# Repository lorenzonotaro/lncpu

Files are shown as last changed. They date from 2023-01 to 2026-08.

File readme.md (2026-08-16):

# lncpu

LNCPU is a design for a hobby 8-bit processor. 

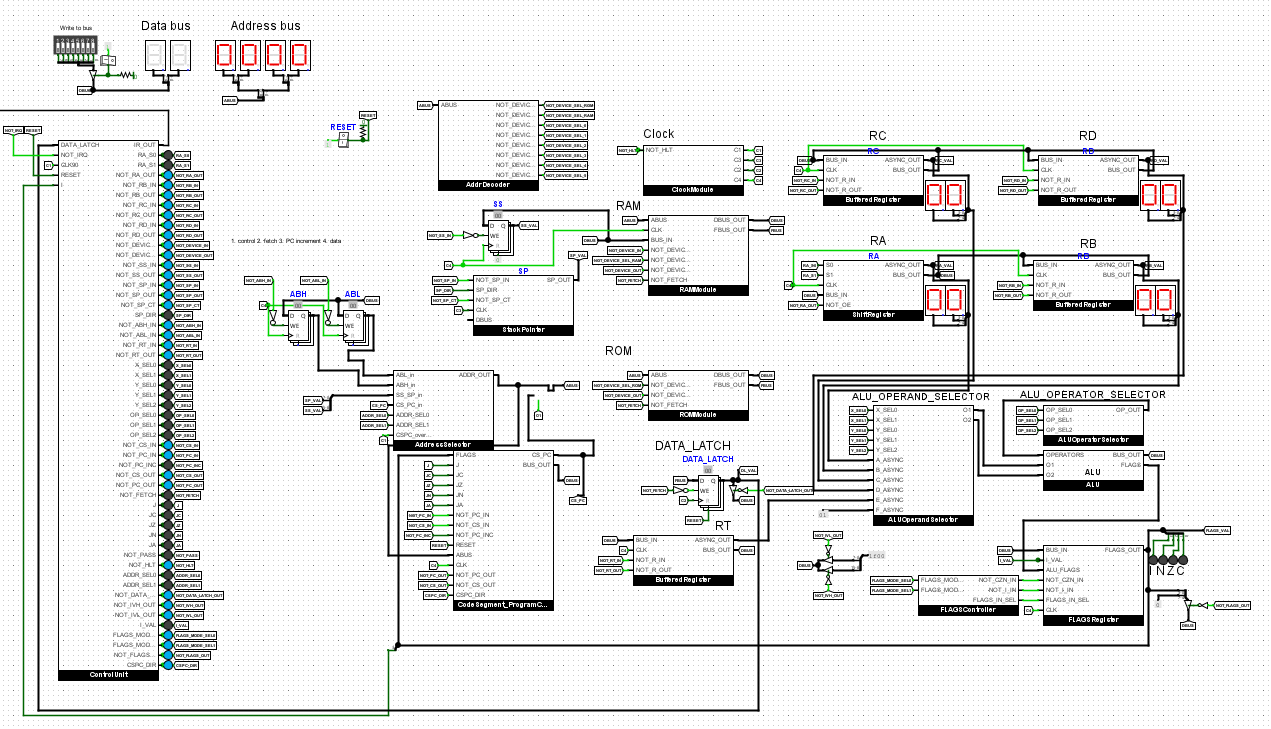
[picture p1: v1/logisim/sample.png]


## Project structure

Overview of the repository:
* [`v1`](v1) is the first implementation of the lncpu. Here you will find the Logisim simulation and the KiCad project (currently under construction), as well as the Python script for generating the control unit EEPROMS.

* [`lnc`](lnc) is an assembler and C compiler written in Java for the lncpu. It is kept up to date with the current implementation.

* [`eeprom-serial-loader`](eeprom-serial-loader) is a utility program for editing binary data and loading it to/from EEPROMS.

* [`lncpu-emu`](lncpu-emu) is a simple emulator for the lncpu written in C.

* [`lnfsutils`](lnfsutils) is a utility program for working with the lnfs filesystem, a simple FS designed to work on the lncpu.

* [`Programs`](Programs) contains some sample programs you can assemble and run on the lncpu as well as Notmon, a utility program strongly inspired in its functionality (and name) by Wozmon, made by Steve Wozniak for his Apple I.

* [`extras`](extras) contains some additional tools, such as a VsCode extension for lnasm.

## Current state of the project

* **Physical implementation**: work in progress. The Logisim simulation is basically done and tested. Some adjustments to the architecture may still be made, but the main design is complete. The KiCad project is under construction, and it might be necessary to properly simulate the design with actual hardware simulation software (e.g. an HDL simulation) before implementing it physically.

* **Assembler and C compiler**: the assembler is basically complete and stable. The C compiler is still a work in progress, but it is already usable for small-medium sized programs. Arrays and structs are yet to be implemented. The register allocator is very basic and can be improved and general optimization passes in the various stages would be very beneficial for an inefficient architecture like this one.

* **EEPROM editor and loader**: the utility is basically complete and stable. Some improvements can be made to the UI, but it is already usable. More loaders other than the AT28C64 can be added.

* **Emulator**: The emulator is also basically done, but it is very basic and can be improved a lot. It is currently Windows-only because of the use of `<conio.h>` for keyboard input, but porting it to Linux or MacOS should be easy.

* **Programs**: A simple BIOS for the lncpu is under development. Notmon is basically complete and stable, but more features can be added.

* **Extras**: The VsCode extension has syntax highlighting and basic symbol support for lnasm files. More features can be added, such as code snippets and integration with lnc.

## Building

### Prerequisites

- [Maven](https://maven.apache.org/) and [JDK 16+](https://www.oracle.com/java/technologies/javase/jdk16-archive-downloads.html) are required for building both `lnc` and `eeprom-serial-loader`.
- [Python 3.x](https://www.python.org/downloads/) is required to generate the EEPROMs for the control unit.
- [Logisim-evolution](https://github.com/logisim-evolution/logisim-evolution) is used to simulate the design.
- Any C compiler and [CMake](https://cmake.org/) to build the emulator (e.g. `gcc`).

**Note**: I suggest using [my fork of Logisim-evolution (logisim-lncpu branch)](https://github.com/lorenzonotaro/logisim-evolution/tree/lncpu-debugger-logisim) to open the Logisim project. It includes useful features like:
- testing environment for the lncpu
- easy loading of all CU EEPROMs at once
- a neat LNCPU debugger

If you're on Linux, `make.sh` will build everything for you. Usage:

    ./make.sh [--no-eeproms] [--no-eeprom-serial-loader|--no-esl] [--no-lnc] [--no-lnfs|--no-lnfs-utils]

If you're on Windows, use `make.bat` instead. Usage:

    ./make.bat [--no-eeproms] [--no-eeprom-serial-loader|--no-esl] [--no-lnc] [--no-lnfs|--no-lnfs-utils]

These scripts will create an `output` folder containing:
- `lnc.jar`: the assembler and C compiler along with `lnc.bat`/`lnc.sh` scripts for easy usage
- `eeprom-serial-loader.jar`: the EEPROM editing and loading utility along with `eeprom-serial-loader.bat`/`eeprom-serial-loader.sh` scripts for easy usage
- `lncpu-emu.exe`: the LNCPU emulator executable
- `eeproms`: a folder containing all the generated control unit EEPROMs (if you have my fork of Logisim, you may open the Logisim project, then go to Simulate -> Debug LNCPU -> Load CU EEPROMS and select this folder to load them all at once).
- a `lib` folder containing libraries for lnc/lnasm

It is recommended to add the `output` folder to your PATH environment variable for easy usage of `lnc` and `eeprom-serial-loader` from any location and allow the Logisim debugger to compile and load programs directly.

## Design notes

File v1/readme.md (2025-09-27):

 _This page is a work in progress._

# lncpu v1

v1 is the current implementation of the lncpu.

## Clock cycle

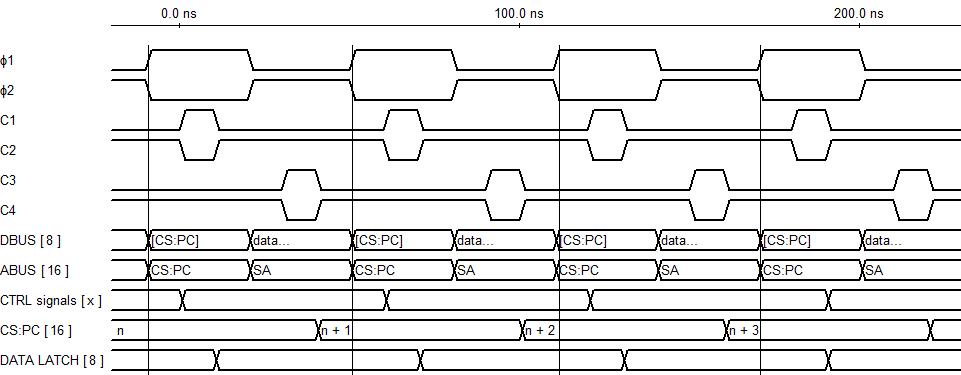
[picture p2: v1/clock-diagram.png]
Clock diagram


The clock cycle is divided in two phases: Φ1 (control phase) and Φ2 (data phase).

* During Φ1, the data bus contains the contents of `[CS:PC]`: only the device mapped to the memory section containing address `CS:PC` is allowed to write to the data bus, regardless of control signals.

* During Φ2, bus control is determined by the control signals of the current microinstruction.

Each phase has a clock pulse entirely within it, and components may synchronize at the rising edge or the falling edge of each clock pulse.

From Φ and the base clock, 4 rising edges are derived:
* **C1** (Φ1), _control_: the next instruction or microinstruction is loaded and the control signals are stabilized.
* **C2** (Φ1), _fetch_: if required by the current microinstruction, data is moved from `[CS:PC]` to the data latch register via the data bus.
* **C3** (Φ2), _data_: data is transferred between the activated components via the data bus.
* **C4** (Φ2), _increment_: counters such as `CS:PC`, `SP` are incremented/decremented as specified by the current microinstruction.

# Pipeline

The implementation uses a very simple pipeline to spare a few clock cycles.

1. At the beginning of the first clock cycle of any instruction (i.e. when Φ1 goes high), the following conditions are required: 

    * `Data latch (DL)` must contain the **value of the instruction about to be executed**.
    * `CS:PC` must contain the the address of the byte **after the opcode about to be executed**.

*Every instruction (including break, jump and call instructions) must pass to the next with this configuration*.

2. During the execution of the instruction:

    1. `Data latch (DL)` will be loaded with the value pointed to by `CS:PC` (i.e. either the next opcode or the next byte to be fetched by the instruction), then
    2. `CS:PC` will be incremented to point to the byte that will be fetched during the next clock cycle.

# General purpose registers
The CPU has 4 general-purpose 8-bit registers, named `RA`, `RB`, `RC`, and `RD`. These registers can be used to store data and are used by most instructions.

Some registers have special purposes:
* `RA` has left and right shift capabilities, and is used by the `shl` and `shr` instructions.
* `RC` and `RD` are used in combination with the `ircrd` addressing mode to read and write data from the address space.
* `RD` is the only register that can be used to read and write dynamic data to and from `SS`, `SP` and `BP` registers (this is due to the limited number of opcodes available with a 1-byte instruction).

# Jump instructions
The CPU supports several jump instructions that allow the program to change the flow of execution. Each instruction (except `lcall`) is available in two variants, a short and a long variant. The short variant uses a 1-byte immediate value as the target address and loads it into `PC` (without touching `CS`), while the long variant uses a 2-byte absolute address as the target address and loads it into `CS:PC`. 
Short jumps require one less clock cycle than long jumps, so they are preferred when the target address is known at compile time and is within the same code segment as the jump instruction.

The jump instructions are:
| Instruction | Short variant | Long variant | Description |
|---|---|---|---|
| Go to | `goto` | `lgoto` | Jumps to the specified address. |
| Jump if carry | `jc` | `ljc` | Jumps to the specified address if the carry flag is set. |
| Jump if zero | `jz` | `ljz` | Jumps to the specified address if the zero flag is set. |
| Jump if negative | `jn` | `ljn` | Jumps to the specified address if the negative flag is set. |
| Call | *not available* | `lcall` | Jumps to the specified address and pushes the current `CS:PC` onto the stack. |

# ALU and FLAGS

The CPU has a simple arithmetic logic unit (ALU) that can perform basic arithmetic and logical operations. The ALU can perform the following operations:
| Operation | Description |
|---|---|
| `add` | Adds the contents of two registers or a register and an immediate value. |
| `sub` | Subtracts the contents of two registers or a register and an immediate value. |
| `and` | Performs a bitwise AND operation on the contents of two registers or a register and an immediate value. |
| `or` | Performs a bitwise OR operation on the contents of two registers or a register and an immediate value. |
| `xor` | Performs a bitwise XOR operation on the contents of two registers or a register and an immediate value. |
| `not` | Performs a bitwise NOT operation on the contents of a register. |
| `shl` | Shifts the contents of a register left by 1 bit (multiplying by 2). Only available for `RA`. |
| `shr` | Shifts the contents of a register right by 1 bit (dividing by 2). Only available for `RA`. |
| `inc` | Increments the contents of a register by 1. |
| `dec` | Decrements the contents of a register by 1. |

The ALU also sets the `FLAGS` register based on the result of the operation. The `FLAGS` register is a 4-bit register that contains the following flags (least significant bit first):
| Flag | Description |
|---|---|
| `C` | Carry flag, set to 1 if the result of an addition or subtraction operation causes an overflow. |
| `Z` | Zero flag, set to 1 if the result of an operation is 0. |
| `N` | Negative flag, set to 1 if the result of an operation is negative (i.e. the most significant bit is set). |
| `I` | Interrupt disable flag, set to 1 if interrupts are disabled (not modified by ALU operations) |

The `CZN` flags can be used to control the flow of the program with conditional jump instructions. The `I` flag is used to enable or disable interrupts, as described in the [Interrupts](#interrupts) section.

The `C` flag can be manually set or cleared with the `sec` (set carry) and `clc` (clear carry) instructions, respectively.

# Address space
The address bus is 16-bits wide, allowing for a total of 65536 bytes of addressable memory. The address space is divided in 8 "devices"; the top 3 bits of the address bus are used to select the device, while the bottom 13 bits are used to select the address within that device.
The address space is divided as follows:
| Device | Address range | Description |
|---|---|---|
| ROM | 0x0000 - 0x1FFF | Read-only memory, points to the extractable chip that can be loaded with a program. |
| RAM | 0x2000 - 0x3FFF | Read-write memory, used for data storage. |
| D0 | 0x4000 - 0x5FFF | Device 1, can be used for any purpose. |
| D1 | 0x6000 - 0x7FFF | Device 2, can be used for any purpose. |
| D2 | 0x8000 - 0x9FFF | Device 3, can be used for any purpose. |
| D3 | 0xA000 - 0xBFFF | Device 4, can be used for any purpose. |
| D4 | 0xC000 - 0xDFFF | Device 5, can be used for any purpose. |
| D5 | 0xE000 - 0xFFFF | Device 6, can be used for any purpose. |

# Stack

The implementation includes a basic stack setup:

* the 8-bit `SS` register contains the page that will contain the stack (i.e. the top 8-bits of the current stack pointer).

* the 8-bit `SP` register points to the **next available stack position** in the stack page.

The top of the stack is pointed to by `SS:SP`. The stack **grows upwards**: `push` operations move a value into `[SS:SP]` and increment the stack by 1; `pop` operations read the value from `[SS:SP]` and decrement the stack by 1.

Calls and interrupts will push the current `CS:PC` onto the stack, so that it can be restored later. It is the programmer's responsibility to load `SS` and `SP` with correct values before using stack manipulation instructions and/or calls, and to ensure that the stack does not overflow, as the implementation does not include any stack overflow checks.

To function properly, the stack obviously needs to be located in a location in the address space that is writable and readable by the CPU (usually in memory, but it can also be in any device that supports reading and writing). See the [Address space](#address-space) section for more information.

The `BP` register points to the base of the current stack frame. It is not updated along with SP, so it can be used to access local variables in the current stack frame. It is the programmer's responsibility to ensure that `BP` is set correctly before using it.
It is used by some instructions to access local variables in the current stack frame, with an addressing mode known as `ibpoffset` (base pointer offset, e.g. `[BP+1]` to access the first local variable in the current stack frame).

# Data segment
The data segment is a 256-byte segment that is used to store frequently used data by some instructions that use `dpage` addressing mode and that require one less clock cycle. 
The `DS` register points to the data segment, containing the top 8-bits of the data segment's start address.
The data segment can be located anywhere in the address space, but it is recommended to place it in the RAM device (0x2000 - 0x3FFF) to ensure that it is writable and readable by the CPU.

# Interrupts
The implementation includes a basic interrupt system that allows the CPU to handle interrupts from devices.

Devices can signal an interrupt by pulling the `~IRQ` line low. Instead of loading the next instruction, at the end of the current instruction, the CPU will push the current `CS:PC` and the current `FLAGS` register value onto the stack and load the `CS:PC` with the value `0x1F00` (the interrupt vector address, last page of ROM). This is the address where the interrupt handler is located, and it is the programmer's responsibility to ensure that the interrupt handler is loaded there.

The interrupt handler is a piece of code that will handle the interrupt and return control to the CPU when it is done via the `iret` instruction.
The interrupt handler must detect which device signaled the interrupt and handle it accordingly and must communicate with that device to acknowledge the interrupt and clear it (otherwise the device will keep signaling the interrupt and the CPU will keep handling it, causing an infinite loop).

Interrupts can be disabled with the `sid` (set interrupt disable) instruction, which will set the `I` flag in the `FLAGS` register to 1. This will prevent the CPU from handling interrupts until the `cid` (clear interrupt disable) instruction is executed, which will clear the `I` flag in the `FLAGS` register to 0.

# Addressing modes
The CPU supports several addressing modes, which determine how the operands of an instruction are accessed. The addressing modes are:
| Addressing mode | Name | Description |
|---|---|---|
| `immediate` | Immediate | The operand is a constant value, specified as an operand to the instruction. |
| `abs` | Absolute | The operand is a 2-byte address of a location in the address space, provided as an operand to the instruction. |
| `dpage` | Data page | The operand is a 1-byte offset (specified as an operand to the instruction) from the data segment, which is specified in the `DS` register. |
| `ibpoffset`  | Stack frame | The operand is a 1-byte offset (specified as an operand to the instruction) from the stack base pointer, which is specified in the `BP` register. |
| `ird` | Data page indirect | Requires no operands, the location is in the data page at the address specified by the contents of the `RD` register. |
| `ircrd` | Full indirect | Requires no operands, the location is specified by the contents of the RC and RD registers.

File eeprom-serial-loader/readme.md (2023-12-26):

# EEPROM Serial Loader
EEPROM Serial Loader is a tool for visualizing and editing binary data.
It also offers the possibility to upload it to a specific EEPROM chip, through the use of an Arduino microcontroller and a custom loader sketch and circuit.

## Opening the project
    
The project uses IntelliJ's UI designer, so it is recommended to use IntelliJ IDEA to open the project.
When using IntelliJ, make sure to enable the option to compile the forms to source code, otherwise it will not work when building with Maven.

## Building

To build and run the project, either run the project as an application in IntelliJ IDEA or use Maven to generate a JAR file:

    mvn package

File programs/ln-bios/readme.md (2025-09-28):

# LN-BIOS

LN-BIOS is a simple BIOS for the LNCPU designed to be OS-agnostic.

It is very lightweight:
1. It sets up the LNCPU
2. It runs device discovery and sets up a basic text IO system (`stdtxt`), that it will expose to the loaded OS.
3. It runs through the devices and looks for a bootable device according to the DDI specification (see below), if found, it transfer control depending on the compile options (**TODO**)

## Building

1. Edit `opts.lnasm` to set the desired options.
2. Run the following command (lnc must be installed in in the system path):

    ```lnc .startup.lnasm -oB ln-bios.bin -oS symbols.syt```

    This will generate a ln-bios.bin file that can be flashed to the LNCPU ROM, and a symbols.syt that contains all exposed symbols that can be used to compile an OS.

## Device discovery interface (DDI)

LN-BIOS will look for devices that implement the DDI specification. The DDI specification is a simple way for devices to expose their functionality to the BIOS and the OS.

LN-BIOS will start by looking at the last 16 bytes of each device's memory space for a DDI signature. If it finds the signature, it will read the DDI header and add the device to the list of discovered devices.

### DDI Header Format
| Bytes  | Description |
|--------|-------------|
| `0xXff0` | `LNDI` (hex: 4C 4E 44 49) - DDI signature |
| `0xXff4` | Version (1 byte) - DDI version (currently 0x1)|
| `0xXff5` | Device Type (1 byte) - Type of device (see below) |
| `0xXff6` | Flags (1 byte) - Device flags (see below) |
| `0xXff7` | Device size in pages (1 byte) - Size of the device in 256-byte pages |
| `0xXff8` | Boot target (2 bytes), or 0x0000 if none |
| `0xXffa` | Pointer to control page, or 0x0000 if none |
| `0xXffc` | Reserved (3 bytes) - Must be 0x0000 |
| `0xXfff` | Control byte (1 byte) : `0xA5` |

### Device Types
Currently supported devices:
| Value | Description |
|-------|-------------|
| **Memory devices**  |
| `0x00`| ROM, 8192 bytes (32 pages) |
| `0x01`| RAM, 8192 bytes (32 pages) |
| **I/O devices** |
| `0x08`| Emulated serial TTY |
| **Address space managers (ASM)** |
| `0x10`| 31x256-byte ASM |
| `0x11`| 15x512-byte ASM |
| `0x12`| 7x1024-byte ASM |

When encountering an ASM device, LN-BIOS will recursively scan the address spaces it manages for more devices (**not implemented yet**).

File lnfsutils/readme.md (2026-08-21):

# lnfsutils

---

`lnfsutils` is a simple utility to work with `lnfs` filesystems (see below for details)

## 1. What is `lnfs`?

`lnfs` is a very, _very_ basic filesystem designed to work reasonably well on the LNCPU.
It is designed to be simple, easy to implement and with minimal storage overhead. Its blocks are variable in size. V1 is designed to be used within a single top-level device.

### 1.1 Filesystem layout
It is structured as follows:

1. The first 12 bytes of the partition are reserved for the superblock, which is structured as follows:

    | Offset | Description                                         |
    |--------|-----------------------------------------------------|
    | `0-3`  | Magic word "LNFS"                                   |
    | `4`    | Version number (currently 1)                        |
    | `5`    | filesystem total size in pages (256 bytes per page) |
    | `6`    | reserved, must be 0                                 |
    | `7`    | max inodes number                                   |
    | `8`    | reserved, must be 0                                 |
    | `9`    | first free inode slot                               |
    | `10`   | flags (see note)                                    |
    | `11`   | magic byte, A5                                      |

    > 
    >     
    > Superblock `flags` is a bitfield currently composed of a single bit:
    >
    >   | Bit | Description             |
    >   |-----|-------------------------|
    >   | 0   | filesystem is read-only |
    >   | 1-7 | reserved/unused         |

2. The superblock is followed by the inode table (or directory table). That is a contiguous array of inodes up to the maximum specified in the superblock. Each inode is structured as follows:

    | Offset  | Description                                                   |
    |---------|---------------------------------------------------------------|
    | `0-7`   | inode name (null-terminated string)                           |
    | `8`     | parent inode index (0 if the inode is root)                   |
    | `9`     | inode flags                                                   |
    | `10-11` | inode block offset from the start of the filesystem, in bytes |
    > Inode `flags` is a bitfield currently composed of:
    > 
    > | Bit | Description            |
    > |-----|------------------------|
    > | 0   | inode slot is occupied |
    > | 1   | inode is a directory   |
    > | 2   | inode is readonly      |
    > | 3   | inode is hidden        |
    > | 4   | inode is root          |
    > | 5   | inode is executable    |
    > | 6-7 | reserved/unused        |
3. The inode table is followed by a doubly linked list of data blocks. Each data block is variable in size, and is structured as follows:

    | Offset    | Description                                                     |
    |-----------|-----------------------------------------------------------------|
    | `0-1`     | pointer to start of previous data block                         |
    | `2-3`     | pointer to start of next data block                             |
    | `4`       | block flags                                                     |
    | `5`       | index of inode that owns this block (or 0 if the block is free) |
    | `6-7`     | size of the data block in bytes, excluding the header (`S`)     |
    | `8-(S+7)` | data (S bytes)                                                  |

    >Block flags is a bitmask currently composed of:
    >
    >   | Bit | Description        |
    >   |-----|--------------------|
    >   | 0   | Block is occupied  |
    >   | 1   | Block is immovable |

For files, the data is simply the file contents.

For directories:
- the first byte contains the number of entries in the directory (`n`).
- the first byte is followed by `n` bytes representing the indices in the inode table of the elements of this directory.

**Note**: the directory content length (including the count byte) must be aligned to 8 bytes (this is to avoid having to move it whenever creating new files).

> All pointers are offsets from the start of the filesystem, in bytes.

### Filesystem Upkeep

* The `first free inode` field in the superblock (bytes 9-10) must be updated whenever the inode table is modified. It must always point to the first free inode slot in the inode table. If there are no free slots, it must be set to `0xFFFF`.
* Whenever an inode is freed (its `free` flag is set), the data block owned by that inode must also be freed.
* The block doubly linked list must be kept valid at all times.
* Defragmentation of both the inode table and the data block list is not required, but it is recommended to keep the filesystem in a good state.

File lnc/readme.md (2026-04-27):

# lnc

LNC is a pseudo-C (see below) compiler and assembler for the `lncpu`.

## Building

Use [`maven`](https://maven.apache.org/) to assemble a runnable JAR with dependencies:

    mvn package

As an alternative, use `make.sh` in the repository root folder to make and install everything in an `/output` folder, which you may then add to your `PATH`.

# Usage

## Command line syntax

To run `lnc`, use:

    java -jar lnc.jar <source file(s)> [options...]

Run with `--help` to show a list of available options.

## The `lnasm` language

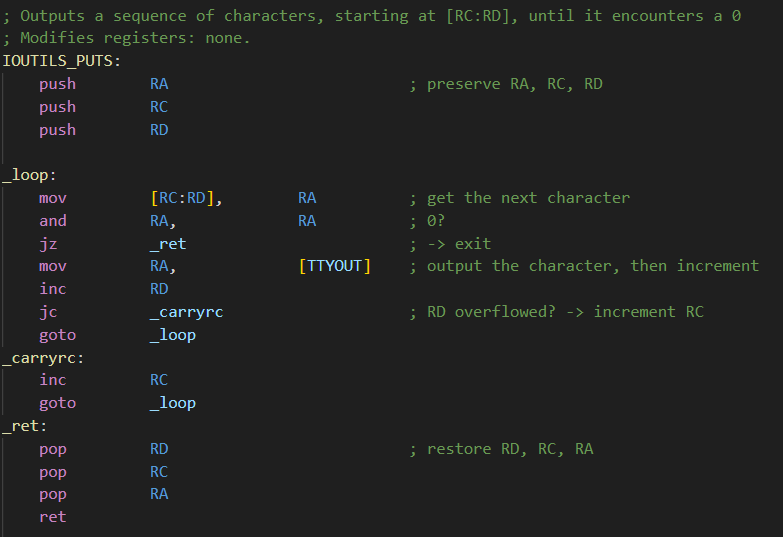
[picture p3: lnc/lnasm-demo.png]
lnasm


`lnasm` is a simple assembly language for the `lncpu`. It is a line-based language, with each line representing a single instruction or directive.

Leading and trailing whitespace in each line is ignored, but each line may contain only one instruction or directive. Instructions and directives are case-insensitive.

`lnasm` code is organized in sections. Each section is a block of code that can be placed in a specific region in the address space. The rules for section placement are defined in a linker configuration script (see [below](#linker-configuration)).

### Order of operands
In `lnasm`, the order of operands is important.

For instructions that copy data, the source operand comes before the destination operand, as in:

    mov 0x42, RA ; move the value 0x42 into the RA register

For instructions that perform arithmetic or logical operations, the operand in which to store the result comes first, followed by the operands to operate on, as in:

    add RA, RB ; add the value in RB to RA and store the result in RA

### Directives

- `.section <section name>`

    Sets the current section. All subsequent instructions will be added to this section, until a new `.section` directive is encountered.
    The section name must match a section defined in the linker configuration script (case-sensitive).
        
        .section CODE           

            mov 0x42,   RA      ; this instruction will be placed in the CODE section

- `.res <n>`

    Adds `n` bytes (zeroes) at the current location.

- `.data <value>[, <value>, ...]`

    Adds the given values at the current location, in the order they are given. Values can be:
  - integers (e.g. `0x42`, `42`, `0b1010`)
  - strings, ASCII-encoded and *not* null-terminated (e.g. `"Hello, world!"`)
  - characters, ASCII-encoded (e.g. `'A'`)

### Preprocessor directives

`lnasm` provides a very basic preprocessor, with the following directives:

- `%define <identifier> [<value>]`

    Defines a macro with the given identifier and value, such that the identifier will be replaced with the given value.

- `%undefine <identifier>`

    Undefines a previously defined macro.

- `%ifdef <identifier> ... %endif`

    If the given identifier is defined, the code following this directive will be included in the output. Otherwise, it will be ignored.

- `%ifndef <identifier> ... %endif`

    If the given identifier is not defined, the code following this directive will be included in the output. Otherwise, it will be ignored.

- `%ifdef SECTION <section> ... %endif`

    If a section with the given name exists, the code following this directive will be included in the output. Otherwise, it will be ignored.

- `%ifndef SECTION <section> ... %endif`

    If a section with the given name does not exist, the code following this directive will be included in the output. Otherwise, it will be ignored.

- `%include "<filename>"`

    Parses and copies the content of the given file into the current file, at the directive's location.

    **Warning**: there is no check for circular dependencies or re-includes. Be careful. The safest option is to use a C-style include guard:

      %ifndef _MY_FILE_INCLUDED
      %define _MY_FILE_INCLUDED

        ; your code here

      %endif

### Labels and sublabels

Every instruction or directive (except `.section`) can be preceded by a label:

    LABELNAME:
        inc         RA
        goto        LABELNAME

Labels starting with `_` are interpreted as sublabels (if preceded by a label that does NOT start with `_`). They can only be referenced by code in the same top-level label.

    A:
        mov         [0x01],     RC
    _sub15:
        sub         RC,         15

    B:
        goto        _sub15          ; <---- ERROR!             

When used, labels are evaluated as:

* `dcst` (16-bit words) if they point to a non-data page section.
* `cst` (byte) if they point to a data page section.

*Note*: section names can be referenced just like labels. They always evaluate to the start of the section as specified in the linker configuration (`dcst`), even if the section is a data page section.

### Expressions

Lnasm supports basic arithmetic and logic binary operators. In order of decreasing precedence:

1. multipication (`*`) and division (`/`)
2. addition (`+`) and subtraction (`-`)
3. left (`<<`) and right (`>>`) bitwise shift
4. bitwise logic OR (`|`), AND (`&`) and XOR (`^`)

Parethesis can be used to clarify expressions.

Valid operands for binary operator are:

* 8-bit (`cst`) and 16-bit (`dcst`) values.
* labels

**Note**: expressions preserve the type (byte or word) of the left operand. You may need to [cast](#Casts) to the desired type.

### Casts

The cast operator `::` allows you to trucate 16-bit words to 8-bit values and to extend 8-bit values to 16-bit words. 

The cast operator has the highest precedence, second only to primary expressions (identifiers, constant values, string literals).

Examples:

    ; 0xFF::16, 0xFF::word evaluate to 0x00FF
    ; 0x1234::8, 0x1234::byte evaluate to 0x34

    ; You can combine binary operators and casts.
    ; The following example loads RC:RD with the label SUBROUTINE and then calls it

    ...

    mov     (SUBROUTINE >> 8)::byte, RC
    mov     (SUBROUTINE & 0xFF)::byte, RD ; The & operator is not really necessary since the cast operator truncates the 8 MSB
    lcall   RC:RD

    ...

    .section OTHER_CODE
    SUBROUTINE:
        ...
        ret

### Comments

Comments can be initiated with `;`: the remainder of the line after the semicolon will be ignored by the parser.

### Instruction set

Consult the [instruction set reference](instructionset.md) for the available instructions.

### Linker configuration
In order to successfully assemble a program, you must provide a **linker configuration script**.
A linker configuration script tells the linker information about each code section,
such as what device it belongs to, how to place it in the address space (see below), etc...

You can provide a linker configuration file via the command line:

    java -jar lnasm.jar <source file(s) -lf <linker cfg file>

Or you can provide the configuration script in the command line:

    java -jar lnasm.jar <source file(s) -lc "<configuration script>"

If no options are provided, lnasm looks for a file called `linker.cfg` in the current working directory.

The format of a configuration script is as follows:

    SECTIONS[
      <section name>: property1 = value1, property2 = value2, ...;
      ...
    ]

Each section name must be unique, may contain letters, numbers and underscores and cannot start with a digit.

Use the following properties to define a section:

* `mode`: the placement mode of the section. Possible values are:
  * `fixed`: the section is placed at a fixed address. You must specify the start address using the `start` property.
  * `page_align`: the section is placed at the first available address that is page-aligned (`xx00`). You must specify the target device using the `target` property.
  * `page_fit`: the section is placed at the first available address that fits its size and so that the section does not cross a page boundary. You must specify the target device using the `target` property.
  * `page_fit_labels`: the section is placed at the first available address that fits its size and so that all top-level labels in the section do not cross a page boundary. You must specify the target device using the `target` property.
  * `fit`: the section is placed at the first available address that fits its size, regardless of page boundaries. You must specify the target device using the `target` property.
* `target`: the target device for the section. This property is mandatory for `page_align`, `page_fit` and `fit` sections. One of `ROM`, `RAM`, `D0` through `D5`.
* `datapage`: if present, indicates that the section represents a data page. All labels in this section will evaluate to a `cst` (byte) value.
* `virtual`: only applicable to a `datapage`. If present, the section will not be placed in the address space. It may be used as a dynamic data page, whose address is determined at runtime via the `DS` register.
* `multi`: if present, the section can be referenced multiple times. Each 'block' will be appended to the final binary. This is useful for data pages, as each module can reserve its own space in the data page.

Example:

    SECTIONS[
      STARTUP_CODE: mode = fixed, start = 0x0000;
      PROGRAM: mode = page_fit, target = ROM;
      DATA_PAGE: mode = page_align, target = RAM, datapage;
    ]

## The lnc language

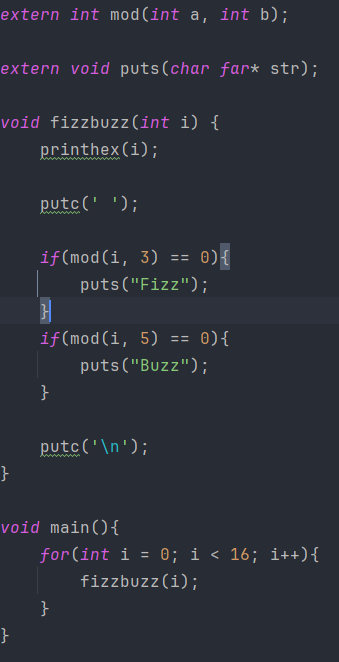
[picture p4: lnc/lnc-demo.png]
lnc


lnc is a C-like language that compiles to lnasm.
The compiler is still very rudimental and produces *very* unoptimal code.

lnc is (and probably will never be) neither C-standard compliant nor a simple subset of C: some features of the lnc architecture (such as the existence of different memory addressing modes, data page and absolute) require some extra features that C doesn't provide on its own.

(This is the main reason why I didn't simply build a backend for an existing compiler such as `clang/llvm`; it would have been very challenging if not outright impossible.)

### Features

 - [x] Basic arithmetic expressions (currently add/sub)
 - [x] Basic flow control (for, while, if/else)
 - [ ] Other forms of flow control (switch)
 - [x] Continue and break statements 
 - [x] Data page variables and pointers
 - [x] Absolute variables and pointers
 - [x] Data page arrays
 - [x] Absolute arrays
 - [x] Structs
 - [ ] Unions
 - [ ] Varargs

### Calling convention

#### Parameters

The calling convention for functions in `lnc` allows for up to 4 1-byte paramters and 2 2-byte parameters to be passed in the general purpose registers `RA`, `RB`, `RC` and `RD`. If more than 4 parameters are needed, the remaining parameters must be passed via the stack. Specifically:
- if the callee doesn't require any 2-byte parameters, the first 4 parameters are passed in `RA`, `RB`, `RC` and `RD`; the remaining parameters are passed on the stack, __in reverse order (*)__.
- if the callee requires a 2-byte parameter, such parameter is passed in `RC:RD`; `RA` and `RB` are used for the first two 1-byte parameters, while the remaining parameters are passed on the stack, __in reverse order (*)__.

__(*) Reverse order:__ Values are pushed right to left so that, from the callee's perspective, later parameters are further away from the base pointer (BP).

In case any parameters are passed on the stack, the *callee* is responsible for clearing the stack (including its parameters) before returning. This can be easily done by using the `ret <stack size>` instruction, specifying the number of bytes to pop from the stack after the function returns.

#### Variadic functions

Variadic functions behave a little differently than regular functions.
- All parameters that can be passed onto registers follow the rules above;
- Fixed parameters on the stack are NOT supported; the stack is exclusively used for the variadic parameters.
- Variadic parameters are passed in reverse order.
- Since the callee cannot know how many variadic parameters are passed, stack cleanup is **the caller's responsibility** (only case).

The callee can use the `va_pop(<type>)` function to pop a variadic parameter. Each parameter can be popped exactly once; they are popped in the declaration order.

Example:
```C
  int add(int count, ...){
    int sum = 0;
    for(int i = 0; i < count; i++){
      sum += va_pop(int);
    }
    return sum;
  }
  
  void main(){
    int sum = add(3, 10, 20, 30);
  }
```

#### Return values
If the function returns a 1-byte value, it is returned in the `RB` register. If the function returns a 2-byte value, it is returned in the `RC:RD` registers.

#### Register preservation
The calling convention requires that the *callee* preserves the values of any registers it uses, except for the register(s) used to return a value (`RB` or `RC:RD`, see above).

#### Interfacing with lnasm

To inform the C compiler of the existence of an `lnasm` function that will be linked with the compiler output, you may declare it as `extern`.
In the lnasm code, the function must follow lnc's calling convention and register preservation.
Example:
```C
    //lnc:
    extern int doublei(int i);
```
The function code in lnasm could then be:
```
    doublei:
        mov     RA,     RB ; move RA to the return register
        add     RB,     RB ; double the value in RB
        ret
```
The same goes the other way around:
```c
    int doublei(int i){
        return i + i;
    }
```
```
    mov     15,             RA
    lcall   doublei
    ; at this point RB will contain 30

```

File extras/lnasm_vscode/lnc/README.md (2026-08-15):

# LNASM / LNC for Visual Studio Code

Language support for LNASM and LNC, plus an inline `lncpu` debugger that compiles source files and controls `lncpu-emu` through LNDBG v1.

## Language features

- Syntax highlighting for `.lnasm`, `.lnc`, and `.lnh` files.
- LNASM label, sublabel, macro, and section indexing.
- Definitions, hovers, workspace symbols, and opcode documentation.
- Ctrl/Cmd-click navigation from current-build labels and sections to their resolved memory addresses.
- Source breakpoints in LNASM and LNC files.

## Debugging

Create `.vscode/launch.json`:

```json
{
  "version": "0.2.0",
  "configurations": [
    {
      "type": "lncpu",
      "request": "launch",
      "name": "Debug LNCPU program",
      "cwd": "${workspaceFolder}",
      "lncPath": "${workspaceFolder}/tools/lnc.jar",
      "javaPath": "java",
      "emulatorPath": "${workspaceFolder}/build/lncpu-emu",
      "sourceFiles": [
        "src/main.lnc",
        "src/start.lnasm"
      ],
      "compilerOptions": ["-lf", "linker.cfg", "-oD=ROM,RAM,D0"],
      "deviceImages": {
        "D0": "assets/d0.bin",
        "D2": "assets/d2.bin"
      },
      "emulatorOptions": []
    }
  ]
}
```

All relative paths are resolved from `cwd`. `lncPath` may name a JAR, launched with `javaPath`, or a directly executable compiler.

Before each launch, the extension compiles `sourceFiles`. It uses `.lncpu-debug/program.bin`, `.lncpu-debug/program.lndbg.json`, and `.lncpu-debug/program.immediate.txt` unless `compilerOptions` supplies `-oB`, `-oG`, and `-oI`. Split (`-oI file.txt`) and equals (`-oI=file.txt`) forms are supported. If `-oD` is omitted, `ROM` is requested. `ROM`, `RAM`, and `D0` through `D5` outputs are passed to the corresponding emulator options; non-ROM output names use lnc's `_RAM` or `_D0`-`_D5` suffix. `-s` is rejected because debugging requires a binary.

`deviceImages` accepts explicit `ROM`, `RAM`, and `D0` through `D5` image paths, resolved relative to `cwd`. An external image replaces the emulator image for the same `-oD` target without changing compiler output generation; a target absent from `-oD` is added after compiler targets in `ROM`/`RAM`/`D0`-`D5` order. The emulator receives exactly one image option per target. Raw image options such as `--rom`, `--ram`, and `--d0` remain invalid in `emulatorOptions`.

### Memory Inspector symbol navigation

Install the Eclipse CDT Memory Inspector extension, then add `lncpu` to its supported debug types in user settings. Preserve any existing entries:

```json
"memory-inspector.debugTypes": ["lncpu"]
```

During an active `lncpu` launch, the version 1 `-oG` debug map supplies complete physical section and label metadata across `ROM`, `RAM`, and `D0` through `D5`, independently of `-oD`. Navigation exposes compiler symbols only for `-oD` targets not replaced by `deviceImages`. External images never infer source maps: replaced or externally added targets expose no compiler symbols, legacy immediate-listing symbols, or RAM Variables, while unaffected compiler targets remain navigable. Virtual sections, labels attached to virtual or unknown sections, and symbols in unloaded targets retain normal source-definition navigation. Labels take precedence over same-named sections.

When RAM is loaded, eligible top-level RAM labels also appear under the debugger's `RAM` Variables scope. Each variable spans from its label address to the next distinct top-level label in the same physical section, or to that section's emitted end. Sublabels are omitted. These Variables entries include memory references and byte lengths so Memory Inspector can open them from its Variables context menu.

For compatibility with older version 1 debug maps that have no `sections` field, the extension falls back to `-oI` and reads the base listing plus each requested target's `_RAM` or `_D0`-`_D5` suffixed listing. A present `sections` table, including an empty one, is authoritative and does not require immediate-listing files. Navigation also falls back to the source definition when no `lncpu` session is active. A Memory Inspector installation or configuration error is reported rather than silently falling back.

The emulator is always launched with `--debug-server --stop-on-entry --nopauseonhalt`. The extension waits for `LNDBG-LISTEN`, connects only to localhost, and requires LNDBG protocol version 1 or newer.

Supported debugger operations:

- Exact-or-next-line source breakpoints from debug map v1.
- Continue, pause, step in, step over, and step out. These actions are hardware instruction-level operations because LNDBG v1 exposes CPU instruction stepping, not source-level stepping.
- One synthetic LNCPU thread and source-mapped stack frame.
- Register inspection and editing.
- Top-level labels for loaded RAM images in the RAM Variables scope.
- Memory reads and writes from the VS Code memory viewer.
- Clean terminate and disconnect.

Attach sessions, conditional breakpoints, expression evaluation, and source locals are not supported by LNDBG v1 and are intentionally omitted.

## Development

```sh
npm install
npm test
```

`npm test` compiles the strict CommonJS TypeScript project and runs focused protocol, debug-map, artifact-planning, and hermetic lifecycle tests.

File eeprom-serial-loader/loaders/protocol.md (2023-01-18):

# Serial protocol

## 1. General information
A loader is a program running on a serial device that will communicate with the desktop application and will load the data onto the target chip (each loader is specific to the chip, since they may require different wiring).

The serial protocol was built around Arduino Nano, so the Arduino environment is the easiest choice. That said, the protocol can work with any microcontroller with a serial port.

The loader is the interface between the client and the EEPROM chip. It needs to be able to write and read from the EEPROM and send/receive data accordingly.

In its default state, the loader must be constantly waiting for requests from the serial port.
As explained below, since most microcontrollers have a very limited amount of memory, the exchange of EEPROM data from and to the loader will happen in smaller blocks, or payloads, of a size determined by the loader.

## 2. Serial parameters & info
* The baud rate must be `115200` (the highest baud rate supported by Arduino Nano).
* The other serial parameters are the default parameters of Arduino: `8 data bits`, `no parity`, `1 stop bit`.
* The loader must also have a 1-second read timeout when expecting data or confirmation from the client, but not during the default state of listening for requests.
* Whenever a fixed number of bytes is exchanged between the loader and the client (e.g. a 2-byte unsigned integer, see parameters), the data must be sent in Big Endian order.
## 3. Requests
The loader must be listening for requests sent by the client application. These requests are in the form of a single ASCII character.

#### 3.1 `'v' (0x76)`: Signature and version
This is the first request a newly connected client will make.

The loader must respond with the following data (in order):
1. the protocol signature string `EEPROMLD` (8 bytes), allowing the client to identify the device as a valid loader.
2. a null-terminated string containing the name and version of the loader. 

#### 3.2 `'p'` (0x70): Parameters
This request usually follows the signature request. Before any uploading is done, the client needs to know:
 * the maximum read/write length of the loader: the amount of memory that the loader is capable of addressing in the EEPROM (ideally the size of the EEPROM); the client will use this number to notify the user when they're writing past the limit of the loader.
 * the payload size: the size of each block containing EEPROM data. When writing and reading, the client will know how may blocks to expect by calculating `(maximum read-write length)/(payload size)`.

The loader must respond with the following data (in order):
1. The maximum read/write length in bytes, expressed as a 2-byte unsigned integer.
2. The payload size in bytes, expressed as a 2-byte unsigned integer.

#### 3.3 `'r'` (0x72): Read
The client is requesting the contents of the EEPROM.

The loader must enter the read state: any request character sent during this period must not be considered.

At this point the loader must perform a number of read cycles equal to `(maximum read-write length)/(payload size)`.

A read cycle consists of the following steps:
1. The loader must wait for the client to send the control character `'n'` (0x6E)', meaning that the client is ready to receive the next payload. If the byte read is different than `'n'` (0x6E)' or if the timeout (1 second) is reached the loader must send a `'!'` (0x21) character and return to its default state.
2. The loader must send a number of bytes equal to the payload size, corresponding to the current payload.

No additional data needs to be sent after the last read cycle.

#### 3. `'w'` (0x77): Write
The client is requesting to write to the EEPROM.

The loader must enter the write state: any request character sent during this period must not be considered.

At this point the loader must perform a number of write cycles equal to `(maximum read-write length)/(payload size)`.

A write cycle consists of the following steps:
1. The loader must send the control character `'n'` (0x6E)', meaning that it is ready to receive the next payload. If any other byte is sent or if the client reaches the timeout (1 second), the client will consider the write attempt failed and the loader must return to its default state.
2. The loader must read a number of bytes equal to the payload size, corresponding to the current payload.

After the last write cycle, the loader shall send the control character `'k'` (0x6B), signaling that the write procedure ended successfully, and then return to its default state.

**Note:** the client may perform a read request immediately after the termination of the write request in order to check the EEPROM contents.

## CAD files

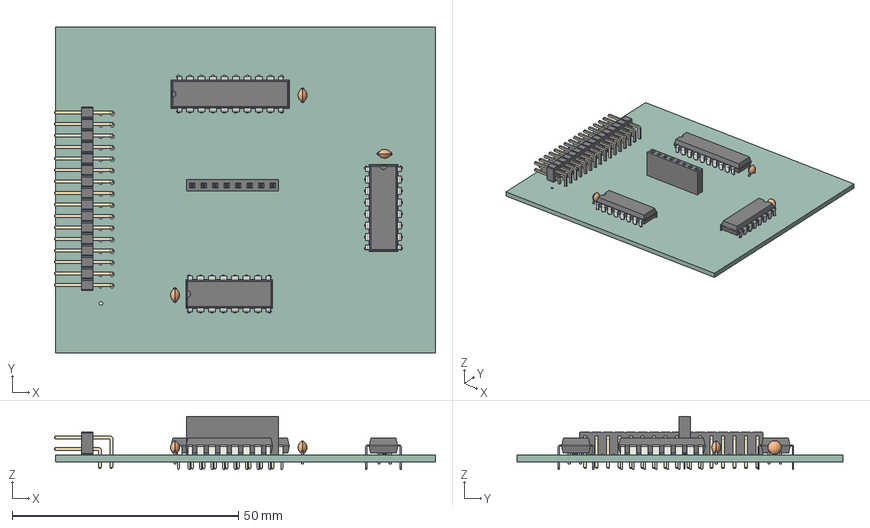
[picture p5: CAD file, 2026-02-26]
v1/kicad/register/register.step
84.2 x 72.0 x 11.8 mm
DIP-20_W7.62mm
PinHeader_2x16_P2.54mm_Horizontal
C_Disc_D3.0mm_W2.0mm_P2.50mm x 3
DIP-16_W7.62mm x 2
PinSocket_1x08_P2.54mm_Vertical
register_PCB

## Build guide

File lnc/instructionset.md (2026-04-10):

### lnasm instruction set

| Opcode | Syntax | Description | Clock cycles | Flags Affected |
|---|---|---|---|---|
| 00 | `nop ` | No operation | 1 | - |
| 01 | `hlt ` | Halts the CPU | 1 | - |
| 02 | `$brk$ ` | Reserved opcode (hardware interrupt). Do not use. | 7 | `I` |
| 03 | `int ` | Software interrupt. Pushes CS:PC and FLAGS, then calls the interrupt vector | 7 | `I` |
| 04 | `mov <byte>,	RA` | Moves a constant to RA | 2 | - |
| 05 | `mov <byte>,	RB` | Moves a constant to RB | 2 | - |
| 06 | `mov <byte>,	RC` | Moves a constant to RC | 2 | - |
| 07 | `mov <byte>,	RD` | Moves a constant to RD | 2 | - |
| 08 | `mov <byte>,	SP` | Moves a constant to SP | 2 | - |
| 09 | `mov <byte>,	SS` | Moves a constant to SS | 2 | - |
| 0a | `mov <byte>,	DS` | Moves a constant to DS | 2 | - |
| 0b | `mov <byte>,	BP` | Moves a constant to BP | 2 | - |
| 0c | `mov SS,	RD` | Moves SS to RD | 1 | - |
| 0d | `mov SP,	RD` | Moves SP to RD | 1 | - |
| 0e | `mov SP,	BP` | Moves SP to BP | 1 | - |
| 0f | `mov BP,	SP` | Moves BP to SP | 1 | - |
| 10 | `mov DS,	RD` | Moves DS to RD | 1 | - |
| 11 | `mov RA,	RB` | Moves RA to RB | 1 | - |
| 12 | `mov RA,	RC` | Moves RA to RC | 1 | - |
| 13 | `mov RA,	RD` | Moves RA to RD | 1 | - |
| 14 | `mov RB,	RA` | Moves RB to RA | 1 | - |
| 15 | `mov RB,	RC` | Moves RB to RC | 1 | - |
| 16 | `mov RB,	RD` | Moves RB to RD | 1 | - |
| 17 | `mov RC,	RA` | Moves RC to RA | 1 | - |
| 18 | `mov RC,	RB` | Moves RC to RB | 1 | - |
| 19 | `mov RC,	RD` | Moves RC to RD | 1 | - |
| 1a | `mov RD,	RA` | Moves RD to RA | 1 | - |
| 1b | `mov RD,	RB` | Moves RD to RB | 1 | - |
| 1c | `mov RD,	RC` | Moves RD to RC | 1 | - |
| 1d | `mov RD,	SS` | Moves RD to SS | 1 | - |
| 1e | `mov RD,	SP` | Moves RD to SP | 1 | - |
| 1f | `mov RD,	DS` | Moves RD to DS | 1 | - |
| 20 | `mov [BP +/- <offset>],	RA` | Copies a from a location in the address space (stack frame offset addressing mode) to RA | 4 | - |
| 21 | `mov [BP +/- <offset>],	RB` | Copies a from a location in the address space (stack frame offset addressing mode) to RB | 4 | - |
| 22 | `mov [BP +/- <offset>],	RC` | Copies a from a location in the address space (stack frame offset addressing mode) to RC | 4 | - |
| 23 | `mov [BP +/- <offset>],	RD` | Copies a from a location in the address space (stack frame offset addressing mode) to RD | 4 | - |
| 24 | `mov RA,	[BP +/- <offset>]` | Copies RA to a location in the address space (stack frame offset addressing mode) | 4 | - |
| 25 | `mov RB,	[BP +/- <offset>]` | Copies RB to a location in the address space (stack frame offset addressing mode) | 4 | - |
| 26 | `mov RC,	[BP +/- <offset>]` | Copies RC to a location in the address space (stack frame offset addressing mode) | 4 | - |
| 27 | `mov RD,	[BP +/- <offset>]` | Copies RD to a location in the address space (stack frame offset addressing mode) | 4 | - |
| 28 | `mov <byte>,	[BP +/- <offset>]` | Copies a constant to a location in the address space (stack frame offset addressing mode) | 5 | - |
| 29 | `mov RA,	[<data page address>]` | Copies RA to a location in the address space (data page addressing mode) | 2 | - |
| 2a | `mov RB,	[<data page address>]` | Copies RB to a location in the address space (data page addressing mode) | 2 | - |
| 2b | `mov RC,	[<data page address>]` | Copies RC to a location in the address space (data page addressing mode) | 2 | - |
| 2c | `mov RD,	[<data page address>]` | Copies RD to a location in the address space (data page addressing mode) | 2 | - |
| 2d | `mov [<data page address>],	RA` | Copies from location in the address space (data page addressing mode) to RA | 2 | - |
| 2e | `mov [<data page address>],	RB` | Copies from location in the address space (data page addressing mode) to RB | 2 | - |
| 2f | `mov [<data page address>],	RC` | Copies from location in the address space (data page addressing mode) to RC | 2 | - |
| 30 | `mov [<data page address>],	RD` | Copies from location in the address space (data page addressing mode) to RD | 2 | - |
| 31 | `mov <byte>,	[<data page address>]` | Copies a constant to a location in the address space (data page addressing mode) | 3 | - |
| 32 | `mov RA,	[RC:RD]` | Copies RA to a location in the address space (full indirect addressing mode) | 3 | - |
| 33 | `mov RB,	[RC:RD]` | Copies RB to a location in the address space (full indirect addressing mode) | 3 | - |
| 34 | `mov RC,	[RC:RD]` | Copies RC to a location in the address space (full indirect addressing mode) | 3 | - |
| 35 | `mov RD,	[RC:RD]` | Copies RD to a location in the address space (full indirect addressing mode) | 3 | - |
| 36 | `mov [RC:RD],	RA` | Copies from location in the address space (full indirect addressing mode) to RA | 3 | - |
| 37 | `mov [RC:RD],	RB` | Copies from location in the address space (full indirect addressing mode) to RB | 3 | - |
| 38 | `mov [RC:RD],	RC` | Copies from location in the address space (full indirect addressing mode) to RC | 3 | - |
| 39 | `mov [RC:RD],	RD` | Copies from location in the address space (full indirect addressing mode) to RD | 3 | - |
| 3a | `mov <byte>,	[RC:RD]` | Copies a constant to a location in the address space (full indirect addressing mode) | 4 | - |
| 3b | `mov RA,	[<full address>]` | Copies RA to a location in the address space (absolute addressing mode) | 3 | - |
| 3c | `mov RB,	[<full address>]` | Copies RB to a location in the address space (absolute addressing mode) | 3 | - |
| 3d | `mov RC,	[<full address>]` | Copies RC to a location in the address space (absolute addressing mode) | 3 | - |
| 3e | `mov RD,	[<full address>]` | Copies RD to a location in the address space (absolute addressing mode) | 3 | - |
| 3f | `mov [<full address>],	RA` | Copies from location in the address space (absolute addressing mode) to RA | 3 | - |
| 40 | `mov [<full address>],	RB` | Copies from location in the address space (absolute addressing mode) to RB | 3 | - |
| 41 | `mov [<full address>],	RC` | Copies from location in the address space (absolute addressing mode) to RC | 3 | - |
| 42 | `mov [<full address>],	RD` | Copies from location in the address space (absolute addressing mode) to RD | 3 | - |
| 43 | `mov <byte>,	[<full address>]` | Copies a constant to a location in the address space (absolute addressing mode) | 4 | - |
| 44 | `mov [<data page address>],	[<data page address>]` | Copies a location in the address space (data page addressing mode) to another location in the address space (data page addressing mode) | 4 | - |
| 45 | `mov [RD],	RA` | Copies from a location in the address space (short indirect addressing mode) to RA | 2 | - |
| 46 | `mov [RD],	RB` | Copies from a location in the address space (short indirect addressing mode) to RB | 2 | - |
| 47 | `mov [RD],	RC` | Copies from a location in the address space (short indirect addressing mode) to RC | 2 | - |
| 48 | `mov [RD],	RD` | Copies from a location in the address space (short indirect addressing mode) to RD | 2 | - |
| 49 | `mov RA,	[RD]` | Copies RA to a location in the address space (short indirect addressing mode) | 2 | - |
| 4a | `mov RB,	[RD]` | Copies RB to a location in the address space (short indirect addressing mode) | 2 | - |
| 4b | `mov RC,	[RD]` | Copies RC to a location in the address space (short indirect addressing mode) | 2 | - |
| 4c | `mov RD,	[RD]` | Copies RD to a location in the address space (short indirect addressing mode) | 2 | - |
| 4d | `mov <byte>,	[RD]` | Copies a constant to a location in the address space (short indirect addressing mode) | 3 | - |
| 4e | `push RA` | Pushes RA onto the stack | 2 | - |
| 4f | `push RB` | Pushes RB onto the stack | 2 | - |
| 50 | `push RC` | Pushes RC onto the stack | 2 | - |
| 51 | `push RD` | Pushes RD onto the stack | 2 | - |
| 52 | `push [<data page address>]` | Pushes a location in the address space (data page addressing mode) onto the stack | 4 | - |
| 53 | `push [RD]` | Pushes a location in the address space (short indirect addressing mode) onto the stack | 4 | - |
| 54 | `push [RC:RD]` | Pushes a location in the address space (full indirect addressing mode) onto the stack | 5 | - |
| 55 | `push [<full address>]` | Pushes a location in the address space (absolute addressing mode) onto the stack | 5 | - |
| 56 | `push <byte>` | Pushes a constant onto the stack | 2 | - |
| 57 | `push BP` | Pushes the value of BP onto the stack | 2 | - |
| 58 | `push DS` | Pushes the value of DS onto the stack | 2 | - |
| 59 | `pop RA` | Pops from the stack into RA | 1 | - |
| 5a | `pop RB` | Pops from the stack into RB | 1 | - |
| 5b | `pop RC` | Pops from the stack into RC | 1 | - |
| 5c | `pop RD` | Pops from the stack into RD | 1 | - |
| 5d | `pop [<data page address>]` | Pops from the stack into a location in the address space (data page addressing mode) | 3 | - |
| 5e | `pop [RD]` | Pops from the stack into a location in the address space (short indirect addressing mode) | 3 | - |
| 5f | `pop [RC:RD]` | Pops from the stack into a location in the address space (full indirect addressing mode) | 4 | - |
| 60 | `pop [<full address>]` | Pops from the stack into a location in the address space (absolute addressing mode) | 4 | - |
| 61 | `pop BP` | Pops from the stack into BP | 1 | - |
| 62 | `pop DS` | Pops from the stack into DS | 1 | - |
| 63 | `add RA,	RA` | Adds RA to RA, stores the result back in RA, then updates the FLAGS accordingly | 1 | `NZC` |
| 64 | `add RA,	RB` | Adds RB to RA, stores the result back in RA, then updates the FLAGS accordingly | 1 | `NZC` |
| 65 | `add RA,	RC` | Adds RC to RA, stores the result back in RA, then updates the FLAGS accordingly | 1 | `NZC` |
| 66 | `add RA,	RD` | Adds RD to RA, stores the result back in RA, then updates the FLAGS accordingly | 1 | `NZC` |
| 67 | `add RB,	RA` | Adds RA to RB, stores the result back in RB, then updates the FLAGS accordingly | 1 | `NZC` |
| 68 | `add RB,	RB` | Adds RB to RB, stores the result back in RB, then updates the FLAGS accordingly | 1 | `NZC` |
| 69 | `add RB,	RC` | Adds RC to RB, stores the result back in RB, then updates the FLAGS accordingly | 1 | `NZC` |
| 6a | `add RB,	RD` | Adds RD to RB, stores the result back in RB, then updates the FLAGS accordingly | 1 | `NZC` |
| 6b | `add RC,	RA` | Adds RA to RC, stores the result back in RC, then updates the FLAGS accordingly | 1 | `NZC` |
| 6c | `add RC,	RB` | Adds RB to RC, stores the result back in RC, then updates the FLAGS accordingly | 1 | `NZC` |
| 6d | `add RC,	RC` | Adds RC to RC, stores the result back in RC, then updates the FLAGS accordingly | 1 | `NZC` |
| 6e | `add RC,	RD` | Adds RD to RC, stores the result back in RC, then updates the FLAGS accordingly | 1 | `NZC` |
| 6f | `add RD,	RA` | Adds RA to RD, stores the result back in RD, then updates the FLAGS accordingly | 1 | `NZC` |
| 70 | `add RD,	RB` | Adds RB to RD, stores the result back in RD, then updates the FLAGS accordingly | 1 | `NZC` |
| 71 | `add RD,	RC` | Adds RC to RD, stores the result back in RD, then updates the FLAGS accordingly | 1 | `NZC` |
| 72 | `add RD,	RD` | Adds RD to RD, stores the result back in RD, then updates the FLAGS accordingly | 1 | `NZC` |
| 73 | `add RA,	<byte>` | Adds a constant to RA, stores the result back in RA, then updates the FLAGS accordingly | 2 | `NZC` |
| 74 | `add RB,	<byte>` | Adds a constant to RB, stores the result back in RB, then updates the FLAGS accordingly | 2 | `NZC` |
| 75 | `add RC,	<byte>` | Adds a constant to RC, stores the result back in RC, then updates the FLAGS accordingly | 2 | `NZC` |
| 76 | `add RD,	<byte>` | Adds a constant to RD, stores the result back in RD, then updates the FLAGS accordingly | 2 | `NZC` |
| 77 | `add SP,	<byte>` | Adds a constant to SP, stores the result back in SP, then updates the FLAGS accordingly | 2 | `NZC` |
| 78 | `add BP,	<byte>` | Adds a constant to BP, stores the result back in BP, then updates the FLAGS accordingly | 2 | `NZC` |
| 79 | `sub RA,	RA` | Subtracts RA from RA, stores the result back in RA, then updates the FLAGS accordingly | 1 | `NZC` |
| 7a | `sub RA,	RB` | Subtracts RB from RA, stores the result back in RA, then updates the FLAGS accordingly | 1 | `NZC` |
| 7b | `sub RA,	RC` | Subtracts RC from RA, stores the result back in RA, then updates the FLAGS accordingly | 1 | `NZC` |
| 7c | `sub RA,	RD` | Subtracts RD from RA, stores the result back in RA, then updates the FLAGS accordingly | 1 | `NZC` |
| 7d | `sub RB,	RA` | Subtracts RA from RB, stores the result back in RB, then updates the FLAGS accordingly | 1 | `NZC` |
| 7e | `sub RB,	RB` | Subtracts RB from RB, stores the result back in RB, then updates the FLAGS accordingly | 1 | `NZC` |
| 7f | `sub RB,	RC` | Subtracts RC from RB, stores the result back in RB, then updates the FLAGS accordingly | 1 | `NZC` |
| 80 | `sub RB,	RD` | Subtracts RD from RB, stores the result back in RB, then updates the FLAGS accordingly | 1 | `NZC` |
| 81 | `sub RC,	RA` | Subtracts RA from RC, stores the result back in RC, then updates the FLAGS accordingly | 1 | `NZC` |
| 82 | `sub RC,	RB` | Subtracts RB from RC, stores the result back in RC, then updates the FLAGS accordingly | 1 | `NZC` |
| 83 | `sub RC,	RC` | Subtracts RC from RC, stores the result back in RC, then updates the FLAGS accordingly | 1 | `NZC` |
| 84 | `sub RC,	RD` | Subtracts RD from RC, stores the result back in RC, then updates the FLAGS accordingly | 1 | `NZC` |
| 85 | `sub RD,	RA` | Subtracts RA from RD, stores the result back in RD, then updates the FLAGS accordingly | 1 | `NZC` |
| 86 | `sub RD,	RB` | Subtracts RB from RD, stores the result back in RD, then updates the FLAGS accordingly | 1 | `NZC` |
| 87 | `sub RD,	RC` | Subtracts RC from RD, stores the result back in RD, then updates the FLAGS accordingly | 1 | `NZC` |
| 88 | `sub RD,	RD` | Subtracts RD from RD, stores the result back in RD, then updates the FLAGS accordingly | 1 | `NZC` |
| 89 | `sub RA,	<byte>` | Subtracts a constant from RA, stores the result back in RA, then updates the FLAGS accordingly | 2 | `NZC` |
| 8a | `sub RB,	<byte>` | Subtracts a constant from RB, stores the result back in RB, then updates the FLAGS accordingly | 2 | `NZC` |
| 8b | `sub RC,	<byte>` | Subtracts a constant from RC, stores the result back in RC, then updates the FLAGS accordingly | 2 | `NZC` |
| 8c | `sub RD,	<byte>` | Subtracts a constant from RD, stores the result back in RD, then updates the FLAGS accordingly | 2 | `NZC` |
| 8d | `sub SP,	<byte>` | Subtracts a constant from SP, stores the result back in SP, then updates the FLAGS accordingly | 2 | `NZC` |
| 8e | `sub BP,	<byte>` | Subtracts a constant from BP, stores the result back in BP, then updates the FLAGS accordingly | 2 | `NZC` |
| 8f | `cmp RA,	RA` | Compares RA to RA, then updates the FLAGS accordingly | 1 | `NZC` |
| 90 | `cmp RA,	RB` | Compares RA to RB, then updates the FLAGS accordingly | 1 | `NZC` |
| 91 | `cmp RA,	RC` | Compares RA to RC, then updates the FLAGS accordingly | 1 | `NZC` |
| 92 | `cmp RA,	RD` | Compares RA to RD, then updates the FLAGS accordingly | 1 | `NZC` |
| 93 | `cmp RB,	RA` | Compares RB to RA, then updates the FLAGS accordingly | 1 | `NZC` |
| 94 | `cmp RB,	RB` | Compares RB to RB, then updates the FLAGS accordingly | 1 | `NZC` |
| 95 | `cmp RB,	RC` | Compares RB to RC, then updates the FLAGS accordingly | 1 | `NZC` |
| 96 | `cmp RB,	RD` | Compares RB to RD, then updates the FLAGS accordingly | 1 | `NZC` |
| 97 | `cmp RC,	RA` | Compares RC to RA, then updates the FLAGS accordingly | 1 | `NZC` |
| 98 | `cmp RC,	RB` | Compares RC to RB, then updates the FLAGS accordingly | 1 | `NZC` |
| 99 | `cmp RC,	RC` | Compares RC to RC, then updates the FLAGS accordingly | 1 | `NZC` |
| 9a | `cmp RC,	RD` | Compares RC to RD, then updates the FLAGS accordingly | 1 | `NZC` |
| 9b | `cmp RD,	RA` | Compares RD to RA, then updates the FLAGS accordingly | 1 | `NZC` |
| 9c | `cmp RD,	RB` | Compares RD to RB, then updates the FLAGS accordingly | 1 | `NZC` |
| 9d | `cmp RD,	RC` | Compares RD to RC, then updates the FLAGS accordingly | 1 | `NZC` |
| 9e | `cmp RD,	RD` | Compares RD to RD, then updates the FLAGS accordingly | 1 | `NZC` |
| 9f | `cmp RA,	<byte>` | Compares RA to a constant, then updates the FLAGS accordingly | 2 | `NZC` |
| a0 | `cmp RB,	<byte>` | Compares RB to a constant, then updates the FLAGS accordingly | 2 | `NZC` |
| a1 | `cmp RC,	<byte>` | Compares RC to a constant, then updates the FLAGS accordingly | 2 | `NZC` |
| a2 | `cmp RD,	<byte>` | Compares RD to a constant, then updates the FLAGS accordingly | 2 | `NZC` |
| a3 | `or RA,	RA` | Performs a bitwise OR of RA and RA, stores the result back in RA, then updates the FLAGS accordingly | 1 | `NZC` |
| a4 | `or RA,	RB` | Performs a bitwise OR of RA and RB, stores the result back in RA, then updates the FLAGS accordingly | 1 | `NZC` |
| a5 | `or RA,	RC` | Performs a bitwise OR of RA and RC, stores the result back in RA, then updates the FLAGS accordingly | 1 | `NZC` |
| a6 | `or RA,	RD` | Performs a bitwise OR of RA and RD, stores the result back in RA, then updates the FLAGS accordingly | 1 | `NZC` |
| a7 | `or RB,	RA` | Performs a bitwise OR of RB and RA, stores the result back in RB, then updates the FLAGS accordingly | 1 | `NZC` |
| a8 | `or RB,	RB` | Performs a bitwise OR of RB and RB, stores the result back in RB, then updates the FLAGS accordingly | 1 | `NZC` |
| a9 | `or RB,	RC` | Performs a bitwise OR of RB and RC, stores the result back in RB, then updates the FLAGS accordingly | 1 | `NZC` |
| aa | `or RB,	RD` | Performs a bitwise OR of RB and RD, stores the result back in RB, then updates the FLAGS accordingly | 1 | `NZC` |
| ab | `or RC,	RA` | Performs a bitwise OR of RC and RA, stores the result back in RC, then updates the FLAGS accordingly | 1 | `NZC` |
| ac | `or RC,	RB` | Performs a bitwise OR of RC and RB, stores the result back in RC, then updates the FLAGS accordingly | 1 | `NZC` |
| ad | `or RC,	RC` | Performs a bitwise OR of RC and RC, stores the result back in RC, then updates the FLAGS accordingly | 1 | `NZC` |
| ae | `or RC,	RD` | Performs a bitwise OR of RC and RD, stores the result back in RC, then updates the FLAGS accordingly | 1 | `NZC` |
| af | `or RD,	RA` | Performs a bitwise OR of RD and RA, stores the result back in RD, then updates the FLAGS accordingly | 1 | `NZC` |
| b0 | `or RD,	RB` | Performs a bitwise OR of RD and RB, stores the result back in RD, then updates the FLAGS accordingly | 1 | `NZC` |
| b1 | `or RD,	RC` | Performs a bitwise OR of RD and RC, stores the result back in RD, then updates the FLAGS accordingly | 1 | `NZC` |
| b2 | `or RD,	RD` | Performs a bitwise OR of RD and RD, stores the result back in RD, then updates the FLAGS accordingly | 1 | `NZC` |
| b3 | `or RA,	<byte>` | Performs a bitwise OR of RA and a constant, stores the result back in RA, then updates the FLAGS accordingly | 2 | `NZC` |
| b4 | `or RB,	<byte>` | Performs a bitwise OR of RB and a constant, stores the result back in RB, then updates the FLAGS accordingly | 2 | `NZC` |
| b5 | `or RC,	<byte>` | Performs a bitwise OR of RC and a constant, stores the result back in RC, then updates the FLAGS accordingly | 2 | `NZC` |
| b6 | `or RD,	<byte>` | Performs a bitwise OR of RD and a constant, stores the result back in RD, then updates the FLAGS accordingly | 2 | `NZC` |
| b7 | `and RA,	RA` | Performs a bitwise AND of RA and RA, stores the result back in RA, then updates the FLAGS accordingly | 1 | `NZC` |
| b8 | `and RA,	RB` | Performs a bitwise AND of RA and RB, stores the result back in RA, then updates the FLAGS accordingly | 1 | `NZC` |
| b9 | `and RA,	RC` | Performs a bitwise AND of RA and RC, stores the result back in RA, then updates the FLAGS accordingly | 1 | `NZC` |
| ba | `and RA,	RD` | Performs a bitwise AND of RA and RD, stores the result back in RA, then updates the FLAGS accordingly | 1 | `NZC` |
| bb | `and RB,	RA` | Performs a bitwise AND of RB and RA, stores the result back in RB, then updates the FLAGS accordingly | 1 | `NZC` |
| bc | `and RB,	RB` | Performs a bitwise AND of RB and RB, stores the result back in RB, then updates the FLAGS accordingly | 1 | `NZC` |
| bd | `and RB,	RC` | Performs a bitwise AND of RB and RC, stores the result back in RB, then updates the FLAGS accordingly | 1 | `NZC` |
| be | `and RB,	RD` | Performs a bitwise AND of RB and RD, stores the result back in RB, then updates the FLAGS accordingly | 1 | `NZC` |
| bf | `and RC,	RA` | Performs a bitwise AND of RC and RA, stores the result back in RC, then updates the FLAGS accordingly | 1 | `NZC` |
| c0 | `and RC,	RB` | Performs a bitwise AND of RC and RB, stores the result back in RC, then updates the FLAGS accordingly | 1 | `NZC` |
| c1 | `and RC,	RC` | Performs a bitwise AND of RC and RC, stores the result back in RC, then updates the FLAGS accordingly | 1 | `NZC` |
| c2 | `and RC,	RD` | Performs a bitwise AND of RC and RD, stores the result back in RC, then updates the FLAGS accordingly | 1 | `NZC` |
| c3 | `and RD,	RA` | Performs a bitwise AND of RD and RA, stores the result back in RD, then updates the FLAGS accordingly | 1 | `NZC` |
| c4 | `and RD,	RB` | Performs a bitwise AND of RD and RB, stores the result back in RD, then updates the FLAGS accordingly | 1 | `NZC` |
| c5 | `and RD,	RC` | Performs a bitwise AND of RD and RC, stores the result back in RD, then updates the FLAGS accordingly | 1 | `NZC` |
| c6 | `and RD,	RD` | Performs a bitwise AND of RD and RD, stores the result back in RD, then updates the FLAGS accordingly | 1 | `NZC` |
| c7 | `and RA,	<byte>` | Performs a bitwise AND of RA and a constant, stores the result back in RA, then updates the FLAGS accordingly | 2 | `NZC` |
| c8 | `and RB,	<byte>` | Performs a bitwise AND of RB and a constant, stores the result back in RB, then updates the FLAGS accordingly | 2 | `NZC` |
| c9 | `and RC,	<byte>` | Performs a bitwise AND of RC and a constant, stores the result back in RC, then updates the FLAGS accordingly | 2 | `NZC` |
| ca | `and RD,	<byte>` | Performs a bitwise AND of RD and a constant, stores the result back in RD, then updates the FLAGS accordingly | 2 | `NZC` |
| cb | `xor RA,	RA` | Performs a bitwise XOR of RA and RA, stores the result back in RA, then updates the FLAGS accordingly | 1 | `NZC` |
| cc | `xor RA,	RB` | Performs a bitwise XOR of RA and RB, stores the result back in RA, then updates the FLAGS accordingly | 1 | `NZC` |
| cd | `xor RA,	RC` | Performs a bitwise XOR of RA and RC, stores the result back in RA, then updates the FLAGS accordingly | 1 | `NZC` |
| ce | `xor RA,	RD` | Performs a bitwise XOR of RA and RD, stores the result back in RA, then updates the FLAGS accordingly | 1 | `NZC` |
| cf | `xor RB,	RA` | Performs a bitwise XOR of RB and RA, stores the result back in RB, then updates the FLAGS accordingly | 1 | `NZC` |
| d0 | `xor RB,	RB` | Performs a bitwise XOR of RB and RB, stores the result back in RB, then updates the FLAGS accordingly | 1 | `NZC` |
| d1 | `xor RB,	RC` | Performs a bitwise XOR of RB and RC, stores the result back in RB, then updates the FLAGS accordingly | 1 | `NZC` |
| d2 | `xor RB,	RD` | Performs a bitwise XOR of RB and RD, stores the result back in RB, then updates the FLAGS accordingly | 1 | `NZC` |
| d3 | `xor RC,	RA` | Performs a bitwise XOR of RC and RA, stores the result back in RC, then updates the FLAGS accordingly | 1 | `NZC` |
| d4 | `xor RC,	RB` | Performs a bitwise XOR of RC and RB, stores the result back in RC, then updates the FLAGS accordingly | 1 | `NZC` |
| d5 | `xor RC,	RC` | Performs a bitwise XOR of RC and RC, stores the result back in RC, then updates the FLAGS accordingly | 1 | `NZC` |
| d6 | `xor RC,	RD` | Performs a bitwise XOR of RC and RD, stores the result back in RC, then updates the FLAGS accordingly | 1 | `NZC` |
| d7 | `xor RD,	RA` | Performs a bitwise XOR of RD and RA, stores the result back in RD, then updates the FLAGS accordingly | 1 | `NZC` |
| d8 | `xor RD,	RB` | Performs a bitwise XOR of RD and RB, stores the result back in RD, then updates the FLAGS accordingly | 1 | `NZC` |
| d9 | `xor RD,	RC` | Performs a bitwise XOR of RD and RC, stores the result back in RD, then updates the FLAGS accordingly | 1 | `NZC` |
| da | `xor RD,	RD` | Performs a bitwise XOR of RD and RD, stores the result back in RD, then updates the FLAGS accordingly | 1 | `NZC` |
| db | `xor RA,	<byte>` | Performs a bitwise XOR of RA and a constant, stores the result back in RA, then updates the FLAGS accordingly | 2 | `NZC` |
| dc | `xor RB,	<byte>` | Performs a bitwise XOR of RB and a constant, stores the result back in RB, then updates the FLAGS accordingly | 2 | `NZC` |
| dd | `xor RC,	<byte>` | Performs a bitwise XOR of RC and a constant, stores the result back in RC, then updates the FLAGS accordingly | 2 | `NZC` |
| de | `xor RD,	<byte>` | Performs a bitwise XOR of RD and a constant, stores the result back in RD, then updates the FLAGS accordingly | 2 | `NZC` |
| df | `not RA` | Performs a bitwise NOT of RA, stores the result back in RA, then updates the FLAGS accordingly | 1 | `NZC` |
| e0 | `not RB` | Performs a bitwise NOT of RB, stores the result back in RB, then updates the FLAGS accordingly | 1 | `NZC` |
| e1 | `not RC` | Performs a bitwise NOT of RC, stores the result back in RC, then updates the FLAGS accordingly | 1 | `NZC` |
| e2 | `not RD` | Performs a bitwise NOT of RD, stores the result back in RD, then updates the FLAGS accordingly | 1 | `NZC` |
| e3 | `inc RA` | Increments RA by 1, then updates the FLAGS accordingly | 1 | `NZC` |
| e4 | `inc RB` | Increments RB by 1, then updates the FLAGS accordingly | 1 | `NZC` |
| e5 | `inc RC` | Increments RC by 1, then updates the FLAGS accordingly | 1 | `NZC` |
| e6 | `inc RD` | Increments RD by 1, then updates the FLAGS accordingly | 1 | `NZC` |
| e7 | `dec RA` | Decrements RA by 1, then updates the FLAGS accordingly | 1 | `NZC` |
| e8 | `dec RB` | Decrements RB by 1, then updates the FLAGS accordingly | 1 | `NZC` |
| e9 | `dec RC` | Decrements RC by 1, then updates the FLAGS accordingly | 1 | `NZC` |
| ea | `dec RD` | Decrements RD by 1, then updates the FLAGS accordingly | 1 | `NZC` |
| eb | `shl RA` | Performs a left bitwise shift of RA by 1 bit | 1 | - |
| ec | `shr RA` | Performs a right bitwise shift of RA by 1 bit | 1 | - |
| ed | `jc <byte>` | Jumps to the given short address (same code segment) if the carry flag is set | 3 | - |
| ee | `jn <byte>` | Jumps to the given short address (same code segment) if the negative flag is set | 3 | - |
| ef | `jz <byte>` | Jumps to the given short address (same code segment) if the zero flag is set | 3 | - |
| f0 | `goto <byte>` | Jumps to the given short address (same code segment) | 3 | - |
| f1 | `ljc <dcst>` | Jumps to the given long address if the carry flag is set | 4 | - |
| f2 | `ljn <dcst>` | Jumps to the given long address if the negative flag is set | 4 | - |
| f3 | `ljz <dcst>` | Jumps to the given long address if the zero flag is set | 4 | - |
| f4 | `lgoto <dcst>` | Jumps to the given long address | 4 | - |
| f5 | `lgoto RC:RD` | Jumps to the long address specified by RC:RD | 4 | - |
| f6 | `lcall <dcst>` | Calls the given long address | 6 | - |
| f7 | `lcall RC:RD` | Calls the long address specified by RC:RD | 6 | - |
| f8 | `ret ` | Returns from a call | 4 | - |
| f9 | `ret <byte>` | Returns from a call and decrements the stack pointer by a constant | 6 | - |
| fa | `iret ` | Returns from an interrupt | 5 | - |
| fb | `cid ` | Clears the interrupt disable flag | 1 | `I` |
| fc | `sid ` | Sets the interrupt disable flag | 1 | `I` |
| fd | `clc ` | Clears the carry flag | 1 | `C` |
| fe | `sec ` | Sets the carry flag | 1 | `C` |

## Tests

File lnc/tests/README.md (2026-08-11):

# lnc compiler stability tests

Each executable test lives in its own directory and contains:

- `test.lnc`: the source program compiled with `--standalone`.
- `pass.txt`: final emulator pass conditions, consumed directly by `lncpu-emu --expect`.

`pass.txt` accepts the emulator expectation format:

```text
RA = 0x12
CSPC = 0x0010
HALTED = 1
[0x2000] = 42
```

Values may be decimal, `0x` hexadecimal, or `0b` binary. Comments start with `#`, `;`, or `//`.

Compile-failure tests add `test.json`:

```json
{
  "kind": "compile_fail",
  "expect_stderr_contains": "diagnostic substring"
}
```

Executable tests may also add assembly-shape assertions to `test.json`. Both
values are non-empty Python regular-expression strings evaluated against the
emitted `program.lnasm` after compilation and before emulation:

```json
{
  "asm_must_match": "(?m)^\\s*add\\s+(R[ABCD]),\\s*\\1\\s*$",
  "asm_must_not_match": "(?m)^\\s*shl\\b"
}
```

`asm_must_match` must match at least once; `asm_must_not_match` must not
match. An invalid or empty regex fails the case.

Run the full suite from this directory or the repository root:

```sh
python3 lnc/tests/run_lnc_tests.py
```

The runner builds `lnc` and `lncpu-emu`, compiles each test, runs executable cases on the emulator, and prints a summary.

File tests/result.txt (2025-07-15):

======TEST======mov_bp_sp: Passed
Message:

======TEST======mov_ibpoffset_rd: Passed
Message:

======TEST======mov_rd_ra: Passed
Message:

======TEST======add_ra_rc: Passed
Message:

======TEST======push_ra: Passed
Message:

======TEST======sub_ra_rd: Passed
Message:

======TEST======mov_ds_rd: Passed
Message:

======TEST======pop_rc: Passed
Message:

======TEST======int: Passed
Message:

======TEST======goto_cst: Passed
Message:

======TEST======xor_ra_rd: Passed
Message:

======TEST======pop_datap: Passed
Message:

======TEST======sub_rc_rc: Passed
Message:

======TEST======and_rc_rd: Passed
Message:

======TEST======cmp_ra_rc: Passed
Message:

======TEST======or_rd_rb: Passed
Message:

======TEST======sub_sp_cst: Passed
Message:

======TEST======add_rb_cst: Passed
Message:

======TEST======jn_cst: Passed
Message:

======TEST======mov_ra_datap: Passed
Message:

======TEST======xor_rc_rc: Passed
Message:

======TEST======not_ra: Passed
Message:

======TEST======add_sp_cst: Passed
Message:

======TEST======mov_cst_rb: Passed
Message:

======TEST======add_rc_rb: Passed
Message:

======TEST======and_ra_cst: Passed
Message:

======TEST======cmp_rc_rc: Passed
Message:

======TEST======mov_rd_ibpoffset: Passed
Message:

======TEST======or_rd_cst: Passed
Message:

======TEST======cmp_rb_cst: Passed
Message:

======TEST======mov_ra_ibpoffset: Passed
Message:

======TEST======mov_ra_ircrd: Passed
Message:

======TEST======mov_ircrd_rb: Passed
Message:

======TEST======mov_rc_ibpoffset: Passed
Message:

======TEST======or_rb_rc: Passed
Message:

======TEST======and_ra_rd: Passed
Message:

======TEST======mov_rb_ibpoffset: Passed
Message:

======TEST======sub_rb_cst: Passed
Message:

======TEST======mov_sp_bp: Passed
Message:

======TEST======add_ra_rb: Passed
Message:

======TEST======push_rb: Passed
Message:

======TEST======sub_ra_rc: Passed
Message:

======TEST======pop_rd: Passed
Message:

======TEST======mov_rd_datap: Passed
Message:

======TEST======and_rb_ra: Passed
Message:

======TEST======jc_cst: Passed
Message:

======TEST======or_rc_cst: Passed
Message:

======TEST======mov_rb_ra: Passed
Message:

======TEST======xor_ra_rc: Passed
Message:

======TEST======sub_rc_rb: Passed
Message:

======TEST======cmp_ra_cst: Passed
Message:

======TEST======xor_rb_ra: Passed
Message:

======TEST======cmp_ra_rd: Passed
Message:

======TEST======mov_cst_ss: Passed
Message:

======TEST======or_rd_ra: Passed
Message:

======TEST======mov_cst_ircrd: Passed
Message:

======TEST======xor_rc_rb: Passed
Message:

======TEST======add_rc_ra: Passed
Message:

======TEST======mov_cst_ra: Passed
Message:

======TEST======mov_rd_ircrd: Passed
Message:

======TEST======or_rb_rb: Passed
Message:

======TEST======mov_cst_datap: Passed
Message:

======TEST======cmp_rc_rb: Passed
Message:

======TEST======mov_ircrd_rc: Passed
Message:

======TEST======and_ra_rc: Passed
Message:

======TEST======ljn_dcst: Passed
Message:

======TEST======mov_ibpoffset_rb: Passed
Message:

======TEST======add_ra_ra: Passed
Message:

======TEST======add_rd_rd: Passed
Message:

======TEST======mov_rc_datap: Passed
Message:

======TEST======lcall_rcrd: Passed
Message:

======TEST======sub_rd_ra: Passed
Message:

======TEST======and_rb_rb: Passed
Message:

======TEST======xor_rd_ra: Passed
Message:

======TEST======and_rc_rb: Passed
Message:

======TEST======sub_rc_ra: Passed
Message:

======TEST======or_rd_rd: Passed
Message:

======TEST======mov_rb_rd: Passed
Message:

======TEST======mov_sp_rd: Passed
Message:

======TEST======push_bp: Passed
Message:

======TEST======dec_rd: Passed
Message:

======TEST======xor_rc_ra: Passed
Message:

======TEST======cid: Passed
Message:

======TEST======push_abs: Passed
Message:

======TEST======add_rc_rd: Passed
Message:

======TEST======mov_rd_abs: Passed
Message:

======TEST======add_rb_ra: Passed
Message:

======TEST======mov_rd_sp: Passed
Message:

======TEST======or_rb_ra: Passed
Message:

======TEST======cmp_rc_ra: Passed
Message:

======TEST======and_ra_rb: Passed
Message:

======TEST======ret: Passed
Message:

======TEST======mov_abs_rd: Passed
Message:

======TEST======inc_ra: Passed
Message:

======TEST======mov_ibpoffset_rc: Passed
Message:

======TEST======mov_ra_abs: Passed
Message:

======TEST======and_rb_rc: Passed
Message:

======TEST======xor_rd_rb: Passed
Message:

======TEST======and_rc_rc: Passed
Message:

======TEST======cmp_rd_ra: Passed
Message:

======TEST======or_rd_rc: Passed
Message:

======TEST======iret: Passed
Message:

======TEST======dec_rc: Passed
Message:

======TEST======mov_rb_rc: Passed
Message:

======TEST======mov_rc_rd: Passed
Message:

======TEST======mov_rb_abs: Passed
Message:

======TEST======or_rc_ra: Passed
Message:

======TEST======lcall_dcst: Passed
Message:

======TEST======add_rc_rc: Passed
Message:

======TEST======push_ircrd: Passed
Message:

======TEST======add_rb_rb: Passed
Message:

======TEST======ljc_dcst: Passed
Message:

======TEST======mov_ircrd_ra: Passed
Message:

======TEST======and_ra_ra: Passed
Message:

======TEST======mov_rb_ircrd: Passed
Message:

======TEST======cmp_rb_rc: Passed
Message:

======TEST======xor_rc_cst: Passed
Message:

======TEST======add_rd_rb: Passed
Message:

======TEST======and_rb_rd: Passed
Message:

======TEST======mov_ra_rb: Passed
Message:

======TEST======or_ra_rc: Passed
Message:

======TEST======xor_rb_rd: Passed
Message:

======TEST======mov_rc_abs: Passed
Message:

======TEST======xor_rd_rc: Passed
Message:

======TEST======sub_rd_rc: Passed
Message:

======TEST======mov_cst_sp: Passed
Message:

======TEST======cmp_rd_rb: Passed
Message:

======TEST======dec_rb: Passed
Message:

======TEST======pop_bp: Passed
Message:

======TEST======and_rd_rd: Passed
Message:

======TEST======lgoto_dcst: Passed
Message:

======TEST======sub_rb_rc: Passed
Message:

======TEST======mov_datap_rb: Passed
Message:

======TEST======mov_rc_ra: Passed
Message:

======TEST======or_rc_rb: Passed
Message:

======TEST======add_rb_rc: Passed
Message:

======TEST======mov_cst_bp: Passed
Message:

======TEST======mov_cst_ds: Passed
Message:

======TEST======or_ra_cst: Passed
Message:

======TEST======mov_abs_rb: Passed
Message:

======TEST======inc_rc: Passed
Message:

======TEST======shr_ra: Passed
Message:

======TEST======mov_cst_abs: Passed
Message:

======TEST======add_rd_rc: Passed
Message:

======TEST======mov_ibpoffset_ra: Passed
Message:

======TEST======and_rd_cst: Passed
Message:

======TEST======cmp_rb_rd: Passed
Message:

======TEST======sub_rd_cst: Passed
Message:

======TEST======or_ra_rd: Passed
Message:

======TEST======mov_ra_rc: Passed
Message:

======TEST======xor_rd_rd: Passed
Message:

======TEST======sub_rd_rb: Passed
Message:

======TEST======and_rc_ra: Passed
Message:

======TEST======pop_abs: Passed
Message:

======TEST======cmp_rd_rc: Passed
Message:

======TEST======sub_bp_cst: Passed
Message:

======TEST======dec_ra: Passed
Message:

======TEST======and_rc_cst: Passed
Message:

======TEST======and_rd_rc: Passed
Message:

======TEST======mov_datap_ra: Passed
Message:

======TEST======sub_rb_rd: Passed
Message:

======TEST======or_rb_cst: Passed
Message:

======TEST======mov_rc_rb: Passed
Message:

======TEST======or_rc_rc: Passed
Message:

======TEST======add_rb_rd: Passed
Message:

======TEST======sec: Passed
Message:

======TEST======xor_rd_cst: Passed
Message:

======TEST======not_rd: Passed
Message:

======TEST======mov_abs_rc: Passed
Message:

======TEST======inc_rb: Passed
Message:

======TEST======lgoto_rcrd: Passed
Message:

======TEST======cmp_rb_ra: Passed
Message:

======TEST======push_datap: Passed
Message:

======TEST======mov_rd_rc: Passed
Message:

======TEST======pop_ra: Passed
Message:

======TEST======mov_ra_rd: Passed
Message:

======TEST======push_rc: Passed
Message:

======TEST======sub_ra_rb: Passed
Message:

======TEST======xor_ra_rb: Passed
Message:

======TEST======sub_rc_cst: Passed
Message:

======TEST======xor_rb_rb: Passed
Message:

======TEST======or_ra_ra: Passed
Message:

======TEST======cmp_rd_rd: Passed
Message:

======TEST======and_rb_cst: Passed
Message:

======TEST======push_cst: Passed
Message:

======TEST======cmp_ra_ra: Passed
Message:

======TEST======mov_rd_ds: Passed
Message:

======TEST======or_rc_rd: Passed
Message:

======TEST======sub_rb_ra: Passed
Message:

======TEST======xor_rb_cst: Passed
Message:

======TEST======mov_ss_rd: Passed
Message:

======TEST======ljz_dcst: Passed
Message:

======TEST======and_rd_rb: Passed
Message:

======TEST======mov_datap_rd: Passed
Message:

======TEST======mov_cst_rd: Passed
Message:

======TEST======add_rd_cst: Passed
Message:

======TEST======add_ra_cst: Passed
Message:

======TEST======mov_rc_ircrd: Passed
Message:

======TEST======shl_ra: Passed
Message:

======TEST======mov_datap_datap: Passed
Message:

======TEST======not_rc: Passed
Message:

======TEST======sid: Passed
Message:

======TEST======mov_ircrd_rd: Passed
Message:

======TEST======cmp_rb_rb: Passed
Message:

======TEST======ret_cst: Passed
Message:

======TEST======add_rd_ra: Passed
Message:

======TEST======cmp_rd_cst: Passed
Message:

======TEST======mov_rd_rb: Passed
Message:

======TEST======or_ra_rb: Passed
Message:

======TEST======sub_ra_cst: Passed
Message:

======TEST======sub_rd_rd: Passed
Message:

======TEST======xor_rb_rc: Passed
Message:

======TEST======add_ra_rd: Passed
Message:

======TEST======add_rc_cst: Passed
Message:

======TEST======pop_rb: Passed
Message:

======TEST======push_rd: Passed
Message:

======TEST======sub_ra_ra: Passed
Message:

======TEST======xor_ra_ra: Passed
Message:

======TEST======xor_ra_cst: Passed
Message:

======TEST======sub_rc_rd: Passed
Message:

======TEST======clc: Passed
Message:

======TEST======mov_rb_datap: Passed
Message:

======TEST======cmp_ra_rb: Passed
Message:

======TEST======cmp_rc_cst: Passed
Message:

======TEST======jz_cst: Passed
Message:

======TEST======and_rd_ra: Passed
Message:

======TEST======sub_rb_rb: Passed
Message:

======TEST======mov_cst_ibpoffset: Passed
Message:

======TEST======mov_cst_rc: Passed
Message:

======TEST======mov_datap_rc: Passed
Message:

======TEST======pop_ircrd: Passed
Message:

======TEST======cmp_rc_rd: Passed
Message:

======TEST======mov_rd_ss: Passed
Message:

======TEST======not_rb: Passed
Message:

======TEST======add_bp_cst: Passed
Message:

======TEST======mov_abs_ra: Passed
Message:

======TEST======inc_rd: Passed
Message:

======TEST======or_rb_rd: Passed
Message:

======TEST======xor_rc_rd: Passed
Message:

======TEST======mov_rc_ird: Failed
Message:
Failed conditions:
[0x0021] = 0x90 (actual: 0x00)

======TEST======mov_ra_ird: Failed
Message:
Failed conditions:
[0x0042] = 0x11 (actual: 0x00)

======TEST======pop_ird: Failed
Message:
Failed conditions:
[0x00ff] = 0x42 (actual: 0x00)

======TEST======mov_rd_ird: Failed
Message:
Failed conditions:
[0x0021] = 0x21 (actual: 0x00)

======TEST======mov_ird_rd: Failed
Message:
Failed conditions:
RD = 0x11 (actual: 0x00)

======TEST======push_ird: Failed
Message:
Failed conditions:
[0x0100] = 0x11 (actual: 0x00)

======TEST======mov_rb_ird: Failed
Message:
Failed conditions:
[0x0055] = 0x24 (actual: 0x00)

======TEST======mov_ird_ra: Failed
Message:
Failed conditions:
RA = 0x42 (actual: 0x00)

======TEST======mov_ird_rc: Failed
Message:
Failed conditions:
RC = 0x44 (actual: 0x00)

======TEST======mov_ird_rb: Failed
Message:
Failed conditions:
RB = 0x29 (actual: 0x00)

======TEST======mov_cst_ird: Failed
Message:
Failed conditions:
[0x0029] = 0x44 (actual: 0x00)

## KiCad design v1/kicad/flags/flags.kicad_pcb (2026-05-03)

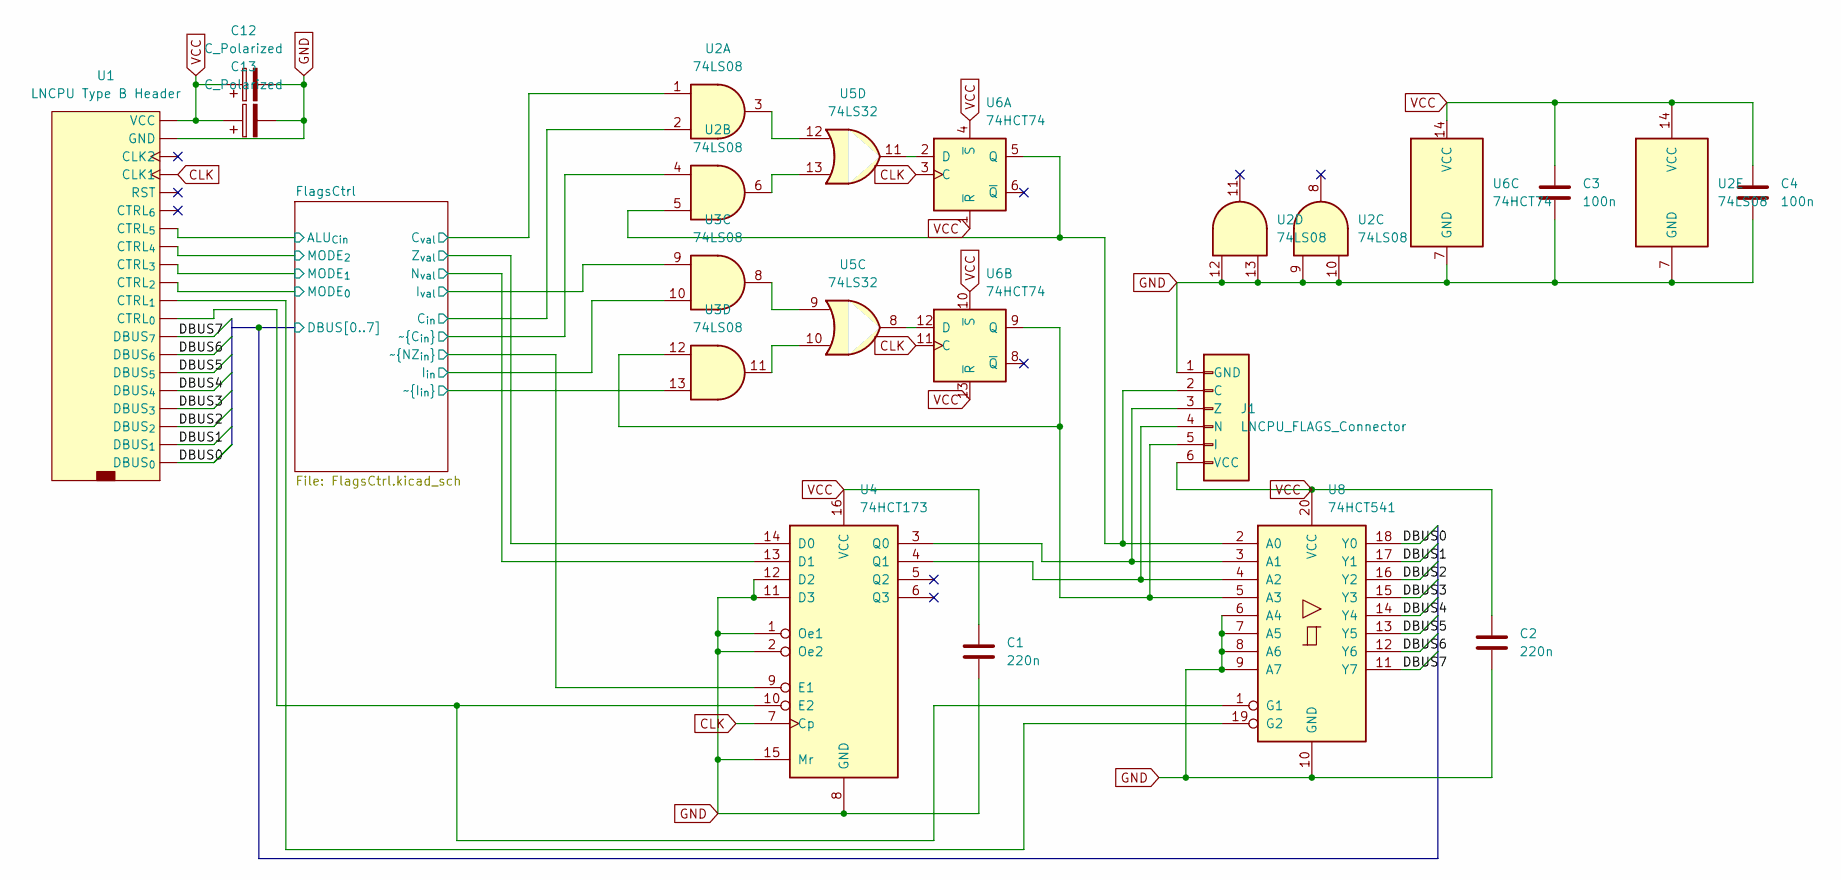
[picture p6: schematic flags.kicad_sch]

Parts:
C1, C2: 220n; C_Disc_D5.0mm_W2.5mm_P2.50mm
C3, C4: 100n; C_Disc_D5.0mm_W2.5mm_P2.50mm
C12: C_Polarized; CP_Radial_D5.0mm_P2.00mm
C13: C_Polarized; CP_Radial_D4.0mm_P2.00mm-Large-Holes
J1: LNCPU_FLAGS_Connector; PinSocket_1x06_P2.54mm_Vertical
U1: LNCPU Type B Header; LNCPU_Type_B_Header
U2, U3: 74LS08; DIP-14_W7.62mm_LongPads
U4: 74HCT173; DIP-16_W7.62mm_LongPads
U5: 74LS32; DIP-14_W7.62mm_LongPads
U6: 74HCT74; DIP-14_W7.62mm_LongPads
U8: 74HCT541; DIP-20_W7.62mm_LongPads

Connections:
/FlagsCtrl/ALU_{Cin}: U1.14 (CTRL_{5}); also elsewhere on the board
/FlagsCtrl/C_{val}: U2.1; also elsewhere on the board
/FlagsCtrl/DBUS0: U1.3 (DBUS_{0}), U8.18 (Y0); also elsewhere on the board
/FlagsCtrl/DBUS1: U1.5 (DBUS_{1}), U8.17 (Y1); also elsewhere on the board
/FlagsCtrl/DBUS2: U1.7 (DBUS_{2}), U8.16 (Y2); also elsewhere on the board
/FlagsCtrl/DBUS3: U1.9 (DBUS_{3}), U8.15 (Y3); also elsewhere on the board
/FlagsCtrl/DBUS4: U1.11 (DBUS_{4}), U8.14 (Y4); also elsewhere on the board
/FlagsCtrl/DBUS5: U1.13 (DBUS_{5}), U8.13 (Y5); also elsewhere on the board
/FlagsCtrl/DBUS6: U1.15 (DBUS_{6}), U8.12 (Y6); also elsewhere on the board
/FlagsCtrl/DBUS7: U1.17 (DBUS_{7}), U8.11 (Y7); also elsewhere on the board
/FlagsCtrl/I_{in}: U3.10; also elsewhere on the board
/FlagsCtrl/I_{val}: U3.9; also elsewhere on the board
/FlagsCtrl/MODE_{0}: U1.8 (CTRL_{2}); also elsewhere on the board
/FlagsCtrl/MODE_{1}: U1.10 (CTRL_{3}), U2.2; also elsewhere on the board
/FlagsCtrl/MODE_{2}: U1.12 (CTRL_{4}); also elsewhere on the board
/FlagsCtrl/N_{val}: U4.13 (D1); also elsewhere on the board
/FlagsCtrl/Z_{val}: U4.14 (D0); also elsewhere on the board
/FlagsCtrl/~I_{in}: U3.13; also elsewhere on the board
/FlagsCtrl/~MODE_{1}: U2.4; also elsewhere on the board
/FlagsCtrl/~NZ_{in}: U4.9 (E1); also elsewhere on the board
CLK: U1.21 (CLK1), U4.7 (Cp), U6.3 (C), U6.11 (C)
GND: C1.2, C2.2, C3.2, C4.2, C12.2, C13.2, J1.1 (GND), U1.1 (GND), U1.18 (GND), U1.22 (GND), U1.23 (GND), U2.7 (GND), U2.9, U2.10, U2.12, U2.13, U4.1 (Oe1), U4.2 (Oe2), U4.8 (GND), U4.11 (D3), U4.12 (D2), U4.15 (Mr), U6.7 (GND), U8.6 (A4), U8.7 (A5), U8.8 (A6), U8.9 (A7), U8.10 (GND); also elsewhere on the board
unnamed: J1.2 (C), U2.5, U6.5 (Q), U8.2 (A0)
unnamed: J1.5 (I), U3.12, U6.9 (Q), U8.5 (A3)
unnamed: J1.4 (N), U4.4 (Q1), U8.4 (A2)
unnamed: J1.3 (Z), U4.3 (Q0), U8.3 (A1)
unnamed: U1.4 (CTRL_{0}), U4.10 (E2), U8.1 (G1)
unnamed: U1.6 (CTRL_{1}), U8.19 (G2)
unnamed: U2.3, U5.12
unnamed: U2.6, U5.13
unnamed: U3.8, U5.9
unnamed: U3.11, U5.10
unnamed: U5.11, U6.2 (D)
unnamed: U5.8, U6.12 (D)
VCC: C1.1, C2.1, C3.1, C4.1, C12.1, C13.1, J1.6 (VCC), U1.2 (VCC), U1.24 (VCC), U2.14 (VCC), U4.16 (VCC), U6.1 (~R), U6.4 (~S), U6.10 (~S), U6.13 (~R), U6.14 (VCC), U8.20 (VCC); also elsewhere on the board

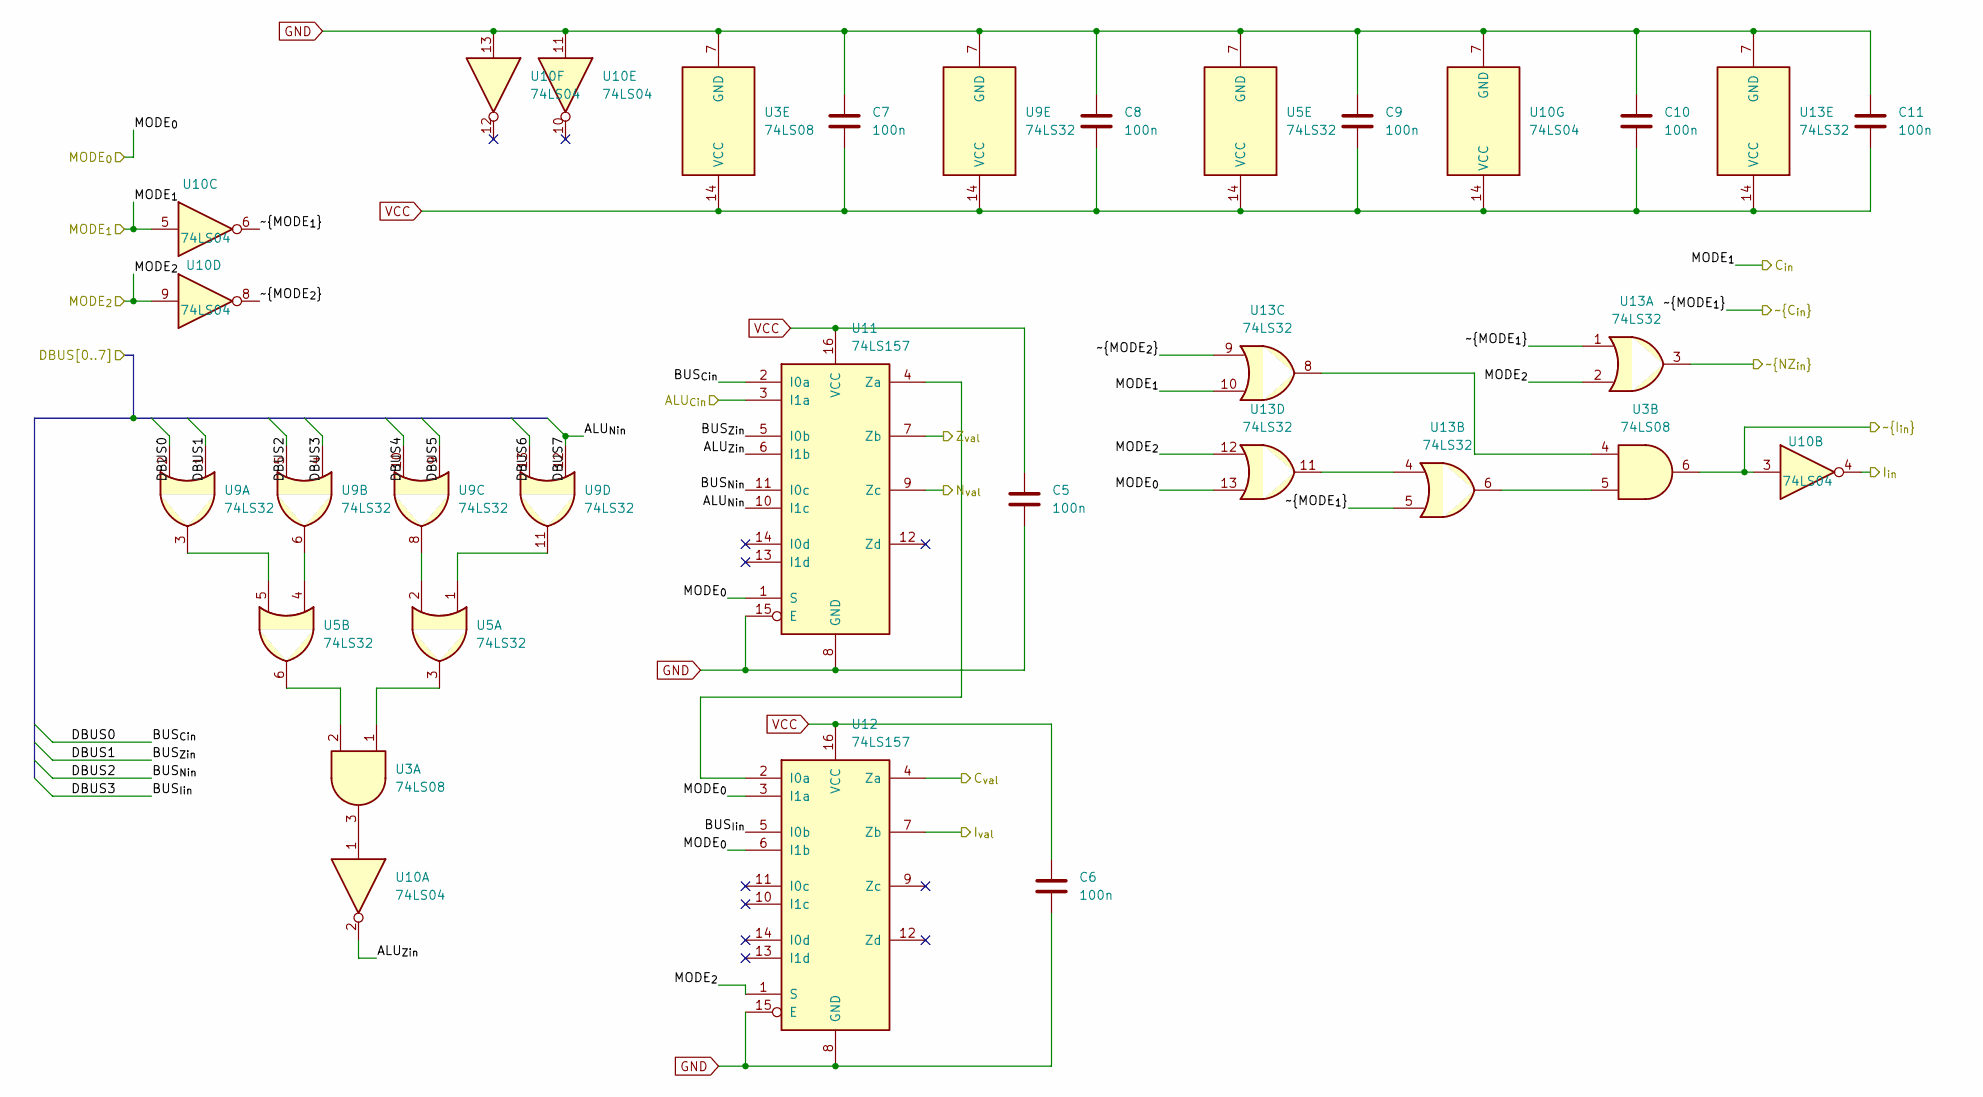
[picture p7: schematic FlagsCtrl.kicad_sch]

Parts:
C5, C6, C7, C8, C9, C10, C11: 100n; C_Disc_D5.0mm_W2.5mm_P2.50mm
U3: 74LS08; DIP-14_W7.62mm_LongPads
U5, U9, U13: 74LS32; DIP-14_W7.62mm_LongPads
U10: 74LS04; DIP-14_W7.62mm_LongPads
U11, U12: 74LS157; DIP-16_W7.62mm_LongPads

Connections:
/FlagsCtrl/ALU_{Cin}: U11.3 (I1a); also elsewhere on the board
/FlagsCtrl/ALU_{Zin}: U10.2, U11.6 (I1b)
/FlagsCtrl/C_{val}: U12.4 (Za); also elsewhere on the board
/FlagsCtrl/DBUS0: U9.2, U11.2 (I0a); also elsewhere on the board
/FlagsCtrl/DBUS1: U9.1, U11.5 (I0b); also elsewhere on the board
/FlagsCtrl/DBUS2: U9.5, U11.11 (I0c); also elsewhere on the board
/FlagsCtrl/DBUS3: U9.4, U12.5 (I0b); also elsewhere on the board
/FlagsCtrl/DBUS4: U9.10; also elsewhere on the board
/FlagsCtrl/DBUS5: U9.9; also elsewhere on the board
/FlagsCtrl/DBUS6: U9.13; also elsewhere on the board
/FlagsCtrl/DBUS7: U9.12, U11.10 (I1c); also elsewhere on the board
/FlagsCtrl/I_{in}: U10.4; also elsewhere on the board
/FlagsCtrl/I_{val}: U12.7 (Zb); also elsewhere on the board
/FlagsCtrl/MODE_{0}: U11.1 (S), U12.3 (I1a), U12.6 (I1b), U13.13; also elsewhere on the board
/FlagsCtrl/MODE_{1}: U10.5, U13.10; also elsewhere on the board
/FlagsCtrl/MODE_{2}: U10.9, U12.1 (S), U13.2, U13.12; also elsewhere on the board
/FlagsCtrl/N_{val}: U11.9 (Zc); also elsewhere on the board
/FlagsCtrl/Z_{val}: U11.7 (Zb); also elsewhere on the board
/FlagsCtrl/~I_{in}: U3.6, U10.3; also elsewhere on the board
/FlagsCtrl/~MODE_{1}: U10.6, U13.1, U13.5; also elsewhere on the board
/FlagsCtrl/~MODE_{2}: U10.8, U13.9
/FlagsCtrl/~NZ_{in}: U13.3; also elsewhere on the board
GND: C5.2, C6.2, C7.1, C8.1, C9.1, C10.1, C11.1, U3.7 (GND), U5.7 (GND), U9.7 (GND), U10.7 (GND), U10.11, U10.13, U11.8 (GND), U11.15 (E), U12.8 (GND), U12.15 (E), U13.7 (GND); also elsewhere on the board
unnamed: U3.1, U5.3
unnamed: U3.2, U5.6
unnamed: U5.1, U9.11
unnamed: U5.2, U9.8
unnamed: U5.4, U9.6
unnamed: U5.5, U9.3
unnamed: U3.3, U10.1
unnamed: U11.4 (Za), U12.2 (I0a)
unnamed: U3.5, U13.6
unnamed: U3.4, U13.8
unnamed: U13.4, U13.11
VCC: C5.1, C6.1, C7.2, C8.2, C9.2, C10.2, C11.2, U3.14 (VCC), U5.14 (VCC), U9.14 (VCC), U10.14 (VCC), U11.16 (VCC), U12.16 (VCC), U13.14 (VCC); also elsewhere on the board

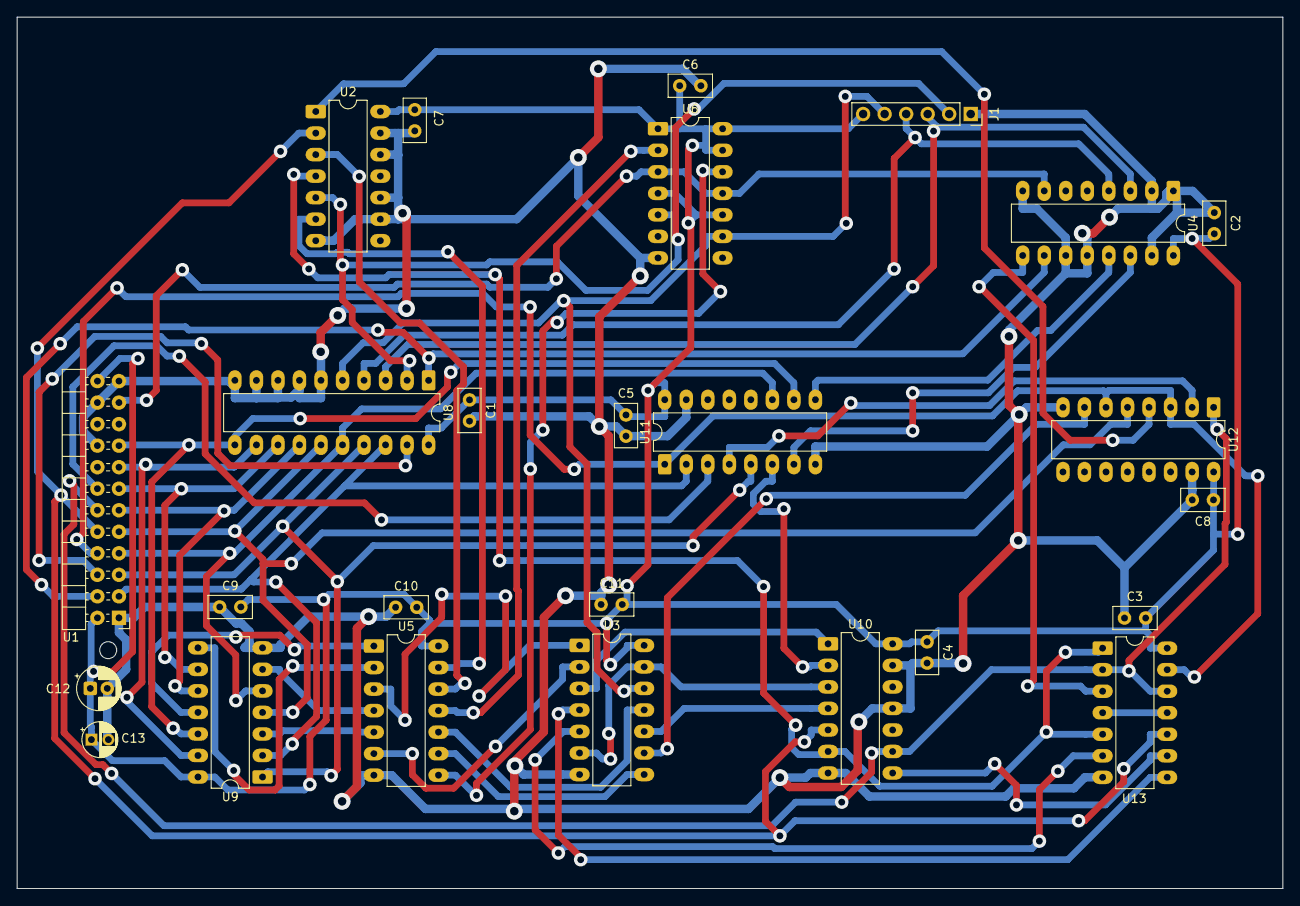
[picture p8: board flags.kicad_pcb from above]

Board: 2 copper layers, 149.4 x 102.8 mm, 26 parts (0 on the bottom side), 48 nets.

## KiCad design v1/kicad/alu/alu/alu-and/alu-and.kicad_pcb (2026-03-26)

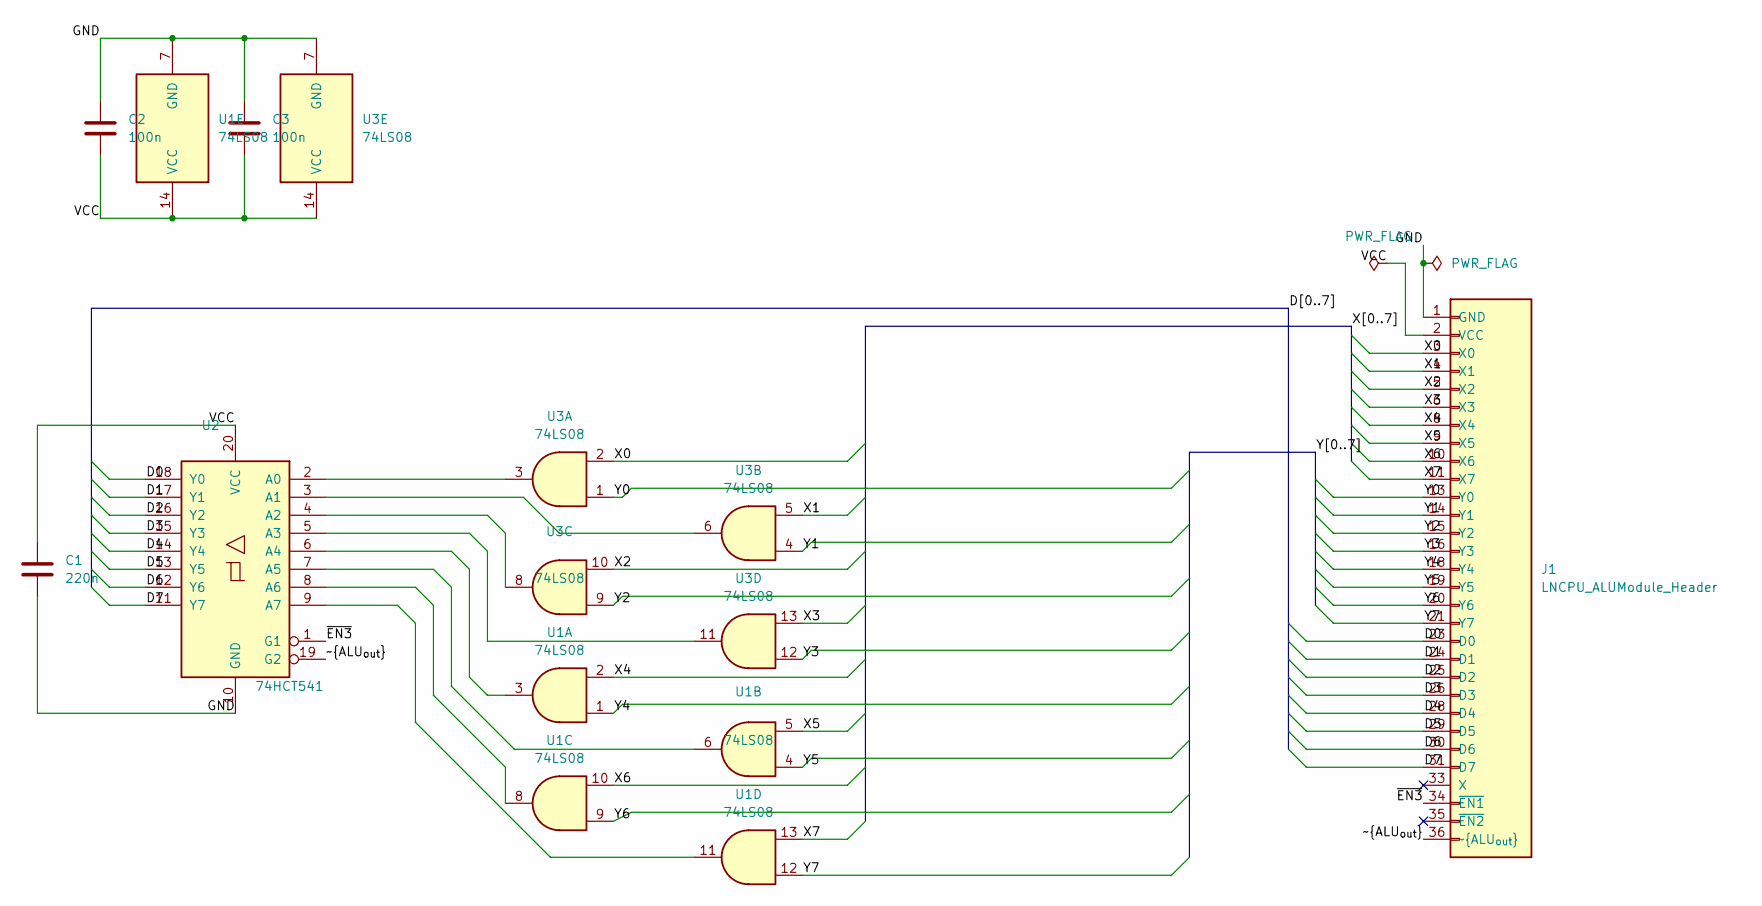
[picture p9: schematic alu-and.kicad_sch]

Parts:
C1: 220n; C_Disc_D5.0mm_W2.5mm_P5.00mm
C2, C3: 100n; C_Disc_D5.0mm_W2.5mm_P5.00mm
J1: LNCPU_ALUModule_Header; LNCPU_ALU_Module_Header
U1, U3: 74LS08; DIP-14_W7.62mm_LongPads
U2: 74HCT541; DIP-20_W7.62mm_LongPads

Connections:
/D0: J1.23 (D0), U2.18 (Y0)
/D1: J1.24 (D1), U2.17 (Y1)
/D2: J1.25 (D2), U2.16 (Y2)
/D3: J1.26 (D3), U2.15 (Y3)
/D4: J1.28 (D4), U2.14 (Y4)
/D5: J1.29 (D5), U2.13 (Y5)
/D6: J1.30 (D6), U2.12 (Y6)
/D7: J1.31 (D7), U2.11 (Y7)
/GND: C1.2, C2.1, C3.1, J1.1 (GND), J1.7 (GND), J1.12 (GND), J1.17 (GND), J1.22 (GND), J1.27 (GND), J1.32 (GND), J1.37 (GND), U1.7 (GND), U2.10 (GND), U3.7 (GND)
/VCC: C1.1, C2.2, C3.2, J1.2 (VCC), J1.38 (VCC), U1.14 (VCC), U2.20 (VCC), U3.14 (VCC)
/X0: J1.3 (X0), U3.2
/X1: J1.4 (X1), U3.5
/X2: J1.5 (X2), U3.10
/X3: J1.6 (X3), U3.13
/X4: J1.8 (X4), U1.2
/X5: J1.9 (X5), U1.5
/X6: J1.10 (X6), U1.10
/X7: J1.11 (X7), U1.13
/Y0: J1.13 (Y0), U3.1
/Y1: J1.14 (Y1), U3.4
/Y2: J1.15 (Y2), U3.9
/Y3: J1.16 (Y3), U3.12
/Y4: J1.18 (Y4), U1.1
/Y5: J1.19 (Y5), U1.4
/Y6: J1.20 (Y6), U1.9
/Y7: J1.21 (Y7), U1.12
/~ALU_{out}: J1.36 (~ALU_{out}), U2.19 (G2)
/~EN3: J1.34 (~EN1), U2.1 (G1)
unnamed: U2.2 (A0), U3.3
unnamed: U2.3 (A1), U3.6
unnamed: U2.4 (A2), U3.8
unnamed: U2.5 (A3), U3.11
unnamed: U1.3, U2.6 (A4)
unnamed: U1.6, U2.7 (A5)
unnamed: U1.8, U2.8 (A6)
unnamed: U1.11, U2.9 (A7)

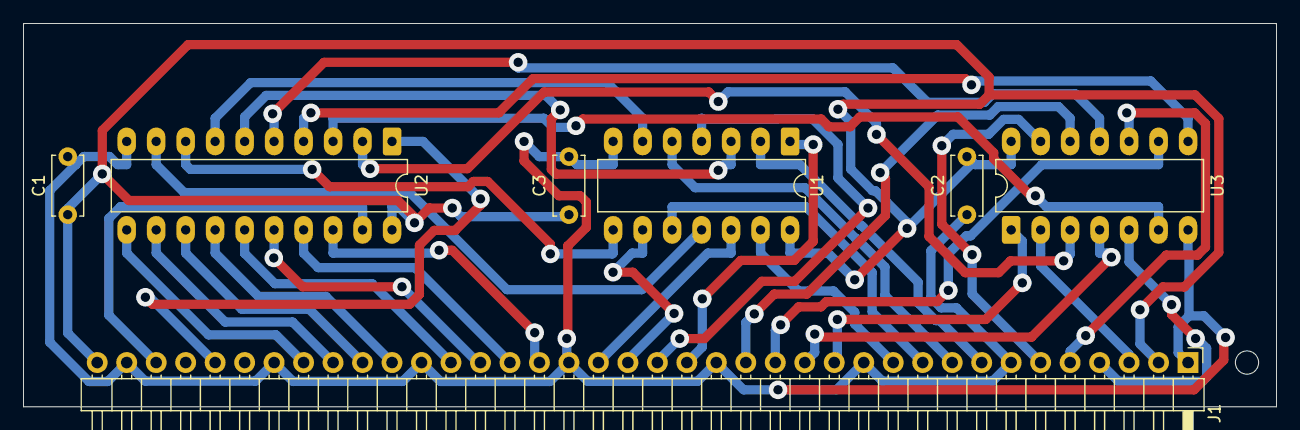
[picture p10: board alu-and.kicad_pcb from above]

Board: 2 copper layers, 108.0 x 33.0 mm, 7 parts (0 on the bottom side), 36 nets.

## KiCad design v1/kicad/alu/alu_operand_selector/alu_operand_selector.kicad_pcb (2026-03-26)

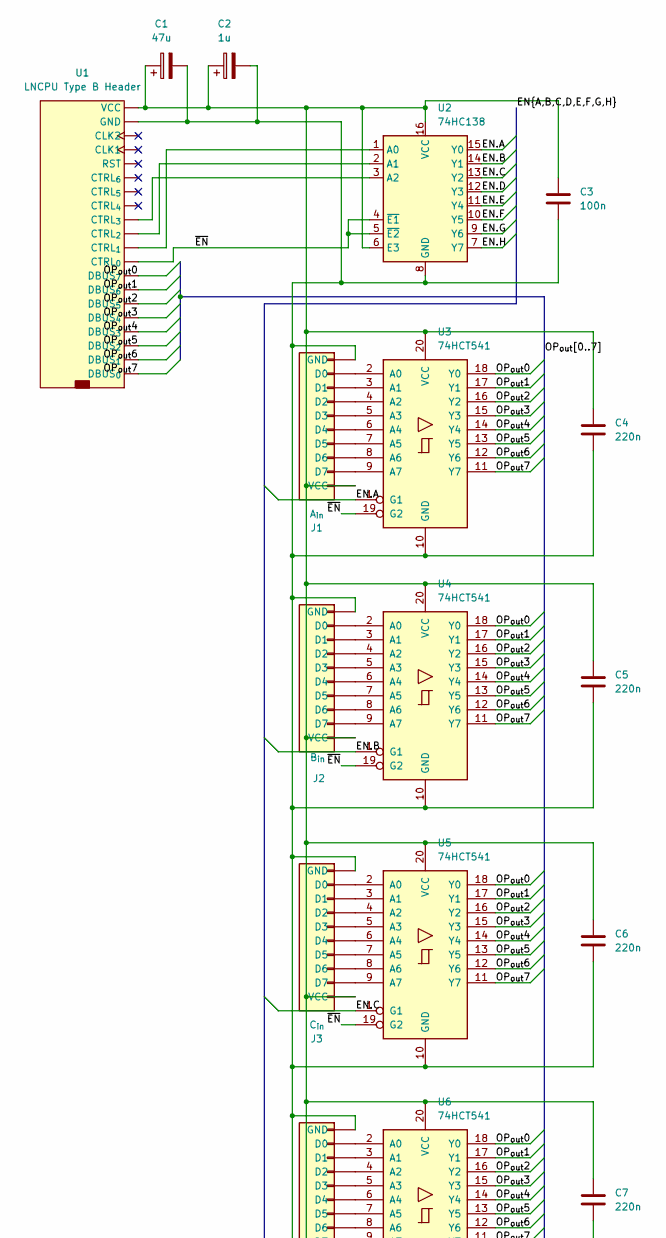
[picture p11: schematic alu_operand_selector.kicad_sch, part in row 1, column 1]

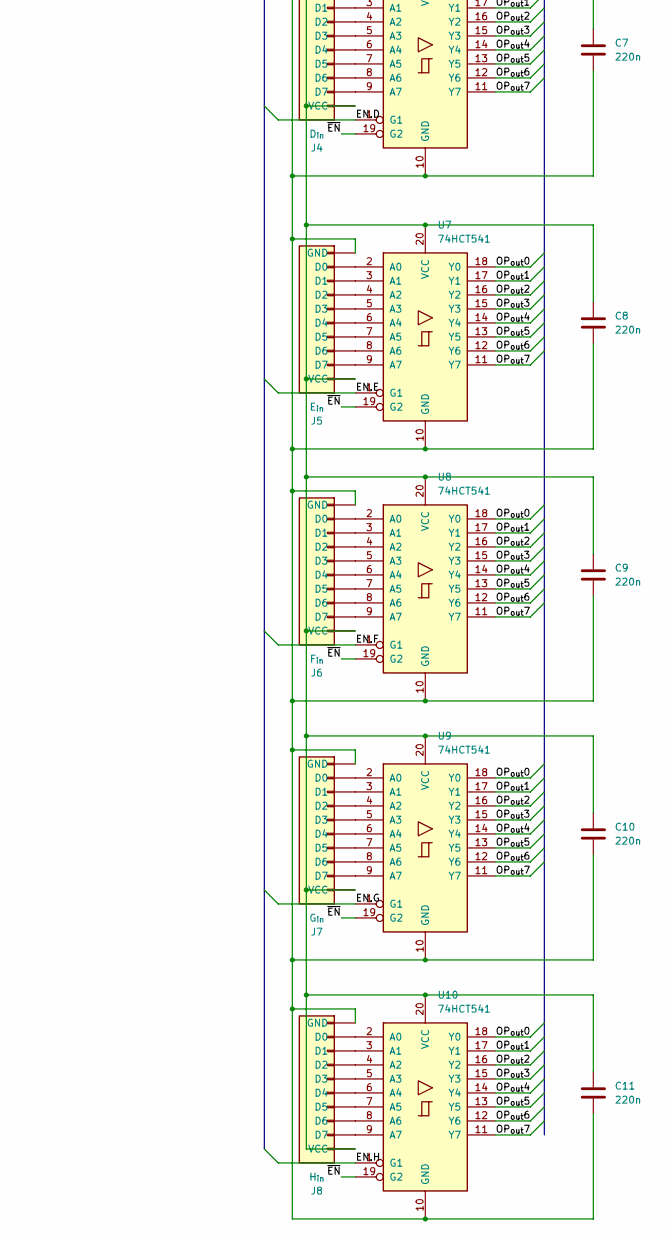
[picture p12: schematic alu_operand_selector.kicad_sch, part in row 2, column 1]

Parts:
C1: 47u; CP_Radial_D5.0mm_P2.00mm
C2: 1u; CP_Radial_D4.0mm_P2.00mm-Large-Holes
C3: 100n; C_Disc_D5.0mm_W2.5mm_P2.50mm
C4, C5, C6, C7, C8, C9, C10, C11: 220n; C_Disc_D5.0mm_W2.5mm_P2.50mm
J1: A_{in}; PinSocket_1x10_P2.54mm_Vertical
J2: B_{in}; PinSocket_1x10_P2.54mm_Vertical
J3: C_{in}; PinSocket_1x10_P2.54mm_Vertical
J4: D_{in}; PinSocket_1x10_P2.54mm_Vertical
J5: E_{in}; PinSocket_1x10_P2.54mm_Vertical
J6: F_{in}; PinSocket_1x10_P2.54mm_Vertical
J7: G_{in}; PinSocket_1x10_P2.54mm_Vertical
J8: H_{in}; PinSocket_1x10_P2.54mm_Vertical
U1: LNCPU Type B Header; LNCPU_Type_B_Header
U2: 74HC138; DIP-16_W7.62mm_LongPads
U3, U4, U5, U6, U7, U8, U9, U10: 74HCT541; DIP-20_W7.62mm_LongPads

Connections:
/EN.A: U2.15 (Y0), U3.1 (G1)
/EN.B: U2.14 (Y1), U4.1 (G1)
/EN.C: U2.13 (Y2), U5.1 (G1)
/EN.D: U2.12 (Y3), U6.1 (G1)
/EN.E: U2.11 (Y4), U7.1 (G1)
/EN.F: U2.10 (Y5), U8.1 (G1)
/EN.G: U2.9 (Y6), U9.1 (G1)
/EN.H: U2.7 (Y7), U10.1 (G1)
/OP_{out}0: U1.17 (DBUS_{7}), U3.18 (Y0), U4.18 (Y0), U5.18 (Y0), U6.18 (Y0), U7.18 (Y0), U8.18 (Y0), U9.18 (Y0), U10.18 (Y0)
/OP_{out}1: U1.15 (DBUS_{6}), U3.17 (Y1), U4.17 (Y1), U5.17 (Y1), U6.17 (Y1), U7.17 (Y1), U8.17 (Y1), U9.17 (Y1), U10.17 (Y1)
/OP_{out}2: U1.13 (DBUS_{5}), U3.16 (Y2), U4.16 (Y2), U5.16 (Y2), U6.16 (Y2), U7.16 (Y2), U8.16 (Y2), U9.16 (Y2), U10.16 (Y2)
/OP_{out}3: U1.11 (DBUS_{4}), U3.15 (Y3), U4.15 (Y3), U5.15 (Y3), U6.15 (Y3), U7.15 (Y3), U8.15 (Y3), U9.15 (Y3), U10.15 (Y3)
/OP_{out}4: U1.9 (DBUS_{3}), U3.14 (Y4), U4.14 (Y4), U5.14 (Y4), U6.14 (Y4), U7.14 (Y4), U8.14 (Y4), U9.14 (Y4), U10.14 (Y4)
/OP_{out}5: U1.7 (DBUS_{2}), U3.13 (Y5), U4.13 (Y5), U5.13 (Y5), U6.13 (Y5), U7.13 (Y5), U8.13 (Y5), U9.13 (Y5), U10.13 (Y5)
/OP_{out}6: U1.5 (DBUS_{1}), U3.12 (Y6), U4.12 (Y6), U5.12 (Y6), U6.12 (Y6), U7.12 (Y6), U8.12 (Y6), U9.12 (Y6), U10.12 (Y6)
/OP_{out}7: U1.3 (DBUS_{0}), U3.11 (Y7), U4.11 (Y7), U5.11 (Y7), U6.11 (Y7), U7.11 (Y7), U8.11 (Y7), U9.11 (Y7), U10.11 (Y7)
/~EN: U1.4 (CTRL_{0}), U2.4 (~E1), U2.5 (~E2), U3.19 (G2), U4.19 (G2), U5.19 (G2), U6.19 (G2), U7.19 (G2), U8.19 (G2), U9.19 (G2), U10.19 (G2)
unnamed: J1.2 (D0), U3.2 (A0)
unnamed: J1.3 (D1), U3.3 (A1)
unnamed: J1.4 (D2), U3.4 (A2)
unnamed: J1.5 (D3), U3.5 (A3)
unnamed: J1.6 (D4), U3.6 (A4)
unnamed: J1.7 (D5), U3.7 (A5)
unnamed: J1.8 (D6), U3.8 (A6)
unnamed: J1.9 (D7), U3.9 (A7)
unnamed: C1.2, C2.2, C3.2, C4.2, C5.2, C6.2, C7.2, C8.2, C9.2, C10.2, C11.2, J1.1 (GND), J2.1 (GND), J3.1 (GND), J4.1 (GND), J5.1 (GND), J6.1 (GND), J7.1 (GND), J8.1 (GND), U1.1 (GND), U1.18 (GND), U1.22 (GND), U1.23 (GND), U2.8 (GND), U3.10 (GND), U4.10 (GND), U5.10 (GND), U6.10 (GND), U7.10 (GND), U8.10 (GND), U9.10 (GND), U10.10 (GND)
unnamed: C1.1, C2.1, C3.1, C4.1, C5.1, C6.1, C7.1, C8.1, C9.1, C10.1, C11.1, J1.10 (VCC), J2.10 (VCC), J3.10 (VCC), J4.10 (VCC), J5.10 (VCC), J6.10 (VCC), J7.10 (VCC), J8.10 (VCC), U1.2 (VCC), U1.24 (VCC), U2.6 (E3), U2.16 (VCC), U3.20 (VCC), U4.20 (VCC), U5.20 (VCC), U6.20 (VCC), U7.20 (VCC), U8.20 (VCC), U9.20 (VCC), U10.20 (VCC)
unnamed: J2.2 (D0), U4.2 (A0)
unnamed: J2.3 (D1), U4.3 (A1)
unnamed: J2.4 (D2), U4.4 (A2)
unnamed: J2.5 (D3), U4.5 (A3)
unnamed: J2.6 (D4), U4.6 (A4)
unnamed: J2.7 (D5), U4.7 (A5)
unnamed: J2.8 (D6), U4.8 (A6)
unnamed: J2.9 (D7), U4.9 (A7)
unnamed: J3.2 (D0), U5.2 (A0)
unnamed: J3.3 (D1), U5.3 (A1)
unnamed: J3.4 (D2), U5.4 (A2)
unnamed: J3.5 (D3), U5.5 (A3)
unnamed: J3.6 (D4), U5.6 (A4)
unnamed: J3.7 (D5), U5.7 (A5)
unnamed: J3.8 (D6), U5.8 (A6)
unnamed: J3.9 (D7), U5.9 (A7)
unnamed: J4.2 (D0), U6.2 (A0)
unnamed: J4.3 (D1), U6.3 (A1)
unnamed: J4.4 (D2), U6.4 (A2)
unnamed: J4.5 (D3), U6.5 (A3)
unnamed: J4.6 (D4), U6.6 (A4)
unnamed: J4.7 (D5), U6.7 (A5)
unnamed: J4.8 (D6), U6.8 (A6)
unnamed: J4.9 (D7), U6.9 (A7)
unnamed: J5.2 (D0), U7.2 (A0)
unnamed: J5.3 (D1), U7.3 (A1)
unnamed: J5.4 (D2), U7.4 (A2)
unnamed: J5.5 (D3), U7.5 (A3)
unnamed: J5.6 (D4), U7.6 (A4)
unnamed: J5.7 (D5), U7.7 (A5)
unnamed: J5.8 (D6), U7.8 (A6)
unnamed: J5.9 (D7), U7.9 (A7)
unnamed: J6.2 (D0), U8.2 (A0)
unnamed: J6.3 (D1), U8.3 (A1)
unnamed: J6.4 (D2), U8.4 (A2)
unnamed: J6.5 (D3), U8.5 (A3)
unnamed: J6.6 (D4), U8.6 (A4)
unnamed: J6.7 (D5), U8.7 (A5)
unnamed: J6.8 (D6), U8.8 (A6)
unnamed: J6.9 (D7), U8.9 (A7)
unnamed: J7.2 (D0), U9.2 (A0)
unnamed: J7.3 (D1), U9.3 (A1)
unnamed: J7.4 (D2), U9.4 (A2)
unnamed: J7.5 (D3), U9.5 (A3)
unnamed: J7.6 (D4), U9.6 (A4)
unnamed: J7.7 (D5), U9.7 (A5)
unnamed: J7.8 (D6), U9.8 (A6)
unnamed: J7.9 (D7), U9.9 (A7)
unnamed: J8.2 (D0), U10.2 (A0)
unnamed: J8.3 (D1), U10.3 (A1)
unnamed: J8.4 (D2), U10.4 (A2)
unnamed: J8.5 (D3), U10.5 (A3)
unnamed: J8.6 (D4), U10.6 (A4)
unnamed: J8.7 (D5), U10.7 (A5)
unnamed: J8.8 (D6), U10.8 (A6)
unnamed: J8.9 (D7), U10.9 (A7)
unnamed: U1.6 (CTRL_{1}), U2.1 (A0)
unnamed: U1.8 (CTRL_{2}), U2.2 (A1)
unnamed: U1.10 (CTRL_{3}), U2.3 (A2)

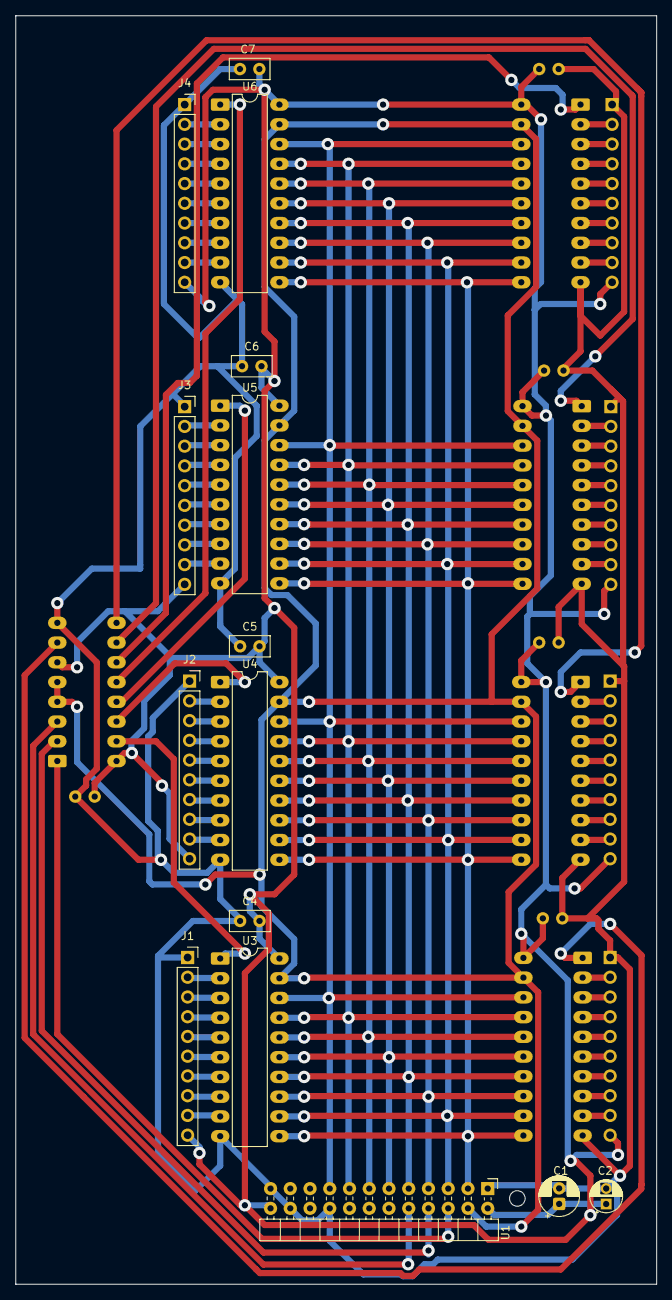
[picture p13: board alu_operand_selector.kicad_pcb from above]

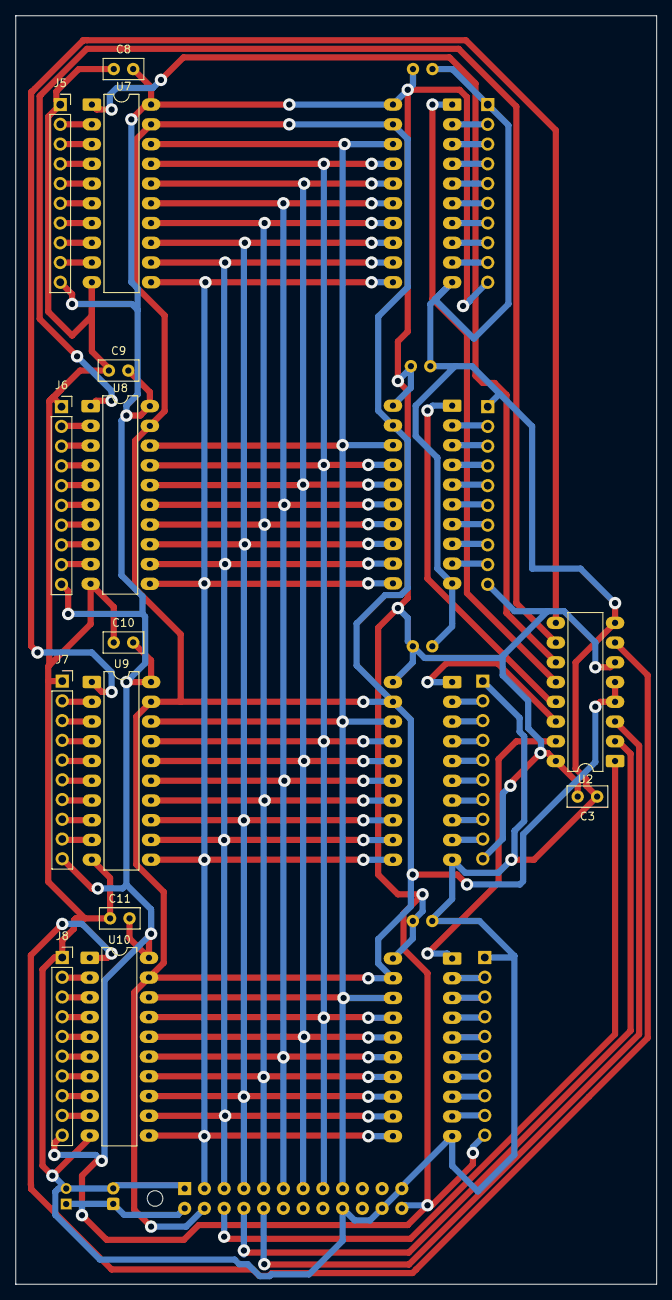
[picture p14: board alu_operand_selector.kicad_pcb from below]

Board: 2 copper layers, 82.5 x 163.2 mm, 29 parts (14 on the bottom side), 86 nets.

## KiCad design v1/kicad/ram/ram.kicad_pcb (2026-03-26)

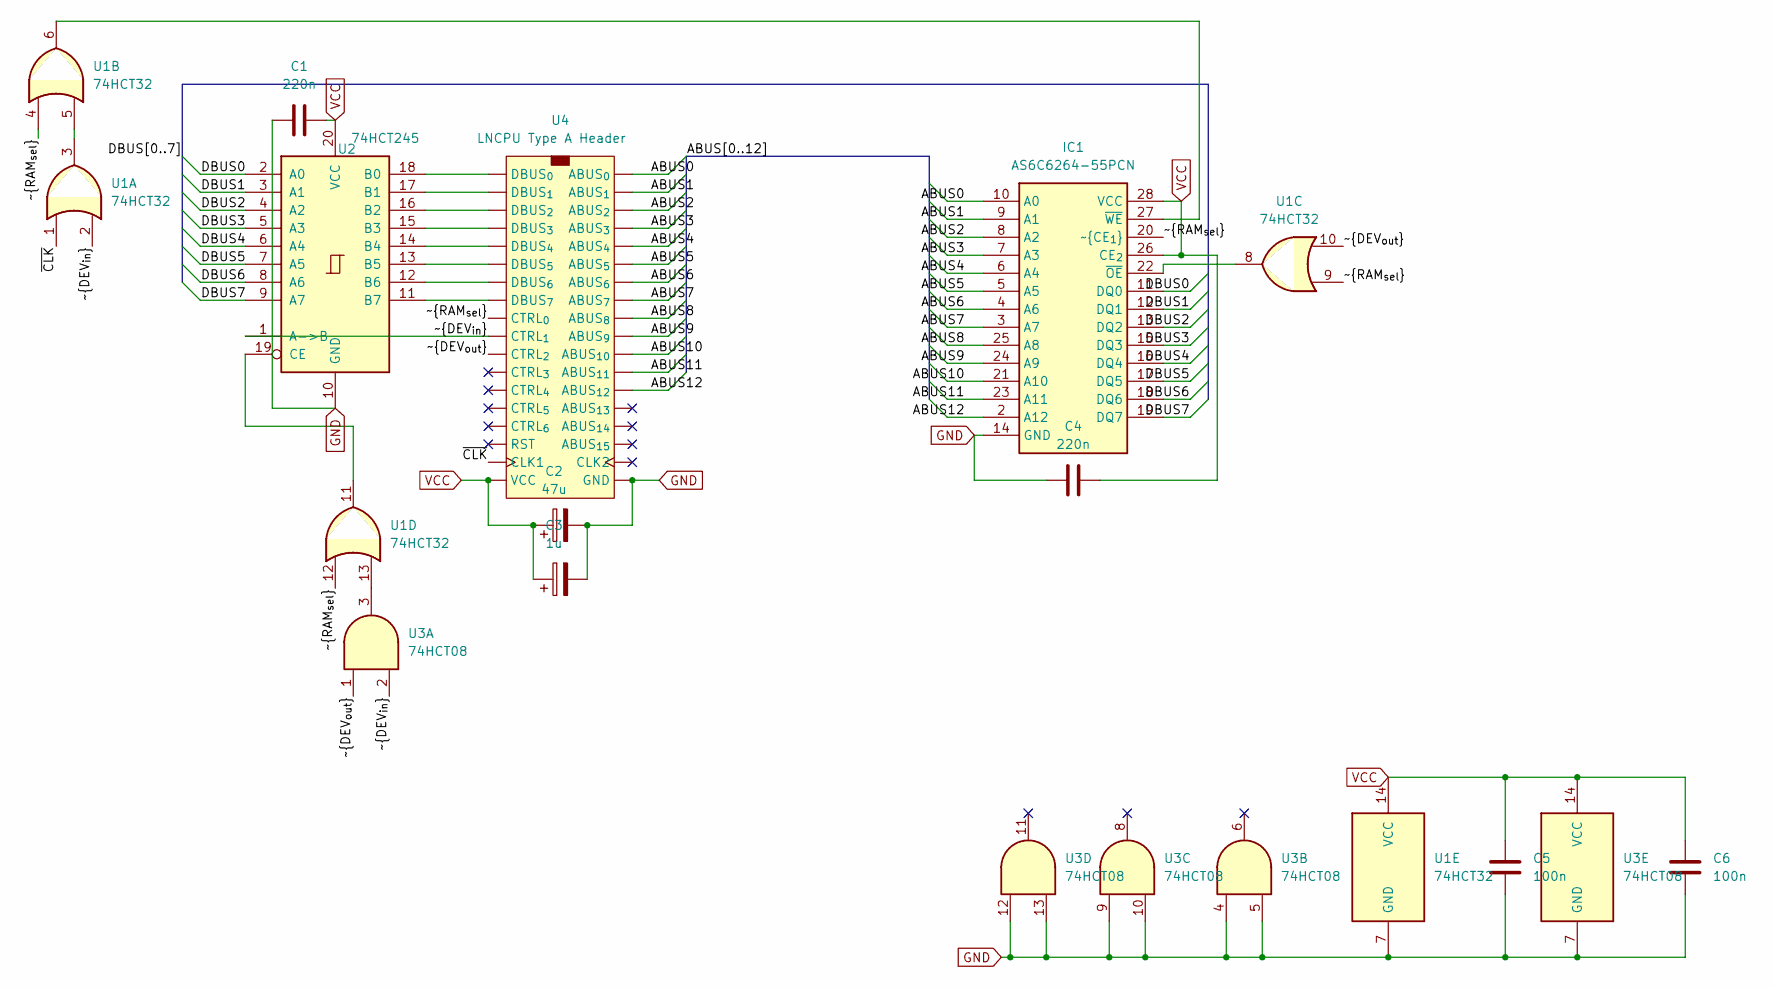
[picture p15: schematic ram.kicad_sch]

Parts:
C1, C4: 220n; C_Disc_D5.0mm_W2.5mm_P2.50mm
C2: 47u; CP_Radial_D5.0mm_P2.50mm
C3: 1u; CP_Radial_D4.0mm_P2.00mm-Large-Holes
C5, C6: 100n; C_Disc_D5.0mm_W2.5mm_P2.50mm
IC1: AS6C6264-55PCN; DIP1524W51P254L3632H394Q28N; Mouser Part Number 913-AS6C6264-55PCN
U1: 74HCT32; DIP-14_W7.62mm_LongPads
U2: 74HCT245; DIP-20_W7.62mm_LongPads
U3: 74HCT08; DIP-14_W7.62mm_LongPads
U4: LNCPU Type A Header; LNCPU_Type_A_Header

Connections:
/ABUS0: IC1.10 (A0), U4.4 (ABUS_{0})
/ABUS1: IC1.9 (A1), U4.6 (ABUS_{1})
/ABUS2: IC1.8 (A2), U4.8 (ABUS_{2})
/ABUS3: IC1.7 (A3), U4.10 (ABUS_{3})
/ABUS4: IC1.6 (A4), U4.12 (ABUS_{4})
/ABUS5: IC1.5 (A5), U4.14 (ABUS_{5})
/ABUS6: IC1.4 (A6), U4.16 (ABUS_{6})
/ABUS7: IC1.3 (A7), U4.18 (ABUS_{7})
/ABUS8: IC1.25 (A8), U4.20 (ABUS_{8})
/ABUS9: IC1.24 (A9), U4.22 (ABUS_{9})
/ABUS10: IC1.21 (A10), U4.24 (ABUS_{10})
/ABUS11: IC1.23 (A11), U4.26 (ABUS_{11})
/ABUS12: IC1.2 (A12), U4.28 (ABUS_{12})
/DBUS0: IC1.11 (DQ0), U2.2 (A0)
/DBUS1: IC1.12 (DQ1), U2.3 (A1)
/DBUS2: IC1.13 (DQ2), U2.4 (A2)
/DBUS3: IC1.15 (DQ3), U2.5 (A3)
/DBUS4: IC1.16 (DQ4), U2.6 (A4)
/DBUS5: IC1.17 (DQ5), U2.7 (A5)
/DBUS6: IC1.18 (DQ6), U2.8 (A6)
/DBUS7: IC1.19 (DQ7), U2.9 (A7)
/~CLK: U1.1, U4.35 (CLK1)
/~DEV_{in}: U1.2, U2.1 (A->B), U3.2, U4.5 (CTRL_{1})
/~DEV_{out}: U1.10, U3.1, U4.7 (CTRL_{2})
/~RAM_{sel}: IC1.20 (~CE_{1}), U1.4, U1.9, U1.12, U4.3 (CTRL_{0})
GND: C1.1, C2.2, C3.2, C4.1, C5.1, C6.1, IC1.14 (GND), U1.7 (GND), U2.10 (GND), U3.4, U3.5, U3.7 (GND), U3.9, U3.10, U3.12, U3.13, U4.1 (GND), U4.37 (GND), U4.38 (GND), U4.39 (GND)
unnamed: IC1.22 (~OE), U1.8
unnamed: IC1.27 (~WE), U1.6
unnamed: U1.3, U1.5
unnamed: U1.13, U3.3
unnamed: U2.18 (B0), U4.19 (DBUS_{0})
unnamed: U2.17 (B1), U4.21 (DBUS_{1})
unnamed: U2.16 (B2), U4.23 (DBUS_{2})
unnamed: U2.15 (B3), U4.25 (DBUS_{3})
unnamed: U2.14 (B4), U4.27 (DBUS_{4})
unnamed: U2.13 (B5), U4.29 (DBUS_{5})
unnamed: U2.12 (B6), U4.31 (DBUS_{6})
unnamed: U2.11 (B7), U4.33 (DBUS_{7})
unnamed: U1.11, U2.19 (CE)
VCC: C1.2, C2.1, C3.1, C4.2, C5.2, C6.2, IC1.26 (CE_{2}), IC1.28 (VCC), U1.14 (VCC), U2.20 (VCC), U3.14 (VCC), U4.2 (VCC), U4.40 (VCC)

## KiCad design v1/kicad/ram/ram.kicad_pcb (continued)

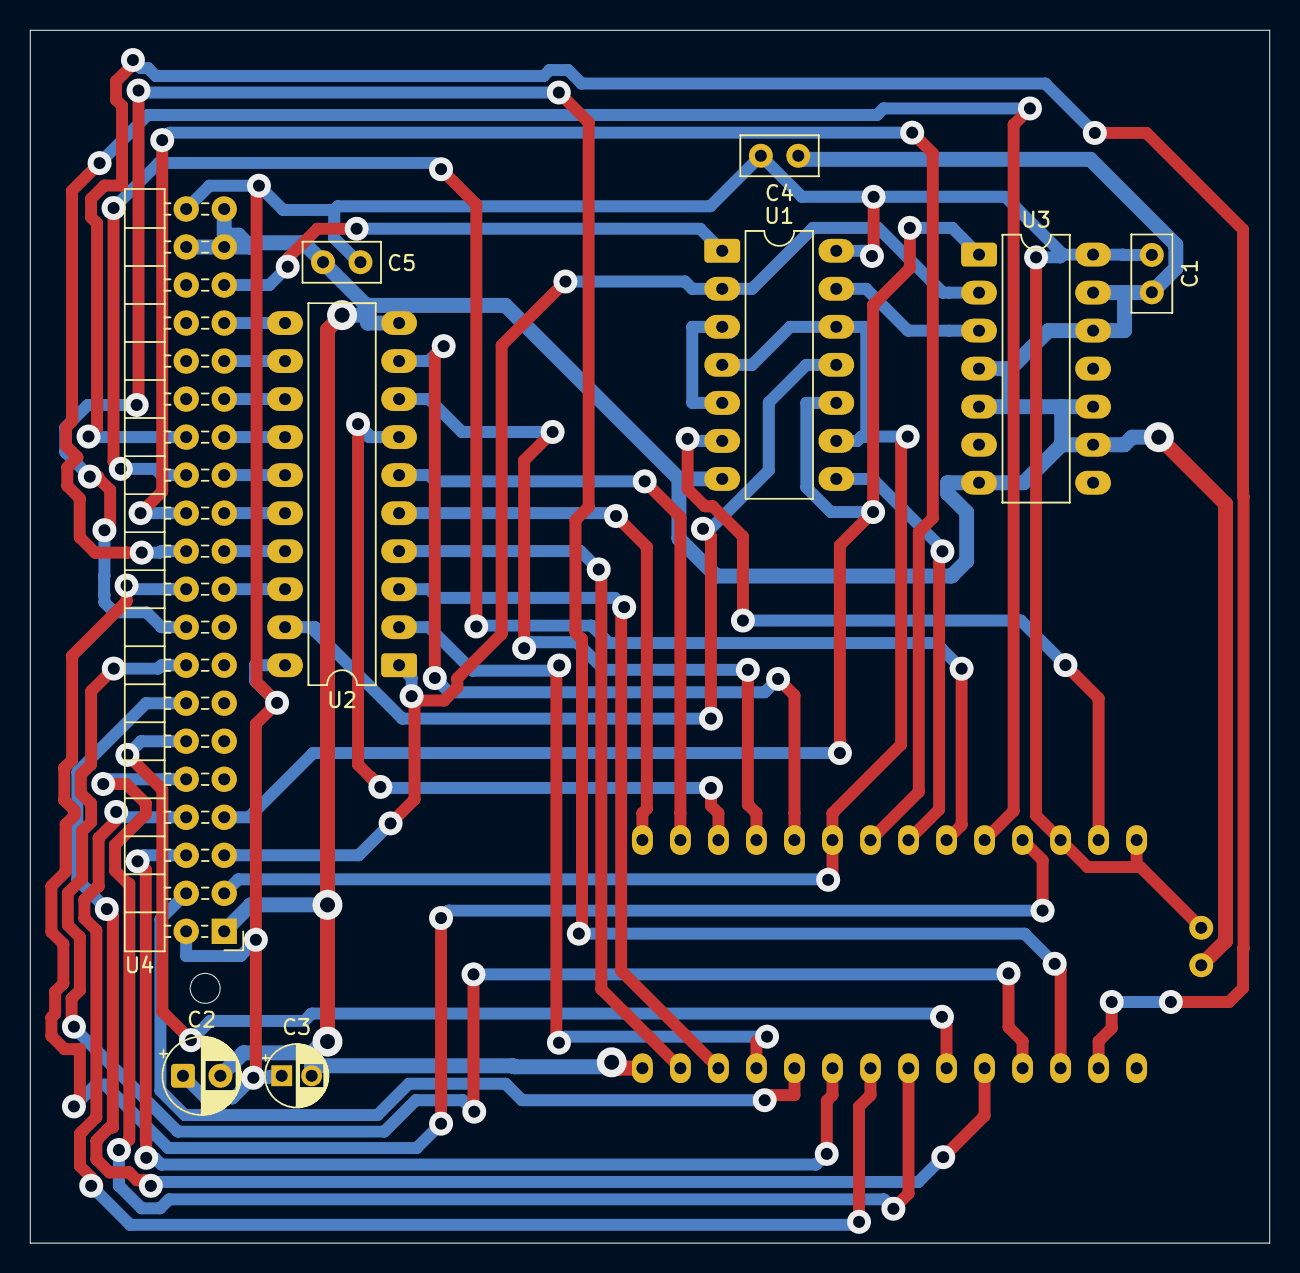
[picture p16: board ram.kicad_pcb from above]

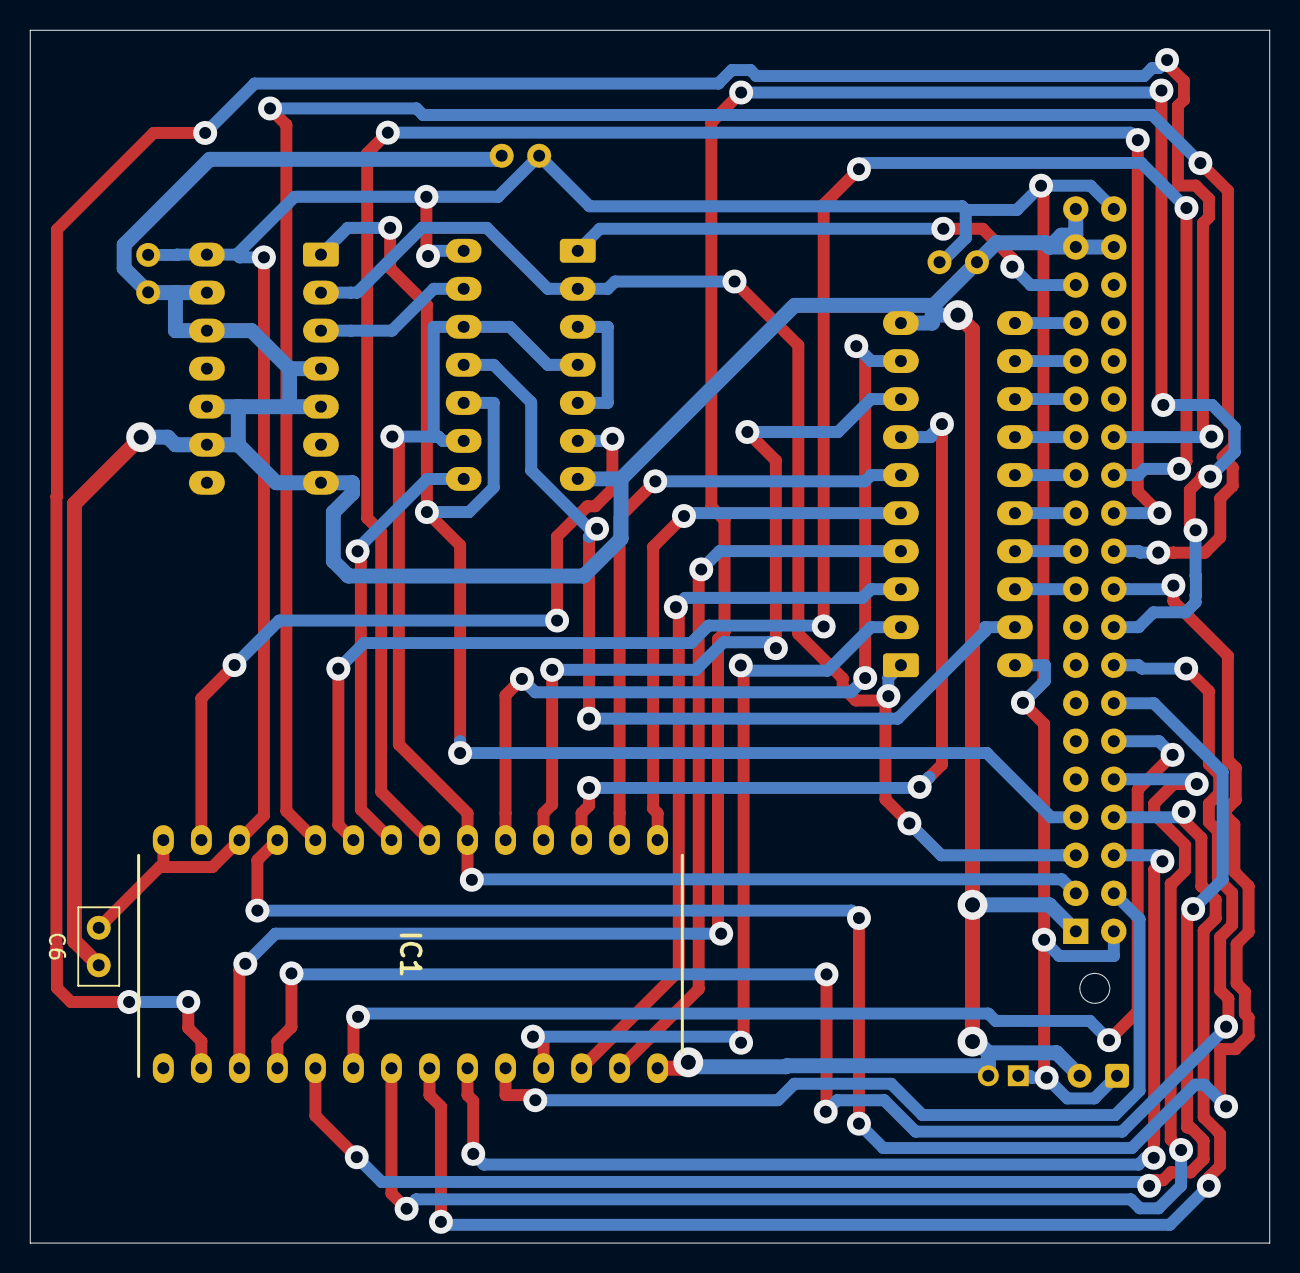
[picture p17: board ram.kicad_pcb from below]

Board: 2 copper layers, 82.8 x 81.0 mm, 11 parts (2 on the bottom side), 40 nets.

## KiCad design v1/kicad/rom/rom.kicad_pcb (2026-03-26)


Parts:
C1, C2: 220n; C_Disc_D5.0mm_W2.5mm_P2.50mm
C3: 47u; CP_Radial_D5.0mm_P2.00mm
C4: 1u; CP_Radial_D4.0mm_P2.00mm-Large-Holes
IC1: AT28C64B-15PU; DIP1556W56P254L3702H483Q28N; Manufacturer_Part_Number AT28C64B-15PU; Mouser Part Number 556-AT28C64B15PU
U1: LNCPU Type A Header; LNCPU_Type_A_Header
U2: 74HCT541; DIP-20_W7.62mm_LongPads

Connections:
/DBUS0: IC1.11 (I/O0), U2.2 (A0)
/DBUS1: IC1.12 (I/O1), U2.3 (A1)
/DBUS2: IC1.13 (I/O2), U2.4 (A2)
/DBUS3: IC1.15 (I/O3), U2.5 (A3)
/DBUS4: IC1.16 (I/O4), U2.6 (A4)
/DBUS5: IC1.17 (I/O5), U2.7 (A5)
/DBUS6: IC1.18 (I/O6), U2.8 (A6)
/DBUS7: IC1.19 (I/O7), U2.9 (A7)
unnamed: IC1.10 (A0), U1.4 (ABUS_{0})
unnamed: IC1.9 (A1), U1.6 (ABUS_{1})
unnamed: IC1.8 (A2), U1.8 (ABUS_{2})
unnamed: IC1.7 (A3), U1.10 (ABUS_{3})
unnamed: IC1.6 (A4), U1.12 (ABUS_{4})
unnamed: IC1.5 (A5), U1.14 (ABUS_{5})
unnamed: IC1.4 (A6), U1.16 (ABUS_{6})
unnamed: IC1.3 (A7), U1.18 (ABUS_{7})
unnamed: IC1.25 (A8), U1.20 (ABUS_{8})
unnamed: IC1.24 (A9), U1.22 (ABUS_{9})
unnamed: IC1.21 (A10), U1.24 (ABUS_{10})
unnamed: IC1.23 (A11), U1.26 (ABUS_{11})
unnamed: IC1.2 (A12), U1.28 (ABUS_{12})
unnamed: C1.2, C2.2, C3.2, C4.2, IC1.14 (GND), U1.1 (GND), U1.37 (GND), U1.38 (GND), U1.39 (GND), U2.10 (GND)
unnamed: C1.1, C2.1, C3.1, C4.1, IC1.27 (~WE), IC1.28 (VCC), U1.2 (VCC), U1.40 (VCC), U2.20 (VCC)
unnamed: IC1.20 (~CE), U1.3 (CTRL_{0}), U2.19 (G2)
unnamed: IC1.22 (~OE), U1.5 (CTRL_{1}), U2.1 (G1)
unnamed: U1.19 (DBUS_{0}), U2.18 (Y0)
unnamed: U1.21 (DBUS_{1}), U2.17 (Y1)
unnamed: U1.23 (DBUS_{2}), U2.16 (Y2)
unnamed: U1.25 (DBUS_{3}), U2.15 (Y3)
unnamed: U1.27 (DBUS_{4}), U2.14 (Y4)
unnamed: U1.29 (DBUS_{5}), U2.13 (Y5)
unnamed: U1.31 (DBUS_{6}), U2.12 (Y6)
unnamed: U1.33 (DBUS_{7}), U2.11 (Y7)


Board: 2 copper layers, 65.5 x 77.0 mm, 7 parts (0 on the bottom side), 33 nets.

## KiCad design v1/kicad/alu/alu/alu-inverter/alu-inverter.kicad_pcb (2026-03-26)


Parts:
C1: 220n; C_Disc_D5.0mm_W2.5mm_P5.00mm
C2, C3: 100n; C_Disc_D5.0mm_W2.5mm_P5.00mm
J1: LNCPU_ALUModule_Header; LNCPU_ALU_Module_Header
U1: 74HCT541; DIP-20_W7.62mm_LongPads
U2, U3: 74LS04; DIP-14_W7.62mm_LongPads

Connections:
/D0: J1.23 (D0), U1.18 (Y0)
/D1: J1.24 (D1), U1.17 (Y1)
/D2: J1.25 (D2), U1.16 (Y2)
/D3: J1.26 (D3), U1.15 (Y3)
/D4: J1.28 (D4), U1.14 (Y4)
/D5: J1.29 (D5), U1.13 (Y5)
/D6: J1.30 (D6), U1.12 (Y6)
/D7: J1.31 (D7), U1.11 (Y7)
/GND: C1.2, C2.1, C3.1, J1.1 (GND), J1.7 (GND), J1.12 (GND), J1.17 (GND), J1.22 (GND), J1.27 (GND), J1.32 (GND), J1.37 (GND), U1.10 (GND), U2.5, U2.7 (GND), U2.9, U2.11, U2.13, U3.7 (GND)
/VCC: C1.1, C2.2, C3.2, J1.2 (VCC), J1.38 (VCC), U1.20 (VCC), U2.14 (VCC), U3.14 (VCC)
/X0: J1.3 (X0), U2.1
/X1: J1.4 (X1), U2.3
/X2: J1.5 (X2), U3.1
/X3: J1.6 (X3), U3.3
/X4: J1.8 (X4), U3.5
/X5: J1.9 (X5), U3.9
/X6: J1.10 (X6), U3.11
/X7: J1.11 (X7), U3.13
/~ALU_{out}: J1.36 (~ALU_{out}), U1.19 (G2)
/~EN6: J1.34 (~EN1), U1.1 (G1)
unnamed: U1.2 (A0), U2.2
unnamed: U1.3 (A1), U2.4
unnamed: U1.4 (A2), U3.2
unnamed: U1.5 (A3), U3.4
unnamed: U1.6 (A4), U3.6
unnamed: U1.7 (A5), U3.8
unnamed: U1.8 (A6), U3.10
unnamed: U1.9 (A7), U3.12


Board: 2 copper layers, 112.3 x 36.1 mm, 7 parts (0 on the bottom side), 28 nets.

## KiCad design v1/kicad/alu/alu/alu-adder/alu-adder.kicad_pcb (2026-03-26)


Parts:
C1, C3, C4, C5, C6, C7, C8: 100n; C_Disc_D5.0mm_W2.5mm_P5.00mm
C2: 220n; C_Disc_D5.0mm_W2.5mm_P5.00mm
J1: LNCPU_ALUModule_Header; LNCPU_ALU_Module_Header
U1, U3, U7: 74LS86; DIP-14_W7.62mm_LongPads
U2: 74HCT541; DIP-20_W7.62mm_LongPads
U4: 74LS08; DIP-14_W7.62mm_LongPads
U5, U8: 74LS283; DIP-16_W7.62mm_LongPads
U6: 74LS04; DIP-14_W7.62mm_LongPads

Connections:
/Cout: J1.33 (X), U4.3
/D0: J1.23 (D0), U2.18 (Y0)
/D1: J1.24 (D1), U2.17 (Y1)
/D2: J1.25 (D2), U2.16 (Y2)
/D3: J1.26 (D3), U2.15 (Y3)
/D4: J1.28 (D4), U2.14 (Y4)
/D5: J1.29 (D5), U2.13 (Y5)
/D6: J1.30 (D6), U2.12 (Y6)
/D7: J1.31 (D7), U2.11 (Y7)
/GND: C1.1, C2.2, C3.1, C4.1, C5.2, C6.2, C7.1, C8.1, J1.1 (GND), J1.7 (GND), J1.12 (GND), J1.17 (GND), J1.22 (GND), J1.27 (GND), J1.32 (GND), J1.37 (GND), U1.7 (GND), U2.10 (GND), U3.7 (GND), U4.7 (GND), U4.9, U4.10, U4.12, U4.13, U5.8 (GND), U6.1, U6.3, U6.7 (GND), U6.11, U6.13, U7.4, U7.5, U7.7 (GND), U7.9, U7.10, U7.12, U7.13, U8.8 (GND)
/VCC: C1.2, C2.1, C3.2, C4.2, C5.1, C6.1, C7.2, C8.2, J1.2 (VCC), J1.38 (VCC), U1.14 (VCC), U2.20 (VCC), U3.14 (VCC), U4.14 (VCC), U5.16 (VCC), U6.14 (VCC), U7.14 (VCC), U8.16 (VCC)
/X0: J1.3 (X0), U8.5 (A1)
/X1: J1.4 (X1), U8.3 (A2)
/X2: J1.5 (X2), U8.14 (A3)
/X3: J1.6 (X3), U8.12 (A4)
/X4: J1.8 (X4), U5.5 (A1)
/X5: J1.9 (X5), U5.3 (A2)
/X6: J1.10 (X6), U5.14 (A3)
/X7: J1.11 (X7), U5.12 (A4)
/Y0: J1.13 (Y0), U1.2
/Y1: J1.14 (Y1), U1.5
/Y2: J1.15 (Y2), U1.10
/Y3: J1.16 (Y3), U1.13
/Y4: J1.18 (Y4), U3.2
/Y5: J1.19 (Y5), U3.5
/Y6: J1.20 (Y6), U3.10
/Y7: J1.21 (Y7), U3.13
/Y_{xor}EN2_{0}: U1.3, U8.6 (B1)
/Y_{xor}EN2_{1}: U1.6, U8.2 (B2)
/Y_{xor}EN2_{2}: U1.8, U8.15 (B3)
/Y_{xor}EN2_{3}: U1.11, U8.11 (B4)
/Y_{xor}EN2_{4}: U3.3, U5.6 (B1)
/Y_{xor}EN2_{5}: U3.6, U5.2 (B2)
/Y_{xor}EN2_{6}: U3.8, U5.15 (B3)
/Y_{xor}EN2_{7}: U3.11, U5.11 (B4)
/~ALU_{out}: J1.36 (~ALU_{out}), U2.19 (G2)
/~EN1: J1.34 (~EN1), U4.5
/~EN2: J1.35 (~EN2), U4.4, U6.5
unnamed: U2.2 (A0), U8.4 (S1)
unnamed: U2.3 (A1), U8.1 (S2)
unnamed: U2.4 (A2), U8.13 (S3)
unnamed: U2.5 (A3), U8.10 (S4)
unnamed: U2.6 (A4), U5.4 (S1)
unnamed: U2.7 (A5), U5.1 (S2)
unnamed: U2.8 (A6), U5.13 (S3)
unnamed: U2.9 (A7), U5.10 (S4)
unnamed: U2.1 (G1), U4.6, U6.9
unnamed: U4.1, U7.3
unnamed: U4.2, U6.8
unnamed: U5.7 (C0), U8.9 (C4)
unnamed: U5.9 (C4), U7.2
unnamed: U1.1, U1.4, U1.9, U1.12, U3.1, U3.4, U3.9, U3.12, U6.6, U7.1, U8.7 (C0)


Board: 2 copper layers, 138.4 x 67.9 mm, 17 parts (0 on the bottom side), 52 nets.

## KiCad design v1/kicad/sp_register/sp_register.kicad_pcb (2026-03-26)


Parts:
C1, C2, C4: 100n; C_Disc_D5.0mm_W2.5mm_P5.00mm
C3: 220n; C_Disc_D5.0mm_W2.5mm_P5.00mm
C5: 47uF; CP_Radial_D5.0mm_P2.00mm
C6: 1uF; CP_Radial_D4.0mm_P2.00mm-Large-Holes
J1: OP_{out}; PinSocket_1x10_P2.54mm_Vertical
U1: LNCPU Type B Connector; LNCPU_Type_B_Header
U2, U3: 74LS169; DIP-16_W7.62mm_LongPads
U4: 74HCT541; DIP-20_W7.62mm_LongPads
U5: 74HCT00; DIP-14_W7.62mm

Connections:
/DBUS0: J1.2 (D0), U1.4 (DBUS_{0}), U3.3 (P0), U4.18 (Y0)
/DBUS1: J1.3 (D1), U1.6 (DBUS_{1}), U3.4 (P1), U4.17 (Y1)
/DBUS2: J1.4 (D2), U1.8 (DBUS_{2}), U3.5 (P2), U4.16 (Y2)
/DBUS3: J1.5 (D3), U1.10 (DBUS_{3}), U3.6 (P3), U4.15 (Y3)
/DBUS4: J1.6 (D4), U1.12 (DBUS_{4}), U2.3 (P0), U4.14 (Y4)
/DBUS5: J1.7 (D5), U1.14 (DBUS_{5}), U2.4 (P1), U4.13 (Y5)
/DBUS6: J1.8 (D6), U1.16 (DBUS_{6}), U2.5 (P2), U4.12 (Y6)
/DBUS7: J1.9 (D7), U1.18 (DBUS_{7}), U2.6 (P3), U4.11 (Y7)
/GND: C1.2, C2.2, C3.2, C4.1, C5.2, C6.2, J1.1 (GND), U1.1 (GND), U1.17 (GND), U1.20 (GND), U1.22 (GND), U2.8 (GND), U3.8 (GND), U4.10 (GND), U5.7 (GND), U5.9, U5.10, U5.12, U5.13
/OUT0: U3.14 (Q0), U4.2 (A0)
/OUT1: U3.13 (Q1), U4.3 (A1)
/OUT2: U3.12 (Q2), U4.4 (A2)
/OUT3: U3.11 (Q3), U4.5 (A3)
/OUT4: U2.14 (Q0), U4.6 (A4)
/OUT5: U2.13 (Q1), U4.7 (A5)
/OUT6: U2.12 (Q2), U4.8 (A6)
/OUT7: U2.11 (Q3), U4.9 (A7)
/VCC: C1.1, C2.1, C3.1, C4.2, C5.1, C6.1, J1.10 (VCC), U1.2 (VCC), U1.24 (VCC), U2.16 (VCC), U3.16 (VCC), U4.20 (VCC), U5.14 (VCC)
unnamed: U1.21 (CLK1), U2.2 (CP), U3.2 (CP)
unnamed: U1.3 (CTRL_{0}), U2.1 (U/~D), U3.1 (U/~D), U5.4
unnamed: U1.5 (CTRL_{1}), U5.1, U5.2
unnamed: U1.7 (CTRL_{2}), U4.1 (G1)
unnamed: U1.9 (CTRL_{3}), U4.19 (G2)
unnamed: U2.7 (~CEP), U3.7 (~CEP), U3.10 (~CET), U5.3, U5.5
unnamed: U2.10 (~CET), U3.15 (~TC)
unnamed: U2.9 (~PE), U3.9 (~PE), U5.6


Board: 2 copper layers, 101.5 x 66.5 mm, 12 parts (0 on the bottom side), 26 nets.

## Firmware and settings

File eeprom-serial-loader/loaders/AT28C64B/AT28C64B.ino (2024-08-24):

/*  Created by: Lorenzo Notaro
 * 
 *  This sketch is the loader for the AT28C64B EEPROM chip.
 *  It was written for Arduino Nano and it conforms to the protocol defined in
 *  the loaders/ directory of this repository.
 *  The circuit associated with the sketch is illustrated in an adjacent file.
 *  Given the limited numbers of pins on the Arduino Nano, 
 *  3 4-bit counters are used to keep track of addresses A0-A11, while a digital pin 
 *  will determine which half of the EEPROM is active (A12).
 */

/* The protocol signature that will let the desktop app identify the serial port. */
#define PROTOCOL_SIGNATURE "EEPROMLD"

/* Name and revision of this loader. */
#define VERSION "AT28C64B, rev7\0"

/* The baud rate, as specified in the protocol.*/
#define BAUD_RATE 115200

/* For performance reasons this sketch doesn't use plain digitalWrite's for
   writing data to the EEPROM. Instead, it uses the port registers B and C
   (you can read more about port register at https://www.arduino.cc/en/Reference/PortManipulation).
   This port bitmask specifies which digits of each port we are using; the ports are conveniently set up
   so that the bitmask will be the same for both PORTB and PORTC. 
   Refer to the writeBus and readBus functions to see how this works.*/
#define PORT_BITMASK B00011110

/* The clock pin. */
#define CLOCK      3

/* The !reset pin of the 3 4-bin counters. */
#define NOT_RESET  4

/* The EEPROM !CE (chip enable) pin. */
#define ROM_NOT_CE 5

/* The EEPROM !OE (output enable) pin. */
#define ROM_NOT_OE 6

/* The EEPROM !WE (chip enable) pin. */
#define ROM_NOT_WE 7

/* The most significant digit of the address bus. */
#define A12        8

/* Green LED */
#define LED_OK     13

/* Red LED */
#define LED_ERROR  2

/* The duration of the clock pulse, in μs. */
#define PULSE_DURATION 1

/* The payload size. */
#define PAYLOAD (unsigned int) 64

/* The EEPROM size. */
#define ROM_SIZE  (unsigned int) 8192

/* This will store the payload every time we receive one from the client. */
byte payload[PAYLOAD];

bool _error, _success;
unsigned long lastErrorTime, lastSuccessTime;

void setup() {
  Serial.begin(BAUD_RATE);

  //initialize all the pins. 
  busMode(INPUT);
  pinMode(CLOCK, OUTPUT);
  pinMode(NOT_RESET, OUTPUT);
  pinMode(ROM_NOT_CE, OUTPUT);
  pinMode(ROM_NOT_OE, OUTPUT);
  pinMode(ROM_NOT_WE, OUTPUT);
  pinMode(A12, OUTPUT);
  pinMode(LED_OK, OUTPUT);
  pinMode(LED_ERROR, OUTPUT);

  //set each pin to their default (inactive) value
  digitalWrite(CLOCK, LOW);
  digitalWrite(NOT_RESET, HIGH);
  digitalWrite(ROM_NOT_OE, LOW);
  digitalWrite(ROM_NOT_CE, HIGH);
  digitalWrite(ROM_NOT_WE, HIGH);
  digitalWrite(A12, LOW);

  // Cycle LEDs to indicate setup complete
  _error = _success = true;
  lastErrorTime = lastSuccessTime = millis();
  digitalWrite(LED_OK, HIGH);
  digitalWrite(LED_ERROR, HIGH);
}

/* In the loop, the Arduino will be waiting for a request from the client and will act accordingly. */
void loop() {
  byte b;
  if(Serial.available() > 0){
    char c = Serial.read();
    switch(c){
      case 'v': //the client requested the loader signature and version
        Serial.write(PROTOCOL_SIGNATURE VERSION);
        break;
      case 'p': //the client requested the parameters for this loader
        write16(ROM_SIZE);
        write16(PAYLOAD);
        break;
      case 'w': 
        //the client requested to initiate a write cycle
        //we'll split the write cycles in two for loops, one with A12 on LOW and one with A12 on HIGH
        reset_counter();
        digitalWrite(A12, LOW);
        for(int i = 0; i < ROM_SIZE / PAYLOAD / 2; ++i){
          Serial.write('n');
          if(!read_payload_from_serial()){
            error();
            return;
          }
          write_eeprom();
        }
        reset_counter();
        digitalWrite(A12, HIGH);
        for(int i = 0; i < ROM_SIZE / PAYLOAD / 2; ++i){ //write cycle
          Serial.write('n'); //send control character
          if(!read_payload_from_serial()){
            error(); //error during serial read
            return;
          }
          write_eeprom();
        }
        digitalWrite(A12, LOW);
        Serial.write('k'); //send confirmation character
        success();
        break;
      case 'r':
        reset_counter();
        digitalWrite(A12, LOW);
        for(int i = 0; i < ROM_SIZE / PAYLOAD / 2; ++i){
          if(Serial.readBytes(&b, 1) <= 0 || b != 'n'){
            error();
            return;
          }
          read_payload_from_eeprom();
          Serial.write(payload, PAYLOAD);
        }
        reset_counter();
        digitalWrite(A12, HIGH);
        for(int i = 0; i < ROM_SIZE / PAYLOAD / 2; ++i){
          if(Serial.readBytes(&b, 1) <= 0 || b != 'n'){
            error();
            return;
          }
          read_payload_from_eeprom();
          Serial.write(payload, PAYLOAD);
        }
        digitalWrite(A12, LOW);
        break;
      default:
        Serial.write('?');
    }
  }
  if(_error && (millis() - lastErrorTime > 1000)){
    digitalWrite(LED_ERROR, LOW);
    _error = false;
  }
  if(_success && (millis() - lastSuccessTime > 1000)){
    digitalWrite(LED_OK, LOW);
    _success = false;
  }
}

void read_payload_from_eeprom(){
  busMode(INPUT);  

  digitalWrite(ROM_NOT_OE, HIGH);
  digitalWrite(ROM_NOT_CE, HIGH);
  digitalWrite(ROM_NOT_WE, HIGH);

  for(int i = 0; i < PAYLOAD; ++i){
    digitalWrite(ROM_NOT_CE, LOW);
    digitalWrite(ROM_NOT_OE, LOW);

    payload[i] = readBus();
    
    digitalWrite(ROM_NOT_OE, HIGH);
    digitalWrite(ROM_NOT_CE, HIGH);

    pulse(CLOCK);
  }
}

void write_eeprom(){
  //We are using page write mode on the AT28C64B, as explained in the datasheet
  busMode(OUTPUT);
  digitalWrite(ROM_NOT_OE, HIGH);
  digitalWrite(ROM_NOT_WE, HIGH);
  digitalWrite(ROM_NOT_CE, HIGH);

  for(int i = 0; i < PAYLOAD / 64; ++i){
    for(int j = 0; j < 64; j++){
        digitalWrite(ROM_NOT_CE, LOW);
        digitalWrite(ROM_NOT_WE, LOW);
        writeBus(payload[j]);
        digitalWrite(ROM_NOT_WE, HIGH);
        digitalWrite(ROM_NOT_CE, HIGH);
        pulse(CLOCK);
    }
    digitalWrite(ROM_NOT_OE, LOW);
  }

  digitalWrite(ROM_NOT_OE, HIGH);
  digitalWrite(ROM_NOT_CE, HIGH);
  digitalWrite(ROM_NOT_WE, HIGH);
}

void reset_counter(){
  digitalWrite(NOT_RESET, LOW);
  pulse(CLOCK);
  digitalWrite(NOT_RESET, HIGH);
}

bool read_payload_from_serial(){
  int count = Serial.readBytes(payload, PAYLOAD);
  return count == PAYLOAD;
}

byte readBus(){
    return ((PINB & PORT_BITMASK) >> 1) + ((PINC & PORT_BITMASK) << 3); //We do the inverse of the shifts we did in writeBus()
}

void writeBus(byte val){
  //The first and sixth digit of PORTB (pin number 8 and 13) so we want to save whatever values are in those bits
  //We want the last 4 bits of val (B00001111) to be positioned B00011110 in PORTB: shift 1 to the left
  PORTB = (PORTB & B00100001) | ((val << 1) & PORT_BITMASK);
  //We want the first 4 bits of val (B11110000) to be positioned B00011110 in PORTC: shift 3 to the right
  PORTC = (val >> 3) & PORT_BITMASK;
}

void busMode(int mode){
  DDRC = DDRB = mode == OUTPUT ? 0xFF : 0x00;  
  DDRB |= B00100001; //The first and sixth digit of PORTB (pin number 8 and 13) are being used for A12 and OK LED: they are always outputs
}

void pulse(int pin){
  digitalWrite(pin, HIGH);
  delayMicroseconds(PULSE_DURATION);
  digitalWrite(pin, LOW);
}

void lowPulse(int pin){
  digitalWrite(pin, LOW);
  delayMicroseconds(PULSE_DURATION);
  digitalWrite(pin, HIGH);
}

void write16(unsigned int val){
  byte buf[2];
  buf[0] = (val >> 8) & 0xFF;
  buf[1] = val & 0xFF;
  Serial.write(buf, 2);
}

void error(){
  Serial.write('!');
  digitalWrite(LED_ERROR, HIGH);
  _error = true;
  lastErrorTime = millis();
}

void success(){
  _success = true;
  digitalWrite(LED_OK, HIGH);
  lastSuccessTime = millis();
}

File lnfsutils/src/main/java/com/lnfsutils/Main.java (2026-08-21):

package com.lnfsutils;

import java.io.IOException;
import java.nio.file.Path;

import com.lnfsutils.lnfs.LNFS;
import com.lnfsutils.packer.LNFSFileWriter;
import com.lnfsutils.packer.LNFSBinaryWriter;
import com.lnfsutils.packer.LNFSDirectoryBuilder;
import com.lnfsutils.unpacker.LNFSUnpackWriter;
import com.lnfsutils.unpacker.LNFSUnpacker;

public class Main {

    public static final String DEFAULT_SETTINGS_FILE = "defaultSettings.json";
    public static final String PROGRAM_NAME = "lnfsutils";
	private static final String VERSION = "1.1.0";
    public static ProgramSettings programSettings;

    public static void main(String[] args) {
        if(!parseArgs(args))
            System.exit(0);

        RunMode mode = validateArgs();

        if(mode == RunMode.PACK) {
            runPack();
        } else {
            runUnpack();
        }
    }

    private static void runPack() {
        try {
            LNFSDirectoryBuilder fs = new LNFSDirectoryBuilder(programSettings);

            LNFS lnfs = fs.build(Path.of(programSettings.getSourceFiles().get(0)));

            if (programSettings.get("--stdout", Boolean.class)){
                LNFSBinaryWriter writer = new LNFSBinaryWriter(System.out);
                writer.write(lnfs);
            }else{
                String outputFile = programSettings.get("--out", String.class);

                try(var packer = new LNFSFileWriter(Path.of(outputFile))){
                    packer.write(lnfs);
                }

            }


        } catch (LNFSException e) {
            Logger.error("Error building LNFS filesystem: " + e.getMessage());
            System.exit(1);
        } catch (IOException e) {
            Logger.error("Error writing LNFS filesystem to output file: " + e.getMessage());
            System.exit(1);
        }
    }

    private static void runUnpack(){
        try {
            ILNFSBuilder unpacker = new LNFSUnpacker();
            LNFS lnfs = unpacker.build(Path.of(programSettings.getSourceFiles().get(0)));

            LNFSUnpackWriter writer = new LNFSUnpackWriter(Path.of(programSettings.get("--out", String.class)));
            writer.write(lnfs);
        }catch(LNFSException | IOException e){
            Logger.error("Error unpacking LNFS filesystem: " + e.getMessage());
            System.exit(1);
        }
    }

    private static RunMode validateArgs() {

        RunMode mode = null;

        if (programSettings.get("--version", Boolean.class)) {
            System.out.println(PROGRAM_NAME + " version " + VERSION);
            System.exit(0);
            
        }

        if(programSettings.get("--help", Boolean.class)){
            System.out.println("lnfsutils - a utility for working with LNFS filesystems");
            programSettings.help();
            System.exit(0);
        }

        var sourceFiles = programSettings.getSourceFiles();
        if(sourceFiles.isEmpty()){
            Logger.error("No source path specified.");
            System.exit(1);
        }else if(sourceFiles.size() > 1){
            Logger.error("Multiple source paths specified. Only one source path is allowed.");
            System.exit(1);
        }

        if(programSettings.get("--pack", Boolean.class)){
            if(programSettings.get("--unpack", Boolean.class)){
                Logger.error("Cannot specify both --pack and --unpack options.");
                System.exit(1);
            }
            mode = RunMode.PACK;
        }else if(programSettings.get("--unpack", Boolean.class)){
            mode = RunMode.UNPACK;
        }else{
            mode = RunMode.PACK;
        }

        if (programSettings.get("--out", String.class).isEmpty()) {
            if(mode == RunMode.UNPACK){
                Logger.error("Must specify --out option when unpacking.");
                System.exit(1);
            }else if(!programSettings.get("--stdout", Boolean.class)){
                programSettings.set("--out", "out.lnfs.bin");
            }
        }
        return mode;
    }

    private static boolean parseArgs(String[] args) {
        programSettings = new ProgramSettings(Main.class.getClassLoader().getResourceAsStream(DEFAULT_SETTINGS_FILE));
        return programSettings.parse(args);
    }

    private enum RunMode{
        PACK,
        UNPACK
    }
}

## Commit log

2023-06-11 Design 2.0 - data bus, address bus - definition of memory addressing - move signals to signals.json - 4 clocks pipeline - new instruction set - lots of other things I swear I'll do single commits fro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
    [opcodes.tsv]
2023-06-12 Upgrade assembler to first v2 spec
    [opcodes.tsv]
2023-06-30 V2: new instruction set
    [opcodes.tsv]
2023-07-25 FLAGS register with interrupt disable
    [opcodes.tsv]
2023-07-26 Interrupt Vector: set to last page; LNASM lexer: bugfix for instruction BRK
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2023-07-27 Interrupts + devices + bug fixes
    [opcodes.tsv]
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2023-07-30 Inc/Dec instructions, ALU can work with constants
    [opcodes.tsv]
2023-07-30 Swap instructions
    [opcodes.tsv]
2023-07-30 Move values out of SS and SP (to RD)
    [opcodes.tsv]
2023-08-02 RA: use two cascading 4-bit shift registers
    [opcodes.tsv]
2023-08-27 Fix compile exceptions printing wrong location for macro expansion
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2023-10-01 Rename ln16081 to v1; add readmes
    [opcodes.tsv]
2023-12-07 Addressing modes signals and circuit, add descriptions to instructions
    [opcodes.tsv]
2023-12-07 Remove indirect paged addressing mode (not in assembler)
    [opcodes.tsv]
2023-12-07 Remove indirect paged mode from assembler
    [opcodes.tsv]
2023-12-09 v1 Digital: AddrSelector (+ change combinations of address selector)
    [opcodes.tsv]
2023-12-25 lnasm: switch to Maven build system
    [opcodes.tsv]
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2024-04-02 v1: add mov_page0_page0 to instruction set
    [opcodes.tsv]
2024-04-30 New FLAG logic, clear/set carry flag instructions
    [opcodes.tsv]
2024-04-30 Remove indirect page0 mode
    [opcodes.tsv]
2024-05-03 v2 linker: parser and ast. Remove ipage0rd addressing
    [opcodes.tsv]
2024-05-16 finish merge in logisim
    [opcodes.tsv]
2024-05-16 v2: correct argument sorting
    [opcodes.tsv]
2024-05-17 notmon_bios: new linker config
    [linker.cfg]
2024-05-17 flags modified in generated docs
    [opcodes.tsv]
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2024-07-15 Add Gemini-generated tests (to be checked)
    [linker.cfg]
2024-07-20 lnasm: fix missing return in lexer switch
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2024-07-25 impl: change lgoto_ircrd to lgoto_rcrd
    [opcodes.tsv]
2024-08-23 finish testing architecture (all pass)
    [opcodes.tsv]
2024-08-24 Add DS register; lnasm v1.4: adapted to new data segment architecture
    [opcodes.tsv]
2024-08-25 tests for DS register, adapt to new architecture
    [linker.cfg]
2024-08-25 update notmon_bios and delete old programs
    [linker.cfg]
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2024-08-27 add tests for int and iret
    [linker.cfg]
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2024-08-27 rename lnasm to lnc; setup to start working on compiler
    [opcodes.tsv]
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2024-12-30 export libraries along with Jar, edit preprocessor to look in lib/ folder
    [linker.cfg]
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2024-12-30 if(n)def section support, error directive in preprocessor
    [linker.cfg]
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2025-06-30 decoder for register in/out, remove datap arithmetic, base for stack frame manipulation
    [opcodes.tsv]
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2025-07-08 refactor: update symbol handling and stack frame management
    [opcodes.tsv]
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2025-07-14 feat: replace swap with short indirect movs
    [opcodes.tsv]
2025-07-15 Fix ird addressing mode
    [opcodes.tsv]
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2025-07-19 regalloc: fix compound register allocation
    [config.cfg]
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2025-08-14 feat: add support for continue target in conditional jumps
    [config.cfg]
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2025-08-15 refactor: rename constant section label for consistency in output generation
    [config.cfg]
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2025-09-07 fix: prevent printing pause message if emulator is terminated
2025-09-08 feat: enhance TTY device handling and improve command line argument validation
    [linker.cfg]
2025-09-09 emu: fix emulation of tty device
    [main.c]
2025-09-22 feat: update KiCad files with new pin configurations and error handling improvements
    [register.kicad_pcb, register.kicad_sch]
2025-09-23 refactor: improve VM instruction handling and flag setting
    - Replace hardcoded `BP` offsets with temporary variable for cleaner code.
    - Update `set_flags` to conditionally set carry and zero flags.
    - Correct logic for `fetch_byte` in several VM instruction cases.
    - Optimize `MOV`, `ADD`, `SUB`, `CMP`, `OR`, and `AND` operations by refining flag logic and offsets handling.
    - Update test assembly to reflect register usage changes (e.g., `RC` to `RD`).
2025-09-23 feat: add `push_ds` and `pop_ds` instructions
    - Implement `push_ds` and `pop_ds` operations in the VM for handling DS register stacking.
    - Extend instruction set configurations in `instructions.json` and `opcodes.tsv` to include new commands.
    - Update VM logic in `vm.c` to support new operations.
    [opcodes.tsv]
2025-09-24 refactor: replace `LT_VIRTUAL` with `LT_INVALID` and streamline TTY device logic
    - Replace `LT_VIRTUAL` with `LT_INVALID` across linker target definitions.
    - Transition TTY emulation setup to use device input (`D0-D5`) instead of section mapping.
    - Implement `vm_read_byte` and `vm_write_byte` for cleaner memory byte operations.
    - Add emulator signature handling in `emu_device` for enhanced compatibility.
    - Update linker configuration parser's default target from `LT_VIRTUAL` to `LT_ROM`.
    - Adjust Logisim circuit file to fix library ordering inconsistencies.
2025-09-25 Add initial implementation of LN-BIOS with I/O and memory utilities
    - Created io.lnasm for I/O operations including text device handling.
    - Added linker configuration in linker.cfg to define memory sections.
    - Implemented main BIOS entry point in main.lnasm with device discovery and initialization.
    - Introduced memory utility functions in mem.lnasm for memory manipulation (memzero, memfill, memcpy, memcmp).
    - Defined compile-time options in opts.lnasm for BIOS behavior.
    - Added BIOS signature section in sign.lnasm for ROM identification.
    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
    [linker.cfg]
2025-09-26 feat: enhance BIOS functionality with status codes and interrupt handling
    [linker.cfg]
2025-09-26 feat: refactor BIOS section names and improve standard text device handling
    [linker.cfg]
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2025-09-26 feat: implement BIOS interrupt handling and device management
    [linker.cfg]
2025-09-27 Update README and add new tests for stack operations
    - Enhanced README.md to include JDK 16+ as a prerequisite and updated instructions for building on Windows.
    - Added new test cases for the `pop DS` operation, including assembly code and expected output.
    - Added new test cases for the `push DS` operation, including assembly code and expected output.
    - Updated Logisim circuit file to correct component library references and adjust component placements for better organization.
    [opcodes.tsv]
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2025-09-27 fix: update component locations and improve disassembler logic
    [opcodes.tsv]
2025-09-28 fix: update flags for bitwise OR opcodes to reflect NZC modification
    [opcodes.tsv]
2025-12-29 add circuits for AT28C64B loader and register, add v1 components library
    [AT28C64B-circuit-first-sol.kicad_pcb, AT28C64B-circuit-second-sol.kicad_pcb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]
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2026-03-15 check designs for ALU (partial), SP, Shift register, register
    [alu.kicad_pcb, alu.kicad_sch, register.kicad_pcb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]
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2026-04-14 feat: refactor preprocessor configuration and enhance member access handling
    [opcodes.tsv]
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2026-05-03 Implement LNFS support and enhance boot process in LN-BIOS
    [linker.cfg]
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2026-05-03 Refactor code structure for improved readability and maintainability
    [opcodes.tsv]
2026-05-04 Add stability tests for lnc compiler and emulator
    - Introduced a comprehensive suite of tests for the lnc compiler, including various arithmetic operations, control flow constructs, function calls, and pointer manipulations.
    - Each test case consists of a source file (`test.lnc`) and a corresponding expectations file (`pass.txt`) to validate the output against expected results.
    - Implemented a test runner script (`run_lnc_tests.py`) to automate the building of the compiler and emulator, execution of tests, and reporting of results.
    - Enhanced the emulator to support expectation checking against the final state of the machine, allowing for more robust testing.
    - Added support for compile-fail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
2026-08-10 Enhance IR and Assembly Optimization Passes
    - Added `isTerminated` method to `IRBlock` to check if the block ends with a Goto or Ret instruction.
    - Refactored `IRGenerator` to utilize new methods for conditional Goto and Continue instructions, improving loop handling.
    - Introduced `LoopRotationPass` to optimize loops by converting unconditional jumps to conditional ones, reducing cycle counts.
    - Implemented `RedundantStackTrafficPass` to eliminate unnecessary stack operations that do not affect program state.
    - Added `StrengthReductionPass` to replace simple increment and decrement operations with more efficient instructions.
    - Enhanced `ConstantFoldingPass` to evaluate and replace constant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
2026-08-11 Add debug server functionality to the emulator
    - Introduced a new debug server that allows remote debugging via a TCP socket.
    - Added command-line options for enabling the debug server and controlling its behavior.
    - Implemented commands for reading and writing memory, setting registers, and managing breakpoints.
    - Enhanced the emulator to support stepping through instructions and pausing execution.
    - Created a test script to validate the debug server's functionality and ensure correct behavior.
    - Added a simple assembly program for testing purposes.
2026-08-15 feat: add support for external device images in launch configuration and update related functionality
    [opcodes.tsv]
2026-08-16 feat: update managed options in validateEmulatorOptions to include additional targets
    [opcodes.tsv]
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2026-08-16 feat: implement lnfs filesystem structure and utility functions
    [linker.cfg]
2026-08-16 Implement register allocation strategies with DFS and greedy approaches
    - Added RegisterAllocationDriver to manage register allocation strategies.
    - Implemented greedy and DFS strategies for register allocation.
    - Introduced metrics for measuring register allocation performance in RegisterAllocationMetrics.
    - Enhanced SpillSlotAssigner to support copying spill slots for snapshots.
    - Modified IRUnit and IRUnitSnapshot to support register allocation snapshots and state restoration.
    - Updated IRBlock to allow setting the associated IRUnit.
    - Added tests for DFS strategy and IRUnitSnapshot functionality to ensure correctness.
    - Updated default settings to include new register allocation configur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
